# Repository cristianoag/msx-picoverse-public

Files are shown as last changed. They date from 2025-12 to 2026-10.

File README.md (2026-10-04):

# PicoVerse for MSX

**The MSX experience driven by the Raspberry Pi Pico family of microcontrollers.**

PicoVerse is a community-driven effort to build versatile MSX cartridges powered by Raspberry Pi Pico development boards. The project pairs accessible hardware designs with ready-to-flash firmware so MSX users can jump straight into loading games, tools, and Nextor without having to compile sources.

| Cartridge Label - 2040 Variant | Cartridge Label - 2350 Variant |
|---|---|
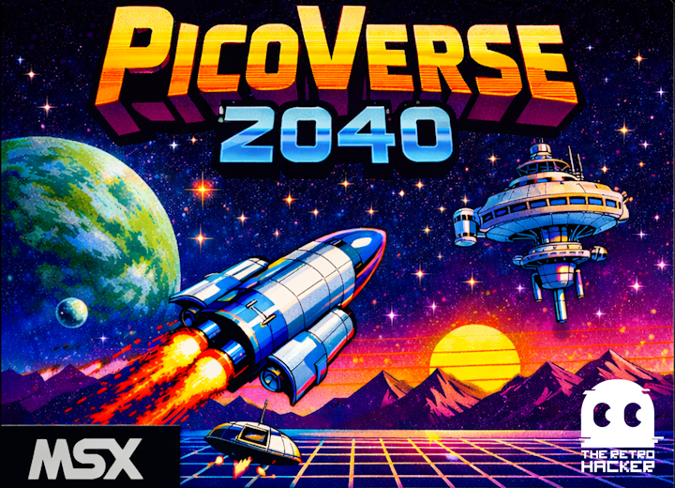
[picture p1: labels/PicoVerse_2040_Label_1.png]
PicoVerse 2040 Label
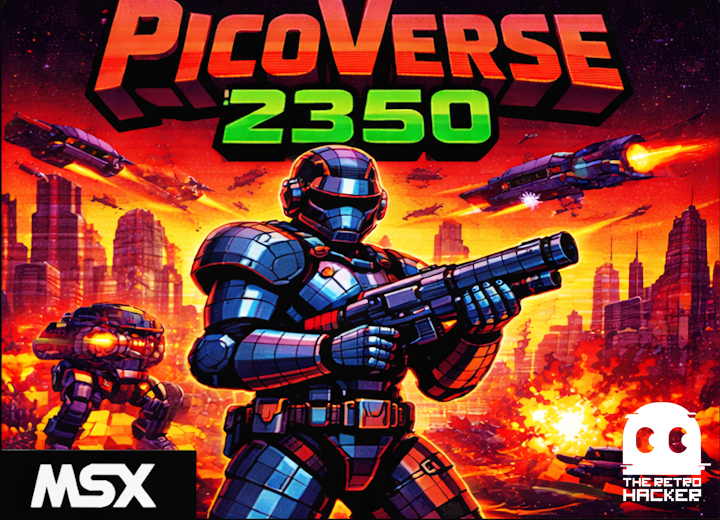
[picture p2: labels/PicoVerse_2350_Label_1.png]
PicoVerse 2350 Label
| |  |

PicoVerse is designed as an open-source, independent, and documented MSX cartridge platform. Compatibility with other projects is neither a goal nor guaranteed (I tested some without much success); running third‑party software on PicoVerse hardware, or PicoVerse firmware on other boards, is at your own risk. The source and manufacturing files are openly available so you can learn, experiment, and build on them for the MSX community, subject to the project license.

If you find any issues, have questions, or want to contribute, please open an issue or reach out via the contact information in the repository.

## Project Highlights

- Single-ROM LoadROM workflow for instant and easy booting of one title.
- Multi-ROM loader with an on-screen menu and mapper auto-detection.
- Explorer firmware (PicoVerse 2350) merges flash ROMs, optional embedded Sunrise Nextor SYSTEM entries, and microSD ROMs, labels the source (FL/SD), adds microSD MP3/WAV playback, supports WAVEGAME microSD ROMs with port `0x92` controlled WAV streaming, supports on-device search, can cycle supported microSD partitions with `P`, can delete selected SD files or flash entries with confirmed `D`, can copy microSD ROMs into the cartridge flash with `F`, can rename ROMs, `.DSK` images and flash entries with `R`, includes ROM detail audio profiles with native and external SCC/SCC+, Dual PSG, MSX-MUSIC, and YM2151/SFG support, adds an independent primary PSG DAC mirror option, and includes an integrated File Hunter browser for downloading ROMs and `.DSK` disk images over ESP-01 WiFi.
- Ready-made Nextor builds with USB pendrive (`-s2`/`-m2`) or FAT16 up-to-4GB microSD partitions (`-s1`/`-m1`) via Sunrise IDE emulation on PicoVerse 2350, and USB (`-s`/`-m`) on PicoVerse 2040.
- Sunrise IDE + 192KB memory mapper on PicoVerse 2040 (`loadrom.exe -m`), or Sunrise IDE standalone (`loadrom.exe -s`).
- Sunrise IDE + 1MB PSRAM memory mapper on PicoVerse 2350 (`loadrom.exe -m1` for microSD, `loadrom.exe -m2` for USB), or Sunrise IDE standalone (`loadrom.exe -s1` / `loadrom.exe -s2`).
- Sunrise IDE + 1MB memory mapper + 1MB MegaRAM on PicoVerse 2350 (`loadrom.exe -r1` / `explorer.exe -r1` for microSD, `loadrom.exe -r2` / `explorer.exe -r2` for USB), exposing 128 × 8KB MegaRAM banks in a dedicated expanded subslot.
- Carnivore2-compatible RAM-mode loader on PicoVerse 2350 (`loadrom.exe -c1` / `loadrom.exe -c2`) for `SROM.COM /D15` uploads into the 1MB PSRAM mapper.
- ESP-01 WiFi support for PicoVerse 2350 Sunrise IDE LoadROM/MultiROM builds (`loadrom.exe -s1 -w`, `-m1 -w`, `-s2 -w`, `-m2 -w`) and for the Explorer File Hunter browser. Compatible with both real MSX hardware and FPGA-based MSX cores.
- SCC/SCC+, Dual PSG, MSX-MUSIC/YM2413, and YM2151/SFG emulation on the PicoVerse 2350, with per-ROM audio profile selection where supported.
- OPL4 / YMF278B / MoonSound emulation on the PicoVerse 2350 (`loadrom.exe -4`) — a standalone sound cartridge with OPL3 FM (18 channels), the 24-voice PCM wavetable, the embedded 2 MB YRW801-M wave ROM, and 2 MB of PCM sample RAM on the standard MoonSound ports.
- MSX-AUDIO / Yamaha Y8950 emulation on the PicoVerse 2350 (`loadrom.exe -a`) — a standalone MSX-AUDIO card with OPL1 FM plus ADPCM, 256 KB of ADPCM sample RAM, and the MSX-Audio BIOS mapped in the cartridge slot.
- Yamanooto flash-cartridge emulation on the PicoVerse 2350 (`yamanooto.exe`) — a Konami-SCC compatible 8 MB flash cartridge with SCC/SCC+, a secondary (dual) PSG, a primary PSG mirror, and MSX-MUSIC/FM-PAC, all always available with the firmware selecting SCC, FM, or pure PSG on the fly so one image can mix SCC, FM, and PSG games.
- PC-side tooling that generates UF2 images locally for quick drag-and-drop flashing.
- openMSX emulated cartridge for PicoVerse 2040 MultiROM — run the same MultiROM `.uf2` in the openMSX emulator before flashing it, with the real PicoVerse menu, the matching ROM mappers, and the embedded Nextor Sunrise IDE entries using a disk image as the USB drive. See [MSX PicoVerse 2040 — MultiROM in openMSX](/docs/msx-picoverse-2040-openmsx.md).
- openMSX emulated cartridge for PicoVerse 2350 Explorer — run an Explorer `.uf2` in openMSX with the real Explorer menu, a PC folder as the microSD card, copy to flash/rename/delete, the Nextor and `.DSK` entries, and the SCC/SCC+, MSX-MUSIC, SFG and Dual PSG audio profiles. See [MSX PicoVerse 2350 — Explorer in openMSX](/docs/msx-picoverse-2350-openmsx.md).
- USB keyboard support on PicoVerse 2040 — use a standard USB keyboard as the MSX keyboard via the cartridge slot.
- MSX-MIDI support on PicoVerse 2040 — use a USB-MIDI cable as a standard MSX-MIDI interface via the cartridge slot. 
- MIDI-PAC support on PicoVerse 2040 — passively convert live MSX PSG music and effects into high-quality MIDI for external synths or sound modules (SC-55 optimized). Features automatic bass detection, tone+noise coexistence, smooth pitch bending on fast passages, and improved percussion mapping. 
- USB joystick support on PicoVerse 2040 — plug a standard USB gamepad (HID, Xbox 360, Xbox One, or Xbox Series X|S) into the USB-C port and it appears as one or two native MSX joysticks with no MSX-side software needed. Uses open-drain bus driving to coexist with the real PSG.
- BOMs, and production-ready Gerbers.
- Active development roadmap covering RP2040 and RP2350-based cartridges.

## Documentation

**LoadROM Guides:** Use the LoadROM tool to create a UF2 image that boots directly into a single ROM, skipping the menu. Mapper type is auto-detected with filename tag overrides, and the tool reports the detected configuration before flashing.
- [MSX PicoVerse 2040 LoadROM Tool Manual (English)](/docs/msx-picoverse-2040-loadrom-tool-manual.en-us.md) 
- [MSX PicoVerse 2350 LoadROM Tool Manual (English)](/docs/msx-picoverse-2350-loadrom-tool-manual.en-us.md) 
  
**MultiROM Guides:** Use the MultiROM tool to create a UF2 image that allows selecting from multiple ROMs at boot. Mapper type is auto-detected with filename tag overrides, and the tool reports the detected configuration before flashing.
- [PicoVerse 2040 MultiROM Guide Manual (English)](/docs/msx-picoverse-2040-multirom-tool-manual.en-us.md)
- [PicoVerse 2350 MultiROM Tool Manual (English)](/docs/msx-picoverse-2350-multirom-tool-manual.en-us.md)

**openMSX Emulated Cartridge:** Try a PicoVerse 2040 MultiROM or PicoVerse 2350 Explorer UF2 in the openMSX emulator before flashing it. A Tcl script and an openMSX extension turn the `.uf2` into an emulated PicoVerse cartridge: the MSX boots the real menu, starts each entry with the matching openMSX hardware, and runs the Nextor Sunrise IDE entries with a hard disk image as the USB drive or microSD card. The Explorer add-on also uses a PC folder as the microSD card.
- [MSX PicoVerse 2040 — MultiROM in openMSX (English)](/docs/msx-picoverse-2040-openmsx.md)
- [MSX PicoVerse 2350 — Explorer in openMSX (English)](/docs/msx-picoverse-2350-openmsx.md)

**Explorer Guides:** Use the Explorer tool to manage flash, embedded Sunrise Nextor, and microSD ROMs, boot 360 KB/720 KB `.DSK` disk images (and multi-disk games joined into one `.DSK`, swapped with the number keys) from the microSD card, cycle supported microSD partitions, delete selected SD files or flash entries, copy microSD ROMs to flash, rename ROMs and disk images, play MP3/WAV files from the microSD card, browse File Hunter over ESP-01 WiFi, select ROM audio/PSG options, and search for titles on the device.
- [MSX PicoVerse 2350 Explorer Tool Manual (English)](/docs/msx-picoverse-2350-explorer-tool-manual.en-us.md)

**Yamanooto Guides:** Use the Yamanooto tool to create a UF2 that emulates a Yamanooto flash cartridge (Konami-SCC compatible, SCC/SCC+, dual PSG, primary PSG mirror, and MSX-MUSIC/FM-PAC) from a single ROM image, with the firmware choosing SCC/FM/PSG automatically at runtime.
- [MSX PicoVerse 2350 Yamanooto Tool Manual (English)](/docs/msx-picoverse-2350-yamanooto-tool-manual.en-us.md)

**Reference Material** 
- [PicoVerse 2040 Features Overview](/docs/msx-picoverse-2040-features.md)
- [PicoVerse 2350 Features Overview](/docs/msx-picoverse-2350-features.md)
- [MSX PicoVerse 2350 Dual PSG Implementation](/docs/msx-picoverse-2350-dualpsg.md)
- [MSX PicoVerse 2350 MSX-MUSIC/FM-PAC Implementation](/docs/msx-picoverse-2350-fmpac.md)
- [MSX PicoVerse 2350 50/60Hz CPU Speed Implementation](/docs/msx-picoverse-2350-50-60hz.md) 
- [MSX PicoVerse 2350 CPU Speed Implementation](/docs/msx-picoverse-2350-cpu-speed.md)
- [MSX PicoVerse 2350 Yamanooto Implementation](/docs/msx-picoverse-2350-yamanooto.md)
- [MSX PicoVerse 2350 MegaRAM Implementation](/docs/msx-picoverse-2350-megaram.md)
- [MSX PicoVerse 2350 WAVEGAME Protocol and Support](/docs/msx-picoverse-2350-wavegame.md)
- [MSX PicoVerse 2350 WiFi Support](/docs/msx-picoverse-2350-wifi.md)
- [MSX PicoVerse 2040 PIO Strategy](/docs/msx-picoverse-2040-pio.md) 
- [MSX PicoVerse 2350 PIO Strategy](/docs/msx-picoverse-2350-pio.md) 
- [MSX PicoVerse 2350 SCC Emulation](/docs/msx-picoverse-2350-scc.md)
- [MSX PicoVerse 2040 Sunrise IDE Emulation for Nextor](/docs/msx-picoverse-2040-sunrise-nextor.md) 
- [MSX PicoVerse 2350 Sunrise IDE Emulation for Nextor](/docs/msx-picoverse-2350-sunrise-nextor.md) 
- [MSX PicoVerse 2350 DSK Disk Image Support](/docs/msx-picoverse-2350-dsk-support.md)
- [MSX PicoVerse 2040 Mapper Implementation (Sunrise + Nextor)](/docs/msx-picoverse-2040-mapper.md) 
- [MSX PicoVerse 2040 USB Keyboard](/docs/msx-picoverse-2040-keyboard.md)
- [MSX PicoVerse 2040 MSX-MIDI](/docs/msx-picoverse-2040-msx-midi.md) 
- [MSX PicoVerse 2040 MIDI-PAC](/docs/msx-picoverse-2040-midipac.md)
- [MSX PicoVerse 2040 MegaROMs](/docs/msx-picoverse-2040-megaroms.md)
- [MSX PicoVerse 2040 USB Joystick](/docs/msx-picoverse-2040-joystick.md)

## Hardware Variants

### PicoVerse 2040 Cartridge

| Prototype PCB (front) | Prototype PCB (back) |
|---|---|
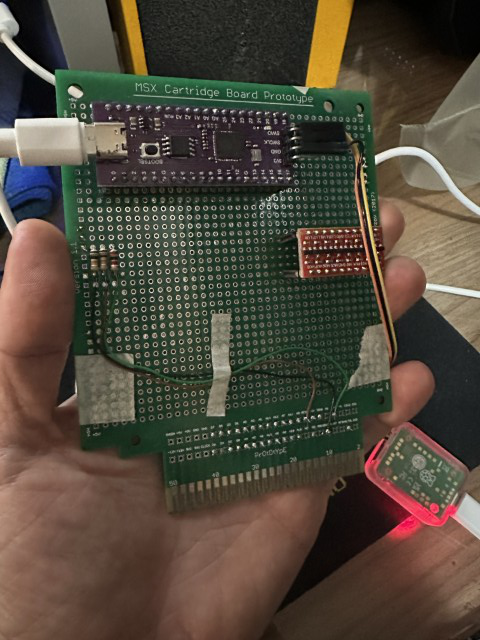
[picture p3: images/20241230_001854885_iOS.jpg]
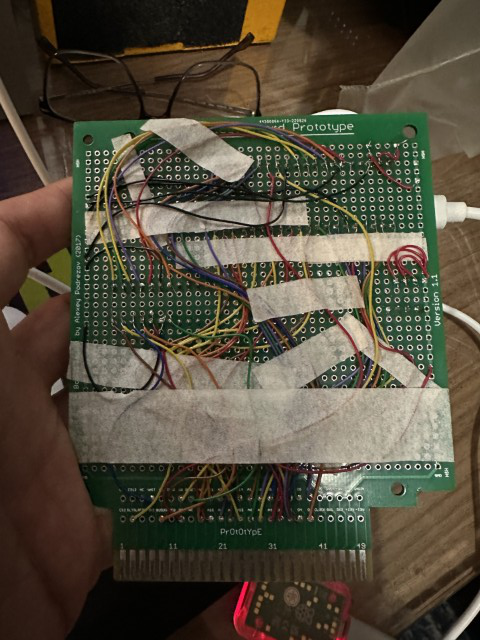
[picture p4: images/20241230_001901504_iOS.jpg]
|  |  | 

- Based on RP2040 boards exposing 30 GPIO pins (not compatible with stock Raspberry Pi Pico pinout).
- Up to 16 MB of flash for MSX ROMs with support for Plain16/32 (`PLA-16`/`PLA-32`), Planar48/64 (`PLN-48`/`PLN-64`), Konami SCC, Konami, ASCII8/16/16X, NEO-8, NEO-16, and Manbow2 (`MANBW2`) mappers.
- USB-C port doubles as a bridge for Nextor mass storage via Sunrise IDE emulation (`loadrom.exe -s`).
- Sunrise IDE + 192KB memory mapper mode provides both Nextor disk access and expanded RAM (`loadrom.exe -m`).
- Standalone USB keyboard firmware — use a standard USB keyboard as the MSX keyboard via the cartridge slot (`loadrom.exe -k`). Not compatible with FPGA-based MSX systems or MSX computers with an integrated PPI (e.g. T9769 MSX-ENGINE).
- Standalone MSX-MIDI firmware — use a USB-MIDI cable as a standard MSX-MIDI interface for MIDI players and sequencers (`loadrom.exe -i`).
- Standalone MIDI-PAC firmware — passively listen to the MSX PSG and convert music and effects to USB MIDI for an external synth or sound module (`loadrom.exe -p`).
- Standalone USB joystick firmware — use a standard USB gamepad as an MSX joystick via the cartridge slot (`loadrom.exe -j`). Supports Xbox 360, Xbox One, Xbox Series X|S, and generic USB HID gamepads, with up to 2 gamepads mapped to MSX joystick ports 1 and 2.  Not compatible with FPGA-based MSX systems or MSX computers with an integrated PSG (e.g. T9769 MSX-ENGINE).

#### Bill of Materials



Interactive BOM available at [PicoVerse 2040 BOM](https://htmlpreview.github.io/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)

| Reference | Description | Quantity | Link |
| --- | --- | --- | --- |
| U1 | RP2040 Dev Board 30 GPIO pins exposed | 1 | [AliExpress](https://s.click.aliexpress.com/e/_c2un4bmn) |
| C1 | 0603 0.1 µF Ceramic Capacitor | 1 | [AliExpress](https://s.click.aliexpress.com/e/_c2w5e36V) |
| C2 | 0603 10 µF Ceramic Capacitor | 1 | [AliExpress](https://s.click.aliexpress.com/e/_c2w5e36V)|
| R2, R3, R4, R5, R6, R7, R8, R9, R10, R11, R12, R13| 0603 10 kΩ Resistor | 12 | [AliExpress](https://s.click.aliexpress.com/e/_c3XBv4od)|
| R1 | 0603 2 KΩ Resistor | 1 | [AliExpress](https://s.click.aliexpress.com/e/_c3XBv4od)|
| D1 | 1N5819 SOD-123 Diode | 1 | [AliExpress](https://s.click.aliexpress.com/e/_c4WEKCuz) |
| Q1, Q2, Q3, Q4, Q5 | BSS138 SOT-23 Transistor | 5 | [AliExpress](https://s.click.aliexpress.com/e/_c3IHdO5t)|

### PicoVerse 2350 Cartridge

| Prototype PCB (front) | Prototype PCB (back) |
|---|---|
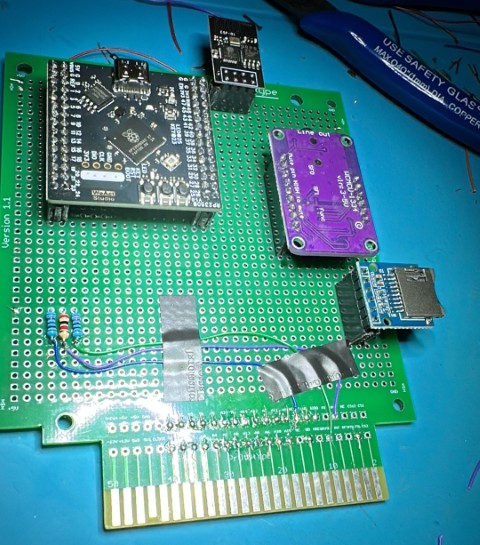
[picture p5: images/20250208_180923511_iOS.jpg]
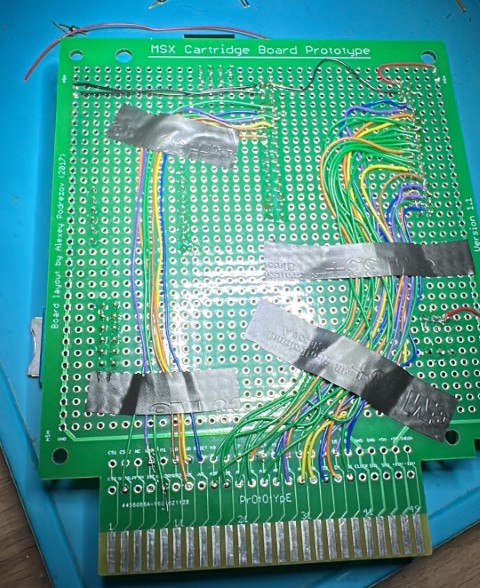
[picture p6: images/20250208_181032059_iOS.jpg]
|  |  |

- Targets RP2350 boards exposing all 48 GPIO pins (not compatible with standard Pico 2 boards).
- Adds microSD storage, ESP8266 WiFi header, and I2S audio expansion alongside 16 MB flash space.
- Extra RAM (PSRAM) now backs the 1MB mapper modes and the Carnivore2-compatible RAM loader, with room for additional advanced firmware features.
- Explorer firmware can load ROMs from flash, optional embedded Sunrise Nextor SYSTEM entries, and microSD, cycle FAT16/FAT32/exFAT microSD browsing partitions with `P`, delete selected SD files or flash entries after confirmation with `D`, copy microSD ROMs into flash with `F`, rename ROMs, `.DSK` images and flash entries with `R`, play MP3/WAV files from microSD, browse File Hunter over ESP-01 WiFi, save downloaded File Hunter ROMs and `.DSK` disk images to the microSD root, search local title lists, select native or external SCC/SCC+, Dual PSG, MSX-MUSIC, or YM2151/SFG audio profiles per ROM where supported, and optionally mirror primary PSG audio through the cartridge DAC.
- USB-C port doubles as a bridge for Nextor mass storage via Sunrise IDE emulation (`-s2`).
- microSD card slot provides Nextor mass storage via Sunrise IDE emulation (`-s1`) when using FAT16 partitions up to 4 GB.
- Sunrise IDE + 1MB PSRAM memory mapper mode provides both Nextor disk access and expanded RAM (`-m1` for microSD, `-m2` for USB).
- Sunrise IDE + 1MB mapper + 1MB MegaRAM mode provides Nextor disk access, standard mapper RAM, and a separate writable MegaRAM cartridge surface (`-r1` for microSD, `-r2` for USB).
- Carnivore2-compatible RAM-mode loading lets `SROM.COM /D15` upload ROMs into the 1MB PSRAM mapper (`-c1` for microSD, `-c2` for USB).
- Yamanooto flash-cartridge emulation (`yamanooto.exe`) reproduces the  Yamanooto: a Konami-SCC compatible 8 MB flash cartridge with SCC/SCC+, a secondary (dual) PSG on ports `0x10`/`0x11`, a primary PSG mirror (`0xA0`/`0xA1`), and MSX-MUSIC/FM-PAC via an expanded subslot. All engines are always available and the firmware selects SCC, FM, or pure PSG on the fly, so a single image can hold a mix of SCC, FM, and PSG games.
- Standalone OPL4 / YMF278B / MoonSound cartridge firmware (`loadrom.exe -4`): full YMF278B emulation (OPL3 FM with 18 channels plus 24 PCM voices), the 2 MB YRW801-M wave ROM embedded in the UF2, 2 MB of PCM sample RAM in PSRAM, MoonSound ports `0xC4`-`0xC7` and `0x7E`/`0x7F`, FM timer interrupts on `/INT`, and 16-bit stereo 44.1 kHz output through the I2S DAC. Optional `--22khz` reduced-rate build for extreme-polyphony songs.
- Standalone MSX-AUDIO / Yamaha Y8950 cartridge firmware (`loadrom.exe -a`): OPL1 FM (9 channels) plus ADPCM-B, 256 KB of ADPCM sample RAM in PSRAM, the 48 KB MSX-Audio BIOS v1.3 mapped in the slot (openMSX `Boosted_audio.xml` layout, with base and expanded work RAM), ports `0xC0`/`0xC1`, FM timer interrupts on `/INT`, and 16-bit 49716 Hz output through the I2S DAC. Optional `--4mhz` Y8950 clock.
- LoadROM Sunrise builds can also expose ESP-01 WiFi support with `-w` on top of the `-s1`/`-m1`/`-s2`/`-m2` modes.
- LoadROM, MultiROM, and Explorer support the Sunrise IDE options. MultiROM and Explorer allow combining them so multiple Nextor modes appear as selectable SYSTEM entries in the menu, and both provide `-a` / `--allnextor` to add all embedded Nextor entries while still appending folder ROMs. All three also offer `-s3` for testing the Nextor 3.0.0 Beta 2 kernel over microSD.
- Shares the same ROM mapper support list as the 2040 build.

#### Bill of Materials



Interactive BOM available at [PicoVerse 2350 BOM](https://htmlpreview.github.io/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) 

| Reference | Description | Quantity | Link |
| --- | --- | --- | --- |
| U1 | WaveShare Core2350B Dev Board 48 GPIO pins exposed (8Mb PSRAM)| 1 | [AliExpress](https://pt.aliexpress.com/item/1005009578742534.html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) |
|U2| UDA1334A I2S Stereo DAC| 1 | [AliExpress](https://s.click.aliexpress.com/e/_c3gam5lH) |
|U3| ESP-01 ESP8266 WiFi Module| 1 | [AliExpress](https://s.click.aliexpress.com/e/_c3cPt2OL) |
|C1| 0603 0.1 µF Ceramic Capacitor | 1 | [AliExpress](https://s.click.aliexpress.com/e/_c3tkUxHz) |
|C2,C3| 0603 10 µF Ceramic Capacitor | 2 | [AliExpress](https://s.click.aliexpress.com/e/_c3tkUxHz)|
|R1| 0603 2 KΩ Resistor | 1 | [AliExpress](https://s.click.aliexpress.com/e/_c43uKcEj)|
|R2, R3, R6, R7, R8| 0603 10 kΩ Resistor | 4 | [AliExpress](https://s.click.aliexpress.com/e/_c43uKcEj)|
|R4, R5| 0603 5.1 kΩ Resistor | 2 | [AliExpress](https://s.click.aliexpress.com/e/_c43uKcEj)|
|R9, R10| 0603 330 Ω Resistor | 2 | [AliExpress](https://s.click.aliexpress.com/e/_c43uKcEj)|
|D1| 1N5819 SOD-123 Diode | 1 | [AliExpress](https://s.click.aliexpress.com/e/_c4WEKCuz) |
|SW1| Tactile Push Button Switch | 1 | [AliExpress](https://s.click.aliexpress.com/e/_c2IPGkzv) |
|J1| USB-C 16 Pin Connector | 1 | [AliExpress](https://s.click.aliexpress.com/e/_c4PtBc51) |
|J2| microSD Card Slot | 1 | [AliExpress](https://s.click.aliexpress.com/e/_c4Pzbd7Z) |

## Repository Contents
- `hardware/` – Production-ready Gerbers, fabrication notes, and BOMs for each supported dev board.
- `software/` – MultiROM PC utilities (`multirom.exe`) and menu ROM assets for both cartridge families.
- `docs/` – Feature lists, usage walkthroughs, and revision history for each cartridge family.
- `images/` – Board renders and build photos for quick identification.
- `labels/` – Printable Patola style cartridge label designs for both hardware variants.

## Quick Start
1. **Pick your target board**: Select the hardware revision that matches the RP2040 or RP2350 carrier you own, then grab the corresponding Gerber/BOM pack.
2. **Manufacture or assemble**: Send the Gerbers to your PCB house or build from an ordered kit. Follow the assembly notes included in each hardware bundle.
3. **Generate the UF2 image**:
   - For multiple titles, place your `.rom` files beside the MultiROM tool for your cartridge family (`2040/software/multirom.pio/tool/multirom.exe` or `2350/software/multirom.pio/tool/multirom.exe`) and run `multirom.exe` to create `multirom.uf2`.
   - For an instant boot into a single game, place the desired `.rom` next to the LoadROM tool for your cartridge family and run `loadrom.exe <file> [-o custom.uf2]` to create a dedicated UF2 that skips the menu.
   - For a combined flash + microSD menu (on PicoVerse 2350 only), use the Explorer tool (`2350/software/explorer.pio/tool/explorer.exe`) to create `explorer.uf2`. Add options such as `-s1`, `-m1`, `-r1`, `-s2`, `-m2`, `-r2`, or `-a` / `--allnextor` when you want embedded Nextor SYSTEM entries in the same Explorer menu, then copy extra `.rom` and `.mp3` files to the microSD card. With an ESP-01 module and configured WiFi, Explorer can also browse File Hunter and save downloaded ROMs directly to the microSD root.
4. **Flash the firmware**:
   - Hold BOOTSEL while connecting the cartridge to your PC via USB-C.
   - Copy the freshly generated UF2 (`multirom.uf2`, `loadrom.uf2`, or `explorer.uf2`) to the RPI-RP2 drive that appears.
   - Eject the drive; the board reboots and stores the image in flash.
5. **Enjoy on MSX**: Insert the cartridge, power on the computer, pick a ROM from the menu, or launch Nextor to access USB or microSD storage.

## MultiROM Menu

| PicoVerse 2040 MultiRom | PicoVerse 2350 MultiRom |
|---|---|
|PicoVerse 2040 MultiROM menu|PicoVerse 2350 MultiROM menu|

To use the MultiROM menu, insert the PicoVerse cartridge into your MSX and power it on. The system will boot directly into the MultiROM menu, which displays a list of all ROMs embedded in the cartridge. Each entry is named after the ROM filename (up to 50 characters), and longer names are shown using a scrolling effect.

Navigate the menu using the keyboard arrow keys. Use the Up and Down keys to move through the list of ROMs, and if more than 19 ROMs are present, use the Left and Right keys to switch between pages. To start a game or application, select it and press Enter or Space; the MSX will boot the ROM using the appropriate mapper configuration automatically.

While in the menu, pressing a letter key jumps to the first ROM whose name starts with that letter, and pressing F1 opens a help screen with basic instructions; press any key to return to the main menu. Once a ROM is launched, control is handed over entirely to the selected software, just as if it were a physical cartridge inserted into the MSX.

Check the detailed MultiROM guide in the documentation folder for advanced features, troubleshooting tips, and mapper support details.

You can also try a PicoVerse 2040 MultiROM UF2 in the openMSX emulator before flashing it: the emulated cartridge boots the same menu from the `.uf2` file. See [MSX PicoVerse 2040 — MultiROM in openMSX](/docs/msx-picoverse-2040-openmsx.md).

## LoadROM Tool

The LoadROM tool targets situations where you want the PicoVerse to behave like a traditional single-game cartridge or as a dedicated standalone firmware image. Instead of showing the MultiROM menu, the Pico boots straight into one ROM embedded in the UF2 image, or into a selected standalone mode such as keyboard, MSX-MIDI, MIDI-PAC, or USB joystick.

- **Input**: exactly one `.ROM` file. Mapper type is auto-detected with the same heuristics as MultiROM, and you can still force a mapper via filename tags such as `.KonSCC.ROM` or `.PLA-32.ROM`.
- **Output**: `loadrom.uf2` by default, or any filename you pass via `-o`. The UF2 contains the firmware, a 59-byte configuration record (title, mapper, size, flash offset), and the ROM payload.
- **Workflow**:
   1. Open a Command Prompt or PowerShell window in your target package folder:
      - `2040/software/loadrom.pio/tool`, or
      - `2350/software/loadrom.pio/tool`.
   2. Run `loadrom.exe -o mygame.uf2 \\path\\to\\Game.ROM` (the tool also accepts drag-and-drop onto the EXE).
      - MSX-MIDI standalone mode: `loadrom.exe -i -o midi.uf2`
      - MIDI-PAC standalone mode: `loadrom.exe -p -o midipac.uf2`
      - USB joystick standalone mode: `loadrom.exe -j -o joystick.uf2`
      - SCC standard emulation (only PicoVerse 2350): `loadrom.exe -scc \\path\\to\\Game.ROM`
      - SCC+ enhanced emulation (only PicoVerse 2350): `loadrom.exe -sccplus \\path\\to\\Game.ROM`
      - MSX-MUSIC/FM-PAC emulation with the bundled English FM-PAC BIOS (only PicoVerse 2350, non-SYSTEM ROMs): `loadrom.exe -f \\path\\to\\Game.ROM`, `loadrom.exe -fmpac \\path\\to\\Game.ROM`, or `loadrom.exe --fmpac -o mygame-fmpac.uf2 \\path\\to\\Game.ROM`
      - Dual PSG emulation on secondary PSG ports `0x10`/`0x11` (only PicoVerse 2350, supported non-SYSTEM ROMs): `loadrom.exe -d \\path\\to\\Game.ROM` or `loadrom.exe --dual-psg -o mygame-dualpsg.uf2 \\path\\to\\Game.ROM`
      - `-scc` and `-sccplus` are mutually exclusive.
      - `-scc`, `-sccplus`, `-f` / `-fmpac`, and `-d` / `--dual-psg` are cartridge audio modes; use only one of them per UF2.
      - `-f` / `-fmpac` is not valid with Sunrise, Carnivore2, or MegaRAM system modes (`-s1`, `-m1`, `-s2`, `-m2`, `-c1`, `-c2`, `-r1`, or `-r2`) or with Konami SCC / Manbow2 mapper ROMs.
      - `-d` / `--dual-psg` is intended for software that writes to a second PSG. It is not available for Konami SCC or Manbow2 mapper ROMs, SCC/SCC+ audio builds, Sunrise/Nextor system modes, Carnivore2 system modes, or MegaRAM system modes.
      - Sunrise IDE standalone (PicoVerse 2040): `loadrom.exe -s`
      - Sunrise IDE + 192KB mapper (PicoVerse 2040): `loadrom.exe -m`
      - Sunrise IDE standalone (PicoVerse 2350): `loadrom.exe -s1` or `loadrom.exe -s2`
      - Nextor 3.0.0 Beta 2 for testing (PicoVerse 2350, microSD): `loadrom.exe -s3`
      - Sunrise IDE + 1MB PSRAM mapper (PicoVerse 2350): `loadrom.exe -m1` or `loadrom.exe -m2`
      - Sunrise IDE + 1MB PSRAM mapper + 1MB MegaRAM (PicoVerse 2350): `loadrom.exe -r1` or `loadrom.exe -r2`
      - Sunrise IDE + WiFi (PicoVerse 2350): `loadrom.exe -s1 -w`, `loadrom.exe -s2 -w`, `loadrom.exe -m1 -w`, or `loadrom.exe -m2 -w`
      - Carnivore2-compatible RAM loader (PicoVerse 2350): `loadrom.exe -c1` or `loadrom.exe -c2`
      - OPL4 / MoonSound standalone cartridge (PicoVerse 2350, no ROM file): `loadrom.exe -4`, optionally with `--22khz`
      - MSX-AUDIO / Y8950 standalone cartridge (PicoVerse 2350, no ROM file): `loadrom.exe -a`, optionally with `--4mhz`
      - `-4` and `-a` are standalone builds: they take no ROM file and cannot be combined with each other or with any other mode or audio flag.
      - `-w` is currently supported only with `-s1`, `-m1`, `-s2`, `-m2`, or `-s3`.
   3. Observe the reported ROM name, size, mapper status (auto vs forced), and Pico offset before the UF2 is written.
   4. Put the Pico into BOOTSEL mode and copy the generated UF2 to the `RPI-RP2` drive.
   5. Insert the cartridge into your MSX—on power-up the embedded game launches immediately.

Consult the LoadROM manuals linked above for screenshots, troubleshooting, and in-depth explanations of mapper forcing, UF2 structure, and limitations.

## Explorer Firmware (RP2350)

|Explorer Flash Menu|Explorer MicroSD Menu|
|---|---|
|Explorer flash menu|Explorer microSD menu|
|<center>**File Hunter Explorer Menu**|<center>**WiFi Configuration Screen**|
|File Hunter Explorer menu|WiFi configuration screen|

Explorer is a PicoVerse 2350-only firmware that merges ROMs stored in flash, optional embedded Sunrise Nextor SYSTEM entries, and additional ROMs and MP3/WAV files on the microSD card. ROMs are labeled with source tags (FL/SD), MP3 and WAV entries open a player screen with Play/Stop and Pause/Resume controls, the list supports paging, and you can search by name directly in the menu. Explorer can add individual Nextor entries with `-s1`, `-m1`, `-c1`, `-r1`, `-s2`, `-m2`, `-c2`, or `-r2`, or add all of them with `-a` / `--allnextor`, while still appending supported folder ROMs to the UF2. For early testing of Nextor 3, `-s3` adds a `Nextor Sunrise 3.0.0 Beta 2 (SD)` microSD entry (also included by `-a`). In the `F2` microSD screen, `P` cycles supported FAT16, FAT32, and exFAT browsing partitions, while `D` deletes the selected file after confirmation (folders are protected) and `F` copies the selected ROM into the cartridge flash, where it then appears in the `F1` list; `D` in the `F1` flash screen removes a flash entry. `R` renames the selected ROM, `.DSK` image or flash entry; on the microSD card the mapper tag and extension of the file name are kept. With an ESP-01 / ESP8266 module installed and WiFi configured, pressing `F3` opens the integrated File Hunter browser. File Hunter results show the name and size, can be searched from the MSX, and `T` switches between the ROM and `.DSK` catalogs. Selected ROMs and disk images are downloaded through the Pico into PSRAM before being saved as `.ROM` or `.DSK` files in the microSD root. microSD ROMs up to 4 MB can be executed directly from there. Use the Explorer tool to build the UF2 and copy extra ROMs and audio files to the microSD card. See the Explorer manual for limits, File Hunter requirements, and supported formats.

For Sunrise Nextor SYSTEM entries in Explorer, SD storage is limited to FAT16 microSD partitions up to 4 GB. If more than one compatible partition exists, choose the desired one from the ROM detail screen's `SD Part` option; Explorer saves that selection in the ROM's `.PVC` options file. FAT32 and exFAT partitions remain supported for normal Explorer file browsing but are not offered to Nextor. Nextor entries always show the Nextor version in the menu, for example `Nextor Sunrise 2.1.4 (SD)` or `Nextor Sunrise 2.1.4 + 1MB Mapper (USB)`.

Starting with Explorer v2.52, the menu also lists `.DSK` floppy disk images found on the microSD card, with the `DSK` type label, and can boot the MSX from them. The image is loaded into the cartridge's PSRAM and served to the MSX as the disk of an emulated Sunrise IDE interface. That interface runs the Nextor Sunrise 2.1.4 kernel, which every Explorer UF2 now embeds as a hidden payload, so no extra build option is needed. Disks with an MSX-DOS 1 boot sector start in MSX-DOS 1 mode automatically. Game saves and other disk writes are written straight through to the `.DSK` file on the card.

Multi-disk games are supported since Explorer v2.53 by joining their disks, in order, into one `.DSK` file (for example `copy /b "GAME (Disk 1).DSK" + "GAME (Disk 2).DSK" GAME.DSK`). Explorer finds the disks inside the file and boots disk 1 in Nextor's disk emulation mode. When the game asks for another disk, press that disk's number key (`1`–`9`, then `A`–`W`), for example `2` + `SPACE` for "insert disk 2 and press space". Current limitations:
- The file size must be a multiple of 360 KB (360 KB and 720 KB disks), up to 11 × 360 KB or 5 × 720 KB + 360 KB.
- Multi-disk files always boot MSX-DOS 1. Press the disk key when the game asks for the disk, not while it is loading.
- No floppy controller is emulated, so copy-protected disks and software that programs the FDC directly will not work.
- Nextor uses more RAM than a plain disk ROM. On machines with little RAM (for example a 64 KB MSX2+ such as the Panasonic FS-A1FX), turn on the DSK entry's `1MB Mapper` option to boot it with Nextor plus the 1 MB PSRAM memory mapper.
- An image boots read-only if the file is marked read-only or is split into more than 16 fragments on the card.
- DSK entries offer PSG Mirror, `1MB Mapper`, and the same cartridge audio profiles as the Nextor Sunrise entries. Since v2.55: **External SCC** / **External SCC+** and **MSX-MUSIC**. Since v2.56: **YM2164 SFG05** / **YM2151 SFG01** (and their 4 MHz variants) and **Dual PSG**. The SCC, FM-PAC and SFG appear as a virtual cartridge in expanded subslot 2; Dual PSG uses I/O ports `10h`/`11h`.

See [MSX PicoVerse 2350 DSK Disk Image Support](/docs/msx-picoverse-2350-dsk-support.md) for the full design, the multi-disk layout, the write-through details, and the test matrix.

You can have up to 1024 entries per folder view (folders + ROMs + DSKs + MP3s; the root view can also include flash entries). The menu auto-detects whether the MSX supports 80-column text mode and boots accordingly; you can also press `C` at any time to toggle between 40- and 80-column layouts.

Explorer ROM entries open a detail screen where you can inspect mapper detection, choose a cartridge audio profile, and toggle **PSG** mirroring. Konami SCC and Manbow2 ROMs can use SCC/SCC+ profiles. For other supported non-SYSTEM ROMs, select **Dual PSG** to enable the second cartridge-side PSG on ports `0x10` and `0x11`, **MSX-MUSIC** to enable YM2413/FM-PAC audio, external **SCC/SCC+** to expose a virtual SCC cartridge in another subslot, or **YM2151 (SFG05/SFG01)** to expose a virtual Yamaha SFG-style YM2151 cartridge in a secondary subslot while the game mapper remains active. Supported Sunrise Nextor SYSTEM entries can also select external **SCC/SCC+** or **YM2151 (SFG05/SFG01)**; Explorer keeps Nextor storage and mapper RAM availability intact and places the added cartridge surface in a free expanded subslot. MegaRAM Nextor entries reserve their expanded layout for Nextor, mapper RAM, and MegaRAM, so WiFi and the external SCC/SCC+, Dual PSG and YM2151 profiles are not offered for those entries; PSG Mirror and MSX-MUSIC remain available. Set **PSG: Yes** to also mirror the normal primary PSG ports `0xA0`/`0xA1` through the cartridge DAC; this primary PSG mirror can be mixed with SCC/SCC+, Dual PSG, MSX-MUSIC, YM2151/SFG, or WAVEGAME WAV playback. When **Dual PSG** and **PSG: Yes** are enabled together, Explorer routes Dual PSG to the left channel and the mirrored primary PSG to the right channel. Explorer hides cartridge audio profiles where the cartridge audio slot is reserved, including folders and File Hunter folder records.

WAVEGAME support is available for microSD-launched game ROMs that keep their audio sidecars in the same folder. The running MSX game writes one-byte commands to I/O port `0x92`; Explorer captures those writes while serving the ROM and streams `NN.wav`, `multi.wav`, or `pause.wav` files from the microSD card through the I2S DAC. The protocol supports stop/fade-out, play once, loop, pause toggle, pause music, previous-song resume with fade-in, deferred next-command playback, optional per-song `.cfg` sample offsets, and `multi.wav` fallback offsets. WAVEGAME titles should use 48 kHz mono 16-bit PCM WAV files. When Explorer detects WAVEGAME sidecars next to a ROM, cartridge audio profiles are forced to `None` because they are incompatible with the WAVEGAME streaming path; the separate **PSG Mirror** option remains available and is mixed into the WAVEGAME WAV output.

A search function is available by pressing `/` in the menu. Type part of a ROM name and press Enter to jump to the first matching entry. Press `H` to view the help screen.

The File Hunter browser was implemented with reference to NataliaPC's public MSX File Hunter Browser project: https://github.com/nataliapc/msx_filehunterbrowser

## Compatibility & Requirements

- Works with MSX, MSX2, MSX2+, and MSX TurboR systems. Mapper support covers the most common game and utility formats.
- Requires Windows OS to run the PC-side UF2 builder utilities.
- Ensure your development board matches the pinout documented for each hardware revision before soldering.

## License, Copyright notes & Usage

Creative Commons Attribution-NonCommercial-ShareAlike 4.0

All hardware and firmware binaries in this repository are released under the Creative Commons Attribution-NonCommercial-ShareAlike 4.0 International license. Personal builds and community tinkering are encouraged, but **commercial use or resale requires explicit authorization from the author**.

**bios.h** is used on all MSX menus and was adapted from http://www.konamiman.com/msx/msx2th/th-ap.txt by Danilo Angelo, 2020. The original file is licensed under CC0 1.0 Universal (public domain). The adapted bios.h file in this repository is also released under CC0 1.0 Universal, allowing for free use and modification without restrictions.

**msxromcrt0.s** is used on Nextor C implementation and was adapted by S0urceror, 2022, from the crt0.s file available in FusionC v2.0. The original crt0.s file is licensed under the MIT License. The adapted msxromcrt0.s file in this repository is also released under the MIT License, permitting free use, modification, and distribution with proper attribution.

**uf2format.h** is used in all UF2 builder tools and was adapted from the UF2 specification and reference implementation available at https://github.com/Microsoft/uf2/blob/master/uf2.h. The original uf2.h is copyright by Microsoft Corp and the file is licensed under the MIT License. The adapted uf2format.h file in this repository is also released under the MIT License, allowing for free use, modification, and distribution with proper attribution.

**sha1.h** provides the minimal SHA-1 implementation used by the PicoVerse PC tools. It is based on Steve Reid's public-domain SHA-1 implementation <sreid@sea-to-sky.net>.

**emu2212.c** and **emu2212.h** used to implement SCC and SCC+ emulation are copyright by Mitsutaka Okazaki 2014 and licensed under the MIT License, allowing for free use, modification, and distribution with proper attribution. [emu2212 @ Digital Sound Antiques](https://github.com/digital-sound-antiques/emu2212)

**emu2149.c** and **emu2149.h** used to implement AY-3-8910 emulation/dual PSG feature are copyright by Mitsutaka Okazaki 2014 and licensed under the MIT License, allowing for free use, modification, and distribution with proper attribution. [emu2149 @ Digital Sound Antiques](https://github.com/digital-sound-antiques/emu2149)

**emu2413.c** and **emu2413.h** used to implement YM2413 / MSX-MUSIC emulation are copyright by Mitsutaka Okazaki 2020 and licensed under the MIT License, allowing for free use, modification, and distribution with proper attribution. [emu2413 @ Digital Sound Antiques](https://github.com/digital-sound-antiques/emu2413)

**The YM2151 / Yamaha SFG audio backend** uses the `ymfm` Yamaha FM sound cores by Aaron Giles, licensed under the BSD 3-Clause License. PicoVerse vendors the OPM/YM2151 subset under `2350/software/explorer.pio/pico/explorer/ymfm/` and wraps it with `emu2151.cpp` / `emu2151.h` so the Explorer SFG register implementation can use the same internal `OPM_*` API. [ymfm](https://github.com/aaronsgiles/ymfm)

**The Yamaha SFG01/SFG05 cartridge** behavior was implemented using public technical references including the RBSC SFG_Cartridge project and openMSX's Yamaha SFG implementation. PicoVerse exposes an SFG-like memory-mapped register window in a secondary expanded subslot, queues complete YM2151 register/value writes for the audio core. `SFG_64K.ROM` is bundled as a hidden Explorer flash payload for the YM2151/SFG profiles; the first 32K image is exposed for SFG05 and the second 32K image is exposed for SFG01. The SFG BIOS ROMs were created by Yamaha Corporation and must be treated as third-party copyrighted BIOS payloads. 

**The openMSX emulated cartridges for PicoVerse 2040 MultiROM and PicoVerse 2350 Explorer** (`2040/software/multirom.pio/openmsx` and `2350/software/explorer.pio/openmsx`) were created based on the public openMSX reference: the [openMSX manuals](https://openmsx.org/manual/) (console commands, Tcl scripting, hardware configuration XML, and `diskmanipulator`) and the [openMSX source code](https://github.com/openMSX/openMSX). They are add-ons written in openMSX's Tcl scripting language plus extension configurations; they do not include, modify, or redistribute openMSX code, and they rely on openMSX's own ROM mapper, Sunrise IDE, IDE hard disk, memory mapper, MegaRAM, SCC/SCC+, FM-PAC, Yamaha SFG and PSG implementations. openMSX is licensed under the GNU GPL v2 or later and is developed by the openMSX team; these add-ons are not affiliated with or endorsed by the openMSX project. Unlike the rest of PicoVerse, the add-on files (the Tcl scripts, the extension configurations, the 2040 placeholder ROM source and the 2350 ROM database generator) are licensed under the GNU GPL v2 or later, so they can be contributed to openMSX.

**WAVEGAME support on PicoVerse 2350 Explorer** implements the WAVEGAME idea and protocol authored by Jeroen Taverne and Mauricio Braga. PicoVerse keeps its own RP2350 Explorer implementation for ROM serving, port `0x92` command capture, WAV streaming, and optional PSG Mirror mixing. Implementation details were informed by the openMSX pull request [Add Wave Game audio cartridge support by MBilderbeek · Pull Request #2126 · openMSX/openMSX](https://github.com/openMSX/openMSX/pull/2126).

**MegaRAM support on PicoVerse 2350 LoadROM and Explorer** is a PicoVerse PSRAM-backed implementation of the MSX MegaRAM concept created by Ademir Carchano in Brazil in 1987. The implemented banking behavior follows the Cartucho II / SDMapper-compatible MegaRAM model: four 8KB windows in `0x4000`-`0xBFFF`, bank latches selected by address bits A14:A13, volatile RAM contents, and loader-controlled write enable through `IN (0x8E/0x8F)` with write disable through `OUT (0x8E/0x8F)`. The PicoVerse implementation is original firmware code and is provided as a tribute to Ademir Carchano's contribution to the MSX community.

**FMPCCMFC.BIN** is the English FM-PAC BIOS used by PicoVerse 2350 LoadROM when `-f` / `-fmpac` is selected. The FM-PAC BIOS ROM is copyrighted by Matsushita Corp.; the English translation is credited to 232, Max Iwamoto, and GDX.

**The Yamanooto flash-cartridge emulation on PicoVerse 2350** reproduces the *Yamanooto* cartridge (a Konami-SCC compatible 8 MB flash-ROM with SCC/SCC+ and a secondary PSG). The register map, mapper/offset behaviour, SCC/SCC+ activation rules, and FPGA ID handshake were implemented with reference to openMSX's Yamanooto device implementation ([Yamanooto.cc](https://github.com/openMSX/openMSX/blob/master/src/memory/Yamanooto.cc)) and public Yamanooto programming notes ([Programming the Yamanooto](https://genami.shop/blogs/news/programming-the-yamanooto)). PicoVerse's SCC/SCC+ uses **emu2212**, the dual/mirror PSG uses **emu2149**, and the added MSX-MUSIC engine uses **emu2413** (all © Mitsutaka Okazaki, MIT License). The embedded FM-PAC BIOS (`FMPCCMFC.BIN`) is credited as above. The RP2350 bus/PIO handling, the runtime SCC/FM/PSG engine selector, and the audio pipeline are original PicoVerse work licensed under CC BY-NC-SA 4.0. The physical Yamanooto cartridge is a product of the SCC Alliance; PicoVerse is an independent emulation and is not affiliated with or endorsed in any way.

**MIDI-PAC PSG-to-MIDI Conversion:**  
The MIDI-PAC firmware and its quality improvements were developed against public technical references and behavior studies. The PSG-to-MIDI mapping combines hardware-correct AY-3-8910 / YM2149 interpretation with pragmatic General MIDI reinterpretation for musical output on modules like the Roland SC-55. Key references used include:  
- The `berarma/aymidi` project by berarma (AY-3-8910 to MIDI conversion reference).  
- The `ayumi` AY/YM2149 emulator by Peter Sovietov (Peter Sovietov, 2022; used for envelope generation verification).  
- The ESEMSX3 FPGA implementation `midi.vhd` (serves as a minimal alternative PSG-to-MIDI transport reference).  
- AY-3-8910 and YM2149 datasheets and hardware behavior documentation (General Instruments and Yamaha specifications).  
- MSX-MIDI specification and USB MIDI 1.0 Event Packet format (USB Implementers Forum).  
- The Sunrise IDE specification and Nextor protocol documentation.  

**The OPL4 / YMF278B / MoonSound implementation on PicoVerse 2350 LoadROM** is an original PicoVerse standalone cartridge firmware written for the RP2350. PicoVerse implements the MSX/MoonSound host side itself: PIO bus capture for ports `0xC4`-`0xC7` and `0x7E`/`0x7F`, `/WAIT`-gated reads, `/BUSDIR` drive, register/status shadows, FM timer `/INT` delivery, YRW801-M wave-ROM exposure, and 2 MB PCM sample RAM.

**YMF278B synthesis** uses Aaron Giles' `ymfm` Yamaha sound cores, licensed under the BSD 3-Clause License, including the OPL/FM and PCM support wrapped by PicoVerse's `emu278b` interface for timer, IRQ, ROM, and sample-RAM behavior. The MoonSound/WozBlaster-compatible port map, `/BUSDIR` behavior, 2 MB YRW801-M ROM plus 2 MB RAM model, and compatibility work were informed by public technical references including the Wozblaster OPL4_Cartridge project and openMSX's OPL4 implementation. The bundled `YRW801-M` instrument ROM is a Yamaha 1993 third-party ROM payload and must be treated as copyrighted material. PicoVerse's bus firmware, cartridge integration, synchronization model, and RP2350 audio pipeline are original PicoVerse work and are licensed under CC BY-NC-SA 4.0, allowing for non-commercial use and modification with proper attribution; commercial use or resale requires explicit authorization from the author.

**The MSX-AUDIO / Yamaha Y8950 implementation on PicoVerse 2350 LoadROM** (`loadrom.exe -a`) is an original PicoVerse standalone cartridge firmware written for the RP2350. Unlike the OPL4 build it answers both memory and I/O cycles: PicoVerse implements the slot memory decode for the MSX-Audio BIOS plus base and expanded work RAM, the `0xC0`/`0xC1` port handling with `/WAIT`-gated reads and `/BUSDIR` drive, Y8950 FM timer `/INT` delivery, and 256 KB of ADPCM sample RAM in PSRAM, all in a single-owner core loop feeding the I2S DAC at the Y8950 native 49716 Hz rate.

**Y8950 synthesis** uses Aaron Giles' `ymfm` Yamaha sound cores (BSD 3-Clause License), specifically the `y8950` OPL1 + ADPCM-B core, timers, IRQ, busy behavior, and I/O pins. The cartridge model \u2014 slot memory map, `Normal0000` BIOS layout, work-RAM mirrors, status-bit behavior, and the 256 KB SampleRAM configuration \u2014 reproduces the openMSX extension `Boosted_audio.xml` ("MSX-Audio" by Philips/MSXPro) and openMSX's `MSXAudio` / `Y8950Periphery` implementations, used as a hardware-behavior reference only (openMSX is GPLv2+). The bundled `MSXAUDIO_NMS1205.ROM` is the MSX-Audio BIOS v1.3 for the Philips NMS-1205 and is a third-party copyrighted BIOS payload. PicoVerse's bus firmware, decode tables, synchronization model, and RP2350 audio pipeline are original PicoVerse work licensed under CC BY-NC-SA 4.0.

**MSX-MIDI Interface:**  
The MSX-MIDI firmware was developed using the MSX-MIDI specification, USB MIDI 1.0 specification, TinyUSB host API, and reference behavior from ESEMSX3 and similar implementations. The 8251 USART emulation and standard MIDI wire protocol handling are original PicoVerse implementations.

**The Sunrise IDE driver for Nextor** used on PicoVerse is copyright by Konamiman, Piter Punk, and FRS, and is licensed under the special terms by MSX Licensing Corporation. The original Sunrise IDE code is available at https://github.com/Konamiman/Nextor/blob/v2.1/source/kernel/drivers/SunriseIDE/sunride.asm

The algorithm to emulate ATA devices is original and based on the implementation for the Carnivore2 cartridge, Copyright (c) 2017-2024 by the RBSC group. Portions (c) Mitsutaka Okazaki and (c) Kazuhiro Tsujikawa. Available at https://github.com/RBSC/Carnivore2/tree/master/Firmware/Sources

**WiFi support on PicoVerse 2350** was implemented with direct reference to the ESP8266 / MSX WiFi work by Oduvaldo Pavan Junior (`ducasp`). The PicoVerse WiFi ROM integration, memio register layout, fixed-`859372` UART behavior, FIFO clear command handling, quick-receive behavior, and ESP-side protocol compatibility were based on public source and documentation from Oduvaldo's projects. Important references used include:
- `MSXPICO/UNAPI_BIOS_CUSTOM_ESP_MSXPICO/ESP8266_memio.asm` from `ducasp/MSX-Development` for the memory-mapped ROM and register model.
- `MSX-SM/WiFi/UNAPI_BIOS_CUSTOM_ESP_FIRMWARE` and related WiFi utilities from `ducasp/MSX-Development` for the ROM/driver lineage and behavior.
- `ducasp/ESP8266-UNAPI-Firmware` and its documentation for the serial protocol, command/response structure, and ESP firmware behavior.

Those projects remain copyright by Oduvaldo Pavan Junior and their respective contributors under their original terms. PicoVerse reuses the public technical design references and keeps its own RP2350 cartridge-side implementation.

**File Hunter browser integration on PicoVerse 2350 Explorer** was implemented with reference to NataliaPC's MSX File Hunter Browser project and the public File Hunter service behavior. PicoVerse keeps its own Explorer MSX menu and RP2350/ESP8266 transport implementation, while acknowledging the original MSX File Hunter Browser code and workflow by NataliaPC. Reference repository: https://github.com/nataliapc/msx_filehunterbrowser

**Mapper detection heuristics and filename tag forcing schemes** in the LoadROM and MultiROM tools are original implementations by the OpenMSX developers for the Romfactory module and licensed under the GNU Public License (GPL). Available at https://github.com/openMSX/openMSX/blob/6f8aa9865eeccdb0b31043d8851b822538440204/src/memory/RomFactory.cc

**The softwaredb database** used for ROM mapper detection is built upon contributions from across the MSX community, including the initial work by Nicolas Beyaert, later expanded by the BlueMSX Team (2004–2013) and continuously maintained by the openMSX Team (2005–present). It also incorporates MSX ID data generated by Generation MSX (www.generation-msx.nl). The latest updates are based on the awesome work by Vampier, with the database available at https://romdb.vampier.net/. Special thanks go to the Generation MSX / Sylvester project for its extensive reference data, as well as to contributors such as p_gimeno and diedel for ROM additions and validation, and GDX for further ROM information, corrections, and verification efforts. Part of openMSX effort. Available at https://github.com/openMSX

**The per-ROM 50/60 Hz (VDP frequency) feature** in PicoVerse 2350 Explorer was implemented with reference to the `50-60hz` project by sdsnatcher73, which demonstrates how to switch the V9938/V9958 VDP line frequency (Register #9, PAL/NTSC bit) reliably on MSX without corrupting the screen. That project is licensed under the Apache License 2.0 and could not have been created without the help of gdx, Grauw, and NYRIKKI, as credited by its author. The application technique was further refined after studying the strategy used by the **Carnivore2** cartridge boot menu (`BOOTCMFC.ASM`, by the RBSC group): using the BIOS `WRTVDP` routine (`0x0047`) so the R9 change also updates the `RG9SAV` shadow at `0xFFE8` for better game compatibility, and restricting the frequency change to MSX2 and later machines. Only the publicly available Carnivore2 technique was used as a reference. PicoVerse keeps its own RP2350 cartridge-side implementation (a per-ROM option persisted in `.PVC` files and applied by injecting a small VDP R9 write into the launched game's cartridge INIT), while gratefully acknowledging sdsnatcher73's and RBSC's reference work. Reference repositories: https://github.com/sdsnatcher73/50-60hz and https://github.com/RBSC/Carnivore2

**The per-ROM CPU speed feature** in PicoVerse 2350 Explorer was implemented with reference to two public MSX projects. `Z80-R800` by GDX (https://github.com/gdx-msx/Z80-R800) provides MSX-DOS/BASIC commands that switch the MSX turbo R CPU mode and demonstrates the `CHGCPU` (`#0180`) call convention along with the MSXVER check used to detect a turbo R. `msx-turbo` by Papipapito (https://github.com/Papipapito/msx-turbo), licensed under the MIT License, is a command-line 3.58/5.37 MHz switch for Panasonic MSX2+ machines and documents the switched-I/O device 8 protocol on ports `#40`/`#41` and its polarity. The port and BIOS definitions were cross-checked against the MSX Assembly Page (https://map.grauw.nl). PicoVerse keeps its own RP2350 cartridge-side implementation (a per-ROM option persisted in `.PVC` files and applied by injecting the switch into the launched game's cartridge INIT), while gratefully acknowledging GDX's and Papipapito's reference work.

**The .DSK disk image support in PicoVerse 2350 Explorer** was designed after studying the MSXUSB **MsxUsbFDD** driver, which is based on Konamiman's Rookie Drive USB FDD BIOS and serves `.DSK` files through a CH376 USB host. PicoVerse keeps its own RP2350 implementation, which serves the image from PSRAM through the existing Sunrise IDE emulation and Konamiman's Nextor 2.1.4 kernel.

## Feedback & Community

Questions, test reports, and build photos are welcome. Open an issue on the public repository or reach out through the MSX retro hardware forums where PicoVerse updates are posted.

Author: Cristiano Goncalves
Last updated: 09/24/2026

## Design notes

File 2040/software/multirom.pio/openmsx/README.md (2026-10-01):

# PicoVerse 2040 MultiROM for openMSX

Run a PicoVerse 2040 MultiROM UF2 in [openMSX](https://openmsx.org/) as if the cartridge were plugged into the emulated MSX. You point openMSX at the same `.uf2` file you would flash to the Pico. The MSX then boots the PicoVerse menu and shows every entry in that UF2: your ROMs, plus the Nextor Sunrise IDE entries if the UF2 was built with `-s` or `-m`.

The Raspberry Pi Pico is not emulated. An openMSX Tcl script does the Pico firmware's job instead, and a normal openMSX extension makes the cartridge appear in the openMSX menus. You don't need to change or rebuild openMSX.

## Contents

| File | Purpose |
| --- | --- |
| [share/scripts/picoverse2040.tcl](share/scripts/picoverse2040.tcl) | The openMSX script. It turns a UF2 into the PicoVerse cartridge and adds the `picoverse2040` console command and three settings. |
| [share/extensions/PicoVerse_2040/](share/extensions/PicoVerse_2040/hardwareconfig.xml) | The **PicoVerse 2040 MultiROM** extension shown in the openMSX Extensions menu. |
| [src/placeholder.asm](src/placeholder.asm) | Source of the extension's placeholder ROM. Build it with `make` (needs SDCC). |
| [install.ps1](install.ps1) / [install.sh](install.sh) | Install the script and the extension for the current user. |

The folder uses the same layout as the openMSX `share` folder. openMSX automatically loads every `*.tcl` file in `share/scripts` and lists every extension in `share/extensions`. An extension XML can only describe hardware; it can't read a UF2 or react to the menu. So the extension holds a small placeholder ROM, and the script replaces it with the menu of your UF2 when you insert it. The Nextor entries use extensions that the script generates when you boot them (see [Nextor entries](#nextor-entries)).

## Requirements

- openMSX 20.0 or newer (tested with 20.0). It needs the `NEO-8`, `NEO-16`, `ASCII16-X` and `Manbow2` ROM types.
- A MultiROM UF2 built with the PicoVerse 2040 MultiROM tool (`multirom.exe`, v2.63 layout).
- Any MSX1, MSX2, MSX2+ or turbo R machine. The bundled C-BIOS machines are enough for plain ROMs. Nextor entries need a machine with a real MSX BIOS (MSX-BASIC).

## Installation

Run the installer for your system. It copies `share/scripts/picoverse2040.tcl` and `share/extensions/PicoVerse_2040` into the `share` folder of your openMSX user directory:

```powershell
# Windows (installs to Documents\openMSX\share, or to $env:OPENMSX_HOME\share)
powershell -ExecutionPolicy Bypass -File install.ps1
```

```sh
# Linux / macOS (installs to ~/.openMSX/share, or to $OPENMSX_HOME/share)
sh install.sh
```

Restart openMSX afterwards. **PicoVerse 2040 MultiROM** then shows up in the Extensions menu, and `help picoverse2040` works in the console (F10).

## Usage

### From the openMSX menus

1. Open **Media > Cartridge Slot A** (or B) and choose **ROM image**.
2. Browse to your `.uf2` file. Switch the file type filter to **All files (\*)**, because openMSX only lists ROM files by default.
3. Insert it. The script sees the UF2 in the slot and replaces it with the PicoVerse cartridge. The MSX resets and shows the PicoVerse MultiROM menu.

Choose an entry with the cursor keys and press Enter, just as on real hardware.

The script remembers that UF2. After that, you can simply insert the **PicoVerse 2040 MultiROM** extension, from the Extensions menu or from the extension option in a Cartridge Slot window, and it loads the same UF2. If you insert the extension before any UF2 has been chosen, the MSX screen explains how to choose one. The UF2 also shows up in openMSX's recent cartridges list.

### From the command line

Start openMSX with the UF2 as a cartridge, or with the extension to load the remembered UF2:

```text
openmsx -machine Philips_NMS_8245 -carta C:/PicoVerse/multirom.uf2
openmsx -machine Philips_NMS_8245 -ext PicoVerse_2040
```

### From the console

Open the console (F10):

```text
picoverse2040 insert C:/PicoVerse/multirom.uf2
```

> **Windows paths:** the console is a Tcl shell, where a backslash is an escape character. `C:\temp\multirom.uf2` reaches the script as `C:<TAB>empmultirom.uf2`. Use forward slashes (`C:/temp/multirom.uf2`) or put the path in braces (`{C:\temp\multirom.uf2}`). Tab completion also inserts forward slashes. File dialogs and the command line are not affected.

| Command | Description |
| --- | --- |
| `picoverse2040 insert <file.uf2> [-slot a\|b] [-hd <image>]` | Insert the cartridge and reset the MSX. `-slot` picks the cartridge slot. `-hd` picks the disk image the Nextor entries use as the USB drive. |
| `picoverse2040 insert` | Insert the last UF2 again (setting `picoverse2040_uf2`). |
| `picoverse2040 menu` | Go back to the menu, like power cycling the MSX with the real cartridge. |
| `picoverse2040 boot <n>` | Skip the menu and boot entry `<n>`. |
| `picoverse2040 list` | List the UF2 entries. `*` marks the running one. |
| `picoverse2040 info` | Show the UF2, slot, state, disk image and cache folder. |
| `picoverse2040 eject` | Remove the cartridge. |

The cartridge behaves like the real one:

- **Reset** keeps the selected ROM running. On real hardware, the Pico keeps serving the ROM it selected.
- **Power off and on** brings the menu back. On real hardware, the Pico restarts with the MSX.

### Settings

These are normal openMSX settings. Change them in the console (for example `set picoverse2040_hd C:/PicoVerse/usb.dsk`). openMSX saves them with the rest of its settings.

| Setting | Default | Description |
| --- | --- | --- |
| `picoverse2040_uf2` | *(empty)* | UF2 loaded by the **PicoVerse 2040 MultiROM** extension. Updated automatically every time you insert a UF2. |
| `picoverse2040_slot` | `a` | Cartridge slot used by `picoverse2040 insert` when `-slot` is not given. |
| `picoverse2040_hd` | *(empty)* | Disk image for the Nextor entries. If empty, `persistent/picoverse2040/hd.dsk` in the openMSX user directory is used. |

## How it works

1. **Detection.** openMSX has no Tcl event for inserting a cartridge, so the script checks the cartridge slots four times a second (`machine_info external_slot`). When a slot holds a `.uf2` file or the `PicoVerse_2040` extension, the script takes over that slot.
2. **UF2 decoding.** The UF2 blocks are put back together into the Pico flash image. Blocks marked as not-for-flash and blocks for other chip families are skipped.
3. **Finding the menu.** The multirom tool lays out flash as `[firmware][menu ROM 16KB][config area 16KB][ROMs...]`. All config offsets are relative to the end of the firmware (`__flash_binary_end`). The firmware size changes from build to build, so the script looks for the menu's `AB` header followed by a valid config area whose first record points to offset `0x8000`.
4. **Menu.** The 32KB menu and config area are inserted as a `Page12` cartridge (`0x4000-0xBFFF`), exactly as `loadrom_msx_menu()` serves them.
5. **Selection.** When you pick an entry, the menu writes its index to the ROM select register at `0x9D81` (`ROM_SELECT_REGISTER` in `msx/src/menu.h`) and then reboots. A write watchpoint on `0x9D81` catches that write. It only fires while page 2 has the PicoVerse slot selected. The script then swaps in the selected ROM and resets the MSX.
6. **ROM files.** The selected ROM is extracted to `persistent/picoverse2040/cache/<uf2 name>_<size>_<mtime>/` in the openMSX user directory. When the UF2 changes, the extracted files are rebuilt automatically.

### Mapper mapping

| PicoVerse code | Menu label | openMSX ROM type | Notes |
| --- | --- | --- | --- |
| 1 | PLA-16 | `Page12` | Padded with `0xFF` to 32KB. The firmware returns `0xFF` above the ROM size. |
| 2 | PLA-32 | `Page12` | |
| 3 | KonSCC | `KonamiSCC` | |
| 4 | PLN-48 | `Page012` | Padded to 48KB. |
| 5 | ASC-08 | `ASCII8` | |
| 6 | ASC-16 | `ASCII16` | |
| 7 | Konami | `Konami` | |
| 8 | NEO-8 | `NEO-8` | |
| 9 | NEO-16 | `NEO-16` | |
| 10 | SYSTEM | generated `PicoVerse2040_Nextor` extension | Nextor Sunrise IDE. |
| 11 | SYSTEM | generated `PicoVerse2040_Nextor_Mapper` extension | Nextor Sunrise IDE plus a 192KB memory mapper. |
| 12 | ASC16X | `ASCII16-X` | |
| 13 | PLN-64 | `Page0123` | Padded to 64KB. |
| 14 | MANBW2 | `Manbow2` | |

### Nextor entries

openMSX only loads extensions from its `extensions` folders. When you boot a Nextor entry, the script therefore writes a standard openMSX extension to `share/extensions/PicoVerse2040_Nextor*/hardwareconfig.xml` in the user directory and inserts it into the PicoVerse slot:

- **Nextor Sunrise IDE** (`-s`): a `SunriseIDE` device that uses the Nextor ROM taken from the UF2.
- **Nextor Sunrise IDE + 192KB Mapper** (`-m`): the slot is expanded, like `loadrom_sunrise_mapper()` does. Sub-slot 0 holds the `SunriseIDE` device and sub-slot 1 a 192KB `MemoryMapper`.

The USB thumb drive becomes the IDE master hard disk image, which is the `-hd` option or the `picoverse2040_hd` setting. If the image doesn't exist, openMSX creates a blank 100MB one. Partition and format it with `CALL FDISK` from Nextor BASIC, then copy the Nextor system files onto it, the same as a thumb drive. See [the MultiROM manual](../../../../docs/msx-picoverse-2040-multirom-tool-manual.en-us.md#using-nextor-with-the-picoverse-2040-cartridge). You can also point `-hd` at an existing disk image.

The generated extensions are rewritten each time a Nextor entry boots, and they also show up in the Extensions menu. Don't edit or insert them yourself; insert **PicoVerse 2040 MultiROM** instead.

## Limitations

- The emulation is functional, not cycle-exact. openMSX uses its own mapper implementations, so Pico-specific timing such as `/WAIT` stretching is not reproduced.
- openMSX's `KonamiSCC` and `Manbow2` ROM types include the SCC sound chip. The PicoVerse 2040 hardware does not output SCC audio.
- Savestates and replays refer to the extracted files in the cache folder. Keep that folder if you want to reload them.
- Machine switches drop the cartridge, the same as openMSX does for normal cartridges. Insert the **PicoVerse 2040 MultiROM** extension again, or run `picoverse2040 insert`.
- When a `.uf2` is inserted as a ROM image, openMSX briefly runs it as a plain ROM (for up to a quarter of a second) before the script takes over the slot and resets the MSX.

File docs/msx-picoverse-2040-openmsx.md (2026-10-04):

# MSX PicoVerse 2040 — MultiROM in openMSX

This document describes how to run a PicoVerse 2040 MultiROM UF2 in the [openMSX](https://openmsx.org/) emulator, as if the cartridge were plugged into the emulated MSX. It covers installation, choosing the UF2, using the menu, attaching the emulated USB drive to the Nextor entries, the console commands and settings, and how the implementation works.

The openMSX support is part of the MultiROM project and lives in [2040/software/multirom.pio/openmsx](../2040/software/multirom.pio/openmsx). It is versioned and built together with the rest of the MultiROM project (v2.64 and later).

## 1. Overview

You point openMSX at the same `.uf2` file you would flash to the Pico. The emulated MSX then boots the PicoVerse MultiROM menu and lists every entry in that UF2:

- the game and application ROMs, with their PicoVerse mappers;
- the embedded **Nextor Sunrise IDE** entry (UF2 built with `-s`) or **Nextor Sunrise IDE + 192KB Mapper** entry (UF2 built with `-m`), with a disk image as the USB drive.

The Raspberry Pi Pico is not emulated. An openMSX Tcl script does the Pico firmware's job instead, and a normal openMSX extension makes the cartridge appear in the openMSX menus. You don't need to change or rebuild openMSX.

Typical uses:

- try a MultiROM UF2 before flashing it;
- check that every ROM in a compilation starts with the mapper the tool detected;
- prepare and test a Nextor USB drive (as a disk image) without the cartridge.

## 2. Requirements

- openMSX 20.0 or newer (tested with 20.0 and 21.0). It needs the `NEO-8`, `NEO-16`, `ASCII16-X` and `Manbow2` ROM types.
- A MultiROM UF2 built with the PicoVerse 2040 MultiROM tool (`multirom.exe`), see the [MultiROM tool manual](./msx-picoverse-2040-multirom-tool-manual.en-us.md).
- Any MSX1, MSX2, MSX2+ or turbo R machine. The bundled C-BIOS machines are enough for plain ROMs. The Nextor entries need a machine with a real MSX BIOS (MSX-BASIC) and its system ROMs installed in openMSX.

## 3. Files

| File | Purpose |
| --- | --- |
| [openmsx/share/scripts/picoverse2040.tcl](../2040/software/multirom.pio/openmsx/share/scripts/picoverse2040.tcl) | The openMSX script. It turns a UF2 into the PicoVerse cartridge and adds the `picoverse2040` console command and three settings. |
| [openmsx/share/extensions/PicoVerse_2040/](../2040/software/multirom.pio/openmsx/share/extensions/PicoVerse_2040/hardwareconfig.xml) | The **PicoVerse 2040 MultiROM** extension shown in the openMSX extension lists. |
| [openmsx/src/placeholder.asm](../2040/software/multirom.pio/openmsx/src/placeholder.asm) | Source of the extension's placeholder ROM (`picoverse2040.rom`). |
| [openmsx/Makefile](../2040/software/multirom.pio/openmsx/Makefile) | Builds the placeholder ROM. Called by the MultiROM aggregate Makefile. |
| [openmsx/install.ps1](../2040/software/multirom.pio/openmsx/install.ps1) / [openmsx/install.sh](../2040/software/multirom.pio/openmsx/install.sh) | Install the script and the extension for the current user. |

The `openmsx/share` folder uses the same layout as the openMSX `share` folder. openMSX loads every `*.tcl` file in `share/scripts` at startup and lists every extension in `share/extensions`. An extension XML can only describe hardware; it can't read a UF2 or react to the menu. So the extension holds a small placeholder ROM, and the script replaces it with the menu of your UF2 when you insert it.

The PicoVerse 2350 Explorer add-on ([MSX PicoVerse 2350 — Explorer in openMSX](./msx-picoverse-2350-openmsx.md)) can be installed next to this one: `picoverse2040.tcl` only takes over RP2040 UF2s, and leaves RP2350 (Explorer) UF2s to `picoverse2350.tcl`.

## 4. Building

The openMSX add-on is built by the MultiROM aggregate Makefile, together with the MSX menu, the Pico firmware and the tool:

```sh
cd 2040/software/multirom.pio
make            # msx -> pico -> tool, and openmsx
make openmsx    # only the openMSX add-on
```

The `openmsx` stage assembles `src/placeholder.asm` with SDCC (`sdasz80`, `sdldz80`, `hex2bin`) into `share/extensions/PicoVerse_2040/picoverse2040.rom`. The aggregate Makefile passes `VERSION`, and the stage fails if the `variable version` line in `picoverse2040.tcl` doesn't match it. Bump both when the MultiROM version changes. Running `make` inside `openmsx/` without `VERSION` skips the check.

The placeholder ROM is committed, so you only need SDCC if you change `placeholder.asm`.

## 5. Installation

Run the installer for your system. It copies `share/scripts/picoverse2040.tcl` and `share/extensions/PicoVerse_2040` into the `share` folder of your openMSX user directory:

```powershell
# Windows (installs to Documents\openMSX\share, or to $env:OPENMSX_HOME\share)
powershell -ExecutionPolicy Bypass -File 2040\software\multirom.pio\openmsx\install.ps1
```

```sh
# Linux / macOS (installs to ~/.openMSX/share, or to $OPENMSX_HOME/share)
sh 2040/software/multirom.pio/openmsx/install.sh
```

Both installers also accept the openMSX user directory as an argument (`install.ps1 -OpenMSXHome <dir>`, `install.sh <dir>`).

Restart openMSX afterwards. **PicoVerse 2040 MultiROM** then shows up in the extension lists, and `help picoverse2040` works in the console (F10). Run the installer again after updating the repository to install the new script.

## 6. Quick start

1. Start openMSX with any MSX machine.
2. Open **Media > Cartridge Slot A** and choose **ROM image**.
3. Browse to your `.uf2` file. Switch the file type filter to **All files (\*)**, because openMSX only lists ROM files by default.
4. Insert it. The MSX resets and shows the PicoVerse MultiROM menu.
5. Choose an entry with the cursor keys and press Enter, as on real hardware.

Reset the MSX to go back to the menu. From now on, inserting the **PicoVerse 2040 MultiROM** extension loads the same UF2.

## 7. Choosing the UF2

The script needs to know which UF2 to use. You can give it in any of these ways; each one also stores the UF2 in the `picoverse2040_uf2` setting, so the extension reloads it later.

### 7.1 As a cartridge ROM image (GUI)

Open **Media > Cartridge Slot A** (or B), choose **ROM image**, switch the filter to **All files (\*)** and select the `.uf2`. openMSX inserts the file as a ROM; the script notices the `.uf2` in the slot within a quarter of a second, ejects it, inserts the PicoVerse cartridge in the same slot and resets the MSX. The UF2 also shows up in openMSX's recent cartridge list.

### 7.2 With the PicoVerse 2040 MultiROM extension

Insert **PicoVerse 2040 MultiROM** from the extensions list of the Media menu, or select it with the **Extension** option of a Cartridge Slot window. The script replaces the extension with the menu of the UF2 stored in `picoverse2040_uf2` (the last UF2 used) in the same slot.

If no UF2 was chosen yet, the placeholder ROM stays and the MSX screen shows how to select one, and openMSX shows a warning message.

### 7.3 From the command line

Start openMSX with the UF2 as a cartridge, or with the extension to load the remembered UF2:

```text
openmsx -machine Philips_NMS_8245 -carta C:/PicoVerse/multirom.uf2
openmsx -machine Philips_NMS_8245 -ext PicoVerse_2040
```

### 7.4 From the console

Open the console (F10) and run:

```text
picoverse2040 insert C:/PicoVerse/multirom.uf2
picoverse2040 insert C:/PicoVerse/multirom.uf2 -slot b
```

`picoverse2040 insert` without a file inserts the last UF2 again. The same works with `carta C:/PicoVerse/multirom.uf2`, which goes through the take-over described in 7.1.

### 7.5 With the setting

```text
set picoverse2040_uf2 C:/PicoVerse/multirom.uf2
```

This only selects the UF2 used by the next insertion of the extension (or by `picoverse2040 insert` without a file). openMSX saves the setting with its other settings.

> **Windows paths in the console:** the console is a Tcl shell, where a backslash is an escape character. `C:\temp\multirom.uf2` reaches the script as `C:<TAB>empmultirom.uf2`. Use forward slashes (`C:/temp/multirom.uf2`) or put the path in braces (`{C:\temp\multirom.uf2}`). Tab completion inserts forward slashes. File dialogs and the command line are not affected. When a path is not found, the script explains this in its error message.

### 7.6 Rebuilt UF2 files

The script extracts the menu and the selected ROMs to a cache folder named after the UF2 file, its size and its modification time. The UF2 is read when it is inserted, so after rebuilding it, insert it again (`picoverse2040 insert`, the extension, or the ROM image) to use the new contents; a reset keeps the UF2 that is already loaded. Caches of older builds of the same UF2 are deleted.

## 8. Using the menu

The menu is the real PicoVerse MultiROM menu ROM from the UF2, so it looks and works as on the cartridge: cursor keys to move, left/right to change page, Enter to start an entry.

When you start an entry, the script inserts it with the matching openMSX mapper and resets the MSX, which then boots the entry. After that:

| Action | Result |
| --- | --- |
| **Reset** (Machine menu, hotkey or `reset` command) | The menu comes back. |
| **Power off and on** | The menu comes back. |
| **Restart openMSX** with the entry still in the slot (for example a setup saved at exit and restored at startup) | The menu of the last UF2 comes back. |
| **Insert the PicoVerse 2040 MultiROM extension again** | The menu comes back. |
| **Load a savestate** | The entry that was running in the savestate keeps running. The next reset brings the menu back. |
| `picoverse2040 menu` | The menu comes back. |
| `picoverse2040 boot <n>` | Entry `<n>` starts without going through the menu. |

Only the reset that the script issues to start the selected entry keeps the entry. Every other reset or power-up returns to the menu.

## 9. Emulated USB storage (Nextor entries)

On the cartridge, the Nextor entries use a USB thumb drive connected to the Pico's USB-C port. In openMSX, a **hard disk image file** takes its place. It is attached as the master disk of an emulated Sunrise IDE interface, and Nextor sees it as the `PicoVerse USB drive`.

The image is only attached while a Nextor entry is running; the menu and the game ROMs don't use it.

### 9.1 Which image is used

The script picks the image when a Nextor entry boots, in this order:

1. the `-hd` option of the last `picoverse2040 insert` command;
2. the `picoverse2040_hd` setting;
3. the default image `persistent/picoverse2040/hd.dsk` in the openMSX user directory (`Documents\openMSX` on Windows, `~/.openMSX` on Linux and macOS).

`picoverse2040 info` shows the image that the next Nextor boot will use. If the image file doesn't exist, openMSX creates a blank (unformatted) 100MB image there.

### 9.2 Attaching an image

To use your own image for every Nextor boot, set the setting (openMSX saves it):

```text
set picoverse2040_hd C:/PicoVerse/usb.dsk
```

The setting is read every time a Nextor entry boots. If a Nextor entry is running, reset the MSX and start the Nextor entry again from the menu.

To use an image only for the current session, give it when inserting the UF2. It stays active until the next insertion:

```text
picoverse2040 insert C:/PicoVerse/multirom.uf2 -hd C:/PicoVerse/test.dsk
```

When the Nextor entry is running, the `hda` console command shows the attached image.

### 9.3 Creating and filling an image

The easiest way is the openMSX `diskmanipulator` command, which creates Nextor-formatted images and copies files between the PC and the image. Run these commands in the console, for example while the PicoVerse menu is on screen (no Nextor entry running):

```text
diskmanipulator create C:/PicoVerse/usb.dsk -nextor 100M
virtual_drive C:/PicoVerse/usb.dsk
diskmanipulator import virtual_drive C:/PicoVerse/files/
diskmanipulator dir virtual_drive
virtual_drive eject
set picoverse2040_hd C:/PicoVerse/usb.dsk
```

- `create ... -nextor 100M` creates a 100MB image with a single Nextor FAT16 volume (FAT16 is used above 32MB; the maximum is 4GB).
- `virtual_drive` attaches the image to openMSX's virtual drive, which `diskmanipulator` can work on without any emulated disk interface.
- `import` copies a file, or every file and subfolder of a PC folder, to the image. Use `mkdir` and `chdir` to create and select MSX folders first, and `export virtual_drive <PC folder>` to copy files back to the PC.
- `virtual_drive eject` releases the image before Nextor uses it.

To create a partitioned image, give several sizes: `diskmanipulator create C:/PicoVerse/usb.dsk -nextor 100M 32M`. The partitions are then addressed as `virtual_drive1`, `virtual_drive2`, and so on (`diskmanipulator import virtual_drive1 C:/PicoVerse/files/`).

> **Long file names:** Nextor uses 8.3 file names, and `diskmanipulator import` shortens longer names by truncating them: `Depeche Mode - Strangelove.mp3` becomes `DEPECHE_.MP3`. When two names in a folder shorten to the same 8.3 name, only the first file is imported and the console shows `Warning: preserving entry <name>`. For folders with long names, copy them first to a staging folder with unique 8.3 names (for example `DEPECH~1.MP3`, `DEPECH~2.MP3`, as Windows does), and import the staging folder.

Change the image only while no Nextor entry is running. Nextor caches disk sectors, so files imported while it runs may not show up, and the MSX could overwrite them.

Alternatively, let openMSX create the blank default image, boot the Nextor entry, and partition it with `CALL FDISK` from Nextor BASIC, as you would with a new thumb drive. You can also use a raw image of a FAT16 thumb drive (4GB or smaller) taken with a disk imaging tool.

### 9.4 Nextor system files

Without system files on the image, Nextor boots into Nextor BASIC (`Nextor BASIC version 2.10`). `CALL DRVINFO` lists the drives; the image is the drive assigned to `Sunrise IDE`, normally `A:`. To boot into the Nextor command prompt, copy `NEXTOR.SYS` and `COMMAND2.COM` to the root of the image, as for a real thumb drive. See [How to prepare a thumb drive for Nextor](./msx-picoverse-2040-multirom-tool-manual.en-us.md#how-to-prepare-a-thumb-drive-for-nextor) for the download links, ROM launchers such as SofaRun, and the RAM requirements.

The **Nextor Sunrise IDE + 192KB Mapper** entry adds a 192KB memory mapper, as on the cartridge, so Nextor also works on machines with less than 128KB of RAM.

## 10. Console command reference

| Command | Description |
| --- | --- |
| `picoverse2040 insert <file.uf2> [-slot a\|b] [-hd <image>]` | Insert the cartridge built into the UF2 and reset the MSX. `-slot` picks the cartridge slot (default: setting `picoverse2040_slot`). `-hd` picks the USB drive image of the Nextor entries until the next insert. |
| `picoverse2040 insert` | Insert the last UF2 again (setting `picoverse2040_uf2`). |
| `picoverse2040 <file.uf2>` | Same as `picoverse2040 insert <file.uf2>`. |
| `picoverse2040 menu` | Go back to the menu (same as resetting the MSX). |
| `picoverse2040 boot <n>` | Skip the menu and start entry `<n>`. |
| `picoverse2040 list` | List the UF2 entries with mapper and size. `*` marks the running one. |
| `picoverse2040 info` | Show the UF2, slot, state, USB drive image and cache folder. Same as `picoverse2040` without arguments. |
| `picoverse2040 eject` | Remove the cartridge. |

`help picoverse2040` shows the same information in the console. Sub-commands, slots, files and entry numbers can be tab completed.

## 11. Settings

These are normal openMSX settings. Change them in the console with `set <name> <value>`; openMSX saves them with its other settings.

| Setting | Default | Description |
| --- | --- | --- |
| `picoverse2040_uf2` | *(empty)* | UF2 loaded by the **PicoVerse 2040 MultiROM** extension. Updated every time you insert a UF2. |
| `picoverse2040_slot` | `a` | Cartridge slot used by `picoverse2040 insert` when `-slot` is not given. |
| `picoverse2040_hd` | *(empty)* | USB drive image of the Nextor entries, read every time a Nextor entry boots. If empty, `persistent/picoverse2040/hd.dsk` in the openMSX user directory is used. |

## 12. How it works

### 12.1 Insertion and slot watching

openMSX has no Tcl event for inserting a cartridge, so the script checks the external cartridge slots four times a second (`machine_info external_slot`). It takes over a slot when it holds:

- a `.uf2` file inserted as a ROM image;
- the `PicoVerse_2040` extension;
- a ROM from the script's cache or a Nextor configuration left over from an earlier session (for example restored from an openMSX setup at startup).

Taking over means ejecting what is in the slot, loading the UF2 and inserting the menu in the same slot, then resetting the MSX.

Extensions restored from a setup or savestate are not always reported in their cartridge slot, so the script also looks for the `PicoVerse_2040` extension and its own Nextor configurations in `list_extensions`. It then uses the slot in the `picoverse2040_slot` setting.

### 12.2 UF2 decoding

The UF2 blocks are put back together into the Pico flash image. Blocks marked as not-for-flash, blocks for other chip families (the RP2040 family ID is `0xE48BFF56`) and blocks below the flash base `0x10000000` are skipped; gaps are filled with `0xFF`.

### 12.3 Finding the menu

The MultiROM tool lays out flash as:

```text
[firmware][menu ROM 16KB][config area 16KB][ROM payloads...]
```

All config offsets are relative to the end of the firmware (`__flash_binary_end`), and the firmware size changes from build to build. The script therefore looks, in the first 4MB, for the menu's `AB` header with an INIT address in `0x4000-0xBFFF`, followed by a config area whose first record has a printable name, a known mapper code and points to offset `0x8000`.

Each config record is 59 bytes: name (50 bytes), mapper code (1 byte), size (4 bytes) and offset (4 bytes), up to 128 records. A record of 59 `0xFF` bytes ends the list.

### 12.4 Menu and selection

The 32KB menu and config area are inserted as a `Page12` cartridge (`0x4000-0xBFFF`), exactly as `loadrom_msx_menu()` serves them on the cartridge.

When you pick an entry, the menu writes its index to the ROM select register at `0x9D81` (`ROM_SELECT_REGISTER` in `msx/src/menu.h`) and reboots. A write watchpoint on `0x9D81` catches that write; it only fires while page 2 has the PicoVerse slot (and sub-slot) selected. Outside the CPU emulation loop, the script extracts the entry, inserts it with the matching openMSX mapper and resets the MSX.

### 12.5 Mapper mapping

| PicoVerse code | Menu label | openMSX ROM type | Notes |
| --- | --- | --- | --- |
| 1 | PLA-16 | `Page12` | Padded with `0xFF` to 32KB. The firmware returns `0xFF` above the ROM size. |
| 2 | PLA-32 | `Page12` | |
| 3 | KonSCC | `KonamiSCC` | |
| 4 | PLN-48 | `Page012` | Padded to 48KB. |
| 5 | ASC-08 | `ASCII8` | |
| 6 | ASC-16 | `ASCII16` | |
| 7 | Konami | `Konami` | |
| 8 | NEO-8 | `NEO-8` | |
| 9 | NEO-16 | `NEO-16` | |
| 10 | SYSTEM | generated `PicoVerse2040_Nextor` configuration | Nextor Sunrise IDE. |
| 11 | SYSTEM | generated `PicoVerse2040_Nextor_Mapper` configuration | Nextor Sunrise IDE plus a 192KB memory mapper. |
| 12 | ASC16X | `ASCII16-X` | |
| 13 | PLN-64 | `Page0123` | Padded to 64KB. |
| 14 | MANBW2 | `Manbow2` | |

Banked ROMs are padded to a whole number of banks.

### 12.6 Nextor entries

The Nextor entries are not separate cartridges: like on the hardware, they are options of the PicoVerse menu. openMSX can only build a Sunrise IDE and a memory mapper from an extension configuration, though, so when a Nextor entry boots, the script writes a standard openMSX extension configuration and inserts it into the PicoVerse slot:

- **Nextor Sunrise IDE** (mapper code 10): a `SunriseIDE` device with the Nextor ROM taken from the UF2 and an `IDEHD` master disk.
- **Nextor Sunrise IDE + 192KB Mapper** (mapper code 11): an expanded slot, like `loadrom_sunrise_mapper()` on the cartridge. Sub-slot 0 holds the `SunriseIDE` device and sub-slot 1 a 192KB `MemoryMapper`.

The `IDEHD` master disk is the USB drive image (section 9), with a default size of 100MB when openMSX has to create it.

openMSX lists every configuration in `share/extensions` in its extension menus, so the script keeps these internal configurations out of that folder. It writes them to `persistent/picoverse2040/extensions/PicoVerse2040_Nextor.xml` (or `PicoVerse2040_Nextor_Mapper.xml`) in the openMSX user directory. openMSX resolves an extension name as `share/extensions/<name>.xml`, so the script inserts them with the relative name `../../persistent/picoverse2040/extensions/<name>`. That is also the name that `list_extensions`, setups and savestates record, so they reload the configuration from there. The configurations are rewritten each time a Nextor entry boots. Only **PicoVerse 2040 MultiROM** appears in the extension lists. Earlier versions of the script wrote these configurations to `share/extensions`; the script deletes those generated copies when openMSX starts.

### 12.7 Returning to the menu

The script listens to the openMSX boot event (`after boot`), which fires on every reset and power-up, and to the `power` setting. The reset it issues to start the selected entry is flagged and ignored. Any other boot while an entry is running puts the menu back in the slot and resets the MSX again. If the entry was restored from an earlier session, the script first loads the UF2 in `picoverse2040_uf2`.

While a reverse/replay history is being replayed, boot events are ignored, so replays run as they were recorded.

### 12.8 Machine switches and savestates

After a machine switch or a savestate load, the script looks at the cartridge slots and extensions of the new machine. If the menu ROM is there, it re-arms the `0x9D81` watchpoint. If an extracted ROM or a Nextor configuration is there, it keeps it running and treats it as the selected entry, so the next reset brings the menu back.

### 12.9 Cache files

The menu and the selected ROMs are extracted to `persistent/picoverse2040/cache/<uf2 name>_<size>_<mtime>/` in the openMSX user directory, for example `007_Circus Charlie - Konami (1984) _RC-712_.rom`. openMSX's Tcl has no `zlib`, so the folder is keyed by the UF2 size and modification time, and existing files are compared before reuse. Files that openMSX still keeps open are written under a new name instead of being replaced.

## 13. Limitations

- The emulation is functional, not cycle-exact. openMSX uses its own mapper implementations, so Pico-specific timing such as `/WAIT` stretching is not reproduced.
- openMSX's `KonamiSCC` and `Manbow2` ROM types include the SCC sound chip. The PicoVerse 2040 hardware does not output SCC audio.
- Savestates and replays refer to the extracted files in the cache folder. Keep that folder if you want to reload them.
- Machine switches drop the cartridge, the same as openMSX does for normal cartridges. Insert the **PicoVerse 2040 MultiROM** extension again, or run `picoverse2040 insert`.
- When a `.uf2` is inserted as a ROM image, openMSX briefly runs it as a plain ROM (for up to a quarter of a second) before the script takes over the slot and resets the MSX.
- The USB drive is emulated as an IDE hard disk image; USB-specific behaviour of real thumb drives is not reproduced.

## 14. Troubleshooting

| Symptom | Cause and fix |
| --- | --- |
| The extension shows "No UF2 image selected yet" | No UF2 was chosen yet. Choose the `.uf2` as a ROM image, or run `picoverse2040 insert <file.uf2>`. |
| The extension keeps showing the placeholder text after a UF2 was chosen | `picoverse2040.tcl` is not in `share/scripts` of the openMSX user directory. Run the installer and restart openMSX. |
| `file not found: C:<TAB>emp...` | Backslashes in the console. Use forward slashes or braces (section 7). |
| `no PicoVerse 2040 MultiROM menu found in the UF2 image` | The UF2 is not a MultiROM image (for example a LoadROM or Explorer UF2). |
| A game shows a black screen or crashes | Check the mapper with `picoverse2040 list`. Force the right mapper with a tag in the ROM file name when building the UF2 (see the [MultiROM tool manual](./msx-picoverse-2040-multirom-tool-manual.en-us.md)). |
| Nextor shows no files | The image is blank or was changed while Nextor was running. Fill it as in section 9.3 and start the Nextor entry again. |
| A Nextor entry doesn't start on a C-BIOS machine | Nextor needs a real MSX BIOS with MSX-BASIC. Use such a machine and install its system ROMs in openMSX. |

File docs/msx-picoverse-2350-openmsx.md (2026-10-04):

# MSX PicoVerse 2350 — Explorer in openMSX

This document describes how to run a PicoVerse 2350 Explorer UF2 in the [openMSX](https://openmsx.org/) emulator, as if the cartridge were plugged into the emulated MSX. It covers installation, choosing the UF2 and the emulated microSD card, the Explorer features that work in the emulator, the Nextor, `.DSK` and audio options, the console commands and settings, and how the implementation works.

The openMSX support is part of the Explorer project and lives in [2350/software/explorer.pio/openmsx](../2350/software/explorer.pio/openmsx). It is versioned and built together with the rest of the Explorer project (v2.57 and later), and it runs the UF2s of Explorer v2.56 and later.

## 1. Overview

You point openMSX at the same `.uf2` file you would flash to the PicoVerse 2350. The emulated MSX then boots the real Explorer menu of that UF2 and behaves like the cartridge:

- **Flash list (F1):** the ROMs and SYSTEM entries in the UF2 (Nextor Sunrise 2.1.4 and 3.0.0 Beta 2, Nextor + 1MB mapper, Nextor + MegaRAM, standalone MegaRAM).
- **microSD list (F2):** a folder on your PC plays the microSD card. Its folders, `.ROM`, `.DSK`, `.MP3` and `.WAV` files are listed like on the cartridge.
- **Search, paging, 40/80 columns, help and the ROM detail screen** with mapper detection and the per-ROM options (mapper, audio profile, PSG mirror, volume, 1MB mapper for `.DSK`), saved to `.PVC` files on the emulated microSD card.
- **Copy to flash (F), rename (R) and delete (D)**, including the `Wait NN%` progress of the copy. Flash changes are kept in an editable copy of the flash image, so they survive openMSX restarts, like the real flash.
- **Last selection:** the menu reopens on the entry you ran last (`PICOVERSE.PVL`).
- **Starting entries** with the matching openMSX hardware: the game mappers, the audio profiles (SCC/SCC+ in the game, external SCC/SCC+, MSX-MUSIC, Yamaha SFG-05/SFG-01, Dual PSG), the Nextor entries with a hard disk image, and `.DSK` images through the hidden Nextor 2.1.4 kernel of the UF2.

The Raspberry Pi Pico 2 is not emulated. An openMSX Tcl script does the Explorer firmware's job instead: it serves the menu ROM and answers the menu's commands in the same memory window the Pico uses. A normal openMSX extension makes the cartridge appear in the openMSX menus. You don't need to change or rebuild openMSX.

Typical uses:

- try an Explorer UF2 before flashing it;
- record videos and screenshots of the Explorer features;
- check the mappers the tool and the microSD detector pick;
- prepare a microSD folder (ROMs, `.DSK` images, `.PVC` options) before copying it to the card.

## 2. Requirements

- openMSX 20.0 or newer (tested with 21.0). It needs the `NEO-8`, `NEO-16`, `ASCII16-X` and `Manbow2` ROM types, the `YamahaSFG` device and the `sha1sum` command.
- An Explorer UF2 built with the PicoVerse 2350 Explorer tool (`explorer.exe`) v2.56 or later, see the [Explorer tool manual](./msx-picoverse-2350-explorer-tool-manual.en-us.md).
- An MSX1, MSX2, MSX2+ or turbo R machine with a real MSX BIOS (MSX-BASIC) and its system ROMs installed in openMSX. The FM-PAC, SFG and Nextor ROMs come from the UF2, so no extra system ROMs are needed for them.
- Python 3, only to regenerate the ROM database after the firmware's `romdb.h` changes (see section 4).

## 3. Files

| File | Purpose |
| --- | --- |
| [openmsx/share/scripts/picoverse2350.tcl](../2350/software/explorer.pio/openmsx/share/scripts/picoverse2350.tcl) | The openMSX script. It plays the Explorer firmware and adds the `picoverse2350` console command and four settings. |
| [openmsx/share/extensions/PicoVerse_2350/hardwareconfig.xml](../2350/software/explorer.pio/openmsx/share/extensions/PicoVerse_2350/hardwareconfig.xml) | The **PicoVerse 2350 Explorer** extension shown in the openMSX extension lists: the 32KB cartridge window the script serves. |
| [openmsx/share/extensions/PicoVerse_2350/romdb.txt](../2350/software/explorer.pio/openmsx/share/extensions/PicoVerse_2350/romdb.txt) | SHA1 → mapper table used to detect microSD ROMs, generated from the firmware's `pico/explorer/romdb.h`. |
| [openmsx/gen_romdb.py](../2350/software/explorer.pio/openmsx/gen_romdb.py) | Generates `romdb.txt`. |
| [openmsx/Makefile](../2350/software/explorer.pio/openmsx/Makefile) | Regenerates `romdb.txt` and checks the script version. Called by the Explorer aggregate Makefile. |
| [openmsx/install.ps1](../2350/software/explorer.pio/openmsx/install.ps1) / [openmsx/install.sh](../2350/software/explorer.pio/openmsx/install.sh) | Install the script and the extension for the current user. |

The `openmsx/share` folder uses the same layout as the openMSX `share` folder. openMSX loads every `*.tcl` file in `share/scripts` at startup and lists every extension in `share/extensions`.

The PicoVerse 2040 MultiROM add-on ([MSX PicoVerse 2040 — MultiROM in openMSX](./msx-picoverse-2040-openmsx.md)) can be installed next to this one. Each script only takes over the UF2s of its own board (RP2040 or RP2350).

## 4. Building

The openMSX add-on is built by the Explorer aggregate Makefile, together with the MSX menu, the Pico firmware and the tool:

```sh
cd 2350/software/explorer.pio
make            # msx -> pico -> tool, and openmsx
make openmsx    # only the openMSX add-on
```

The `openmsx` stage regenerates `share/extensions/PicoVerse_2350/romdb.txt` with `gen_romdb.py` when `pico/explorer/romdb.h` is newer (set `PYTHON` if `python` is not your Python 3). The aggregate Makefile passes `VERSION`, and the stage fails if the `variable version` line in `picoverse2350.tcl` doesn't match it. Bump both when the Explorer version changes. Running `make` inside `openmsx/` without `VERSION` skips the check.

`romdb.txt` is committed, so you only need Python when the ROM database changes.

## 5. Installation

Run the installer for your system. It copies `share/scripts/picoverse2350.tcl` and `share/extensions/PicoVerse_2350` into the `share` folder of your openMSX user directory:

```powershell
# Windows (installs to Documents\openMSX\share, or to $env:OPENMSX_HOME\share)
powershell -ExecutionPolicy Bypass -File 2350\software\explorer.pio\openmsx\install.ps1
```

```sh
# Linux / macOS (installs to ~/.openMSX/share, or to $OPENMSX_HOME/share)
sh 2350/software/explorer.pio/openmsx/install.sh
```

Both installers also accept the openMSX user directory as an argument (`install.ps1 -OpenMSXHome <dir>`, `install.sh <dir>`).

Restart openMSX afterwards. **PicoVerse 2350 Explorer** then shows up in the extension lists, and `help picoverse2350` works in the console (F10). Run the installer again after updating the repository.

## 6. Quick start

1. Start openMSX with any MSX machine.
2. Open the console (F10) and choose the folder that plays the microSD card:
   ```
   set picoverse2350_sd C:/MSX/SD
   ```
   Without it, the script uses an empty `picoverse2350/sd` folder in the openMSX persistent folder.
3. Open **Media > Cartridge Slot A** and choose **ROM image**. Browse to your Explorer `.uf2` file (switch the file type filter to **All files (\*)**, because openMSX only lists ROM files by default) and insert it.
4. The MSX resets and shows the Explorer menu. Use it as on the cartridge: cursor keys, F1 (flash), F2 (microSD), Enter (detail screen), Space (run), `/` (search), `H` (help).

Reset the MSX to go back to the menu. From now on, inserting the **PicoVerse 2350 Explorer** extension loads the same UF2.

## 7. Choosing the UF2

### 7.1 As a cartridge ROM image (GUI)

Select the `.uf2` as the ROM image of a cartridge slot (**Media > Cartridge Slot A/B > ROM image**). The script notices the UF2 within a fraction of a second, replaces it with the PicoVerse 2350 cartridge in the same slot and resets the MSX.

### 7.2 With the PicoVerse 2350 Explorer extension

Insert **PicoVerse 2350 Explorer** from **Media > Extensions > Insert** (or a Cartridge Slot window). It loads the UF2 in setting `picoverse2350_uf2`, which always holds the last UF2 used. Without a UF2, the MSX shows how to select one.

### 7.3 From the command line

```sh
openmsx -machine Philips_NMS_8250 -carta explorer.uf2
openmsx -machine Philips_NMS_8250 -ext PicoVerse_2350
```

### 7.4 From the console

```
picoverse2350 insert C:/MSX/explorer.uf2 -sd C:/MSX/SD -hd C:/MSX/nextor.dsk
```

In the openMSX console, backslashes are escape characters: use forward slashes, or put the path between braces (`{C:\MSX\explorer.uf2}`).

### 7.5 Rebuilt UF2 files and the emulated flash

The first time a UF2 is used, the script decodes it and keeps an editable copy of the flash in `persistent/picoverse2350/flash/<name>_<size>_<date>.img`. Copies, renames and deletes made from the menu change that copy, never the UF2. A rebuilt UF2 (other size or date) starts from a fresh copy, like flashing the cartridge again. `picoverse2350 reflash` discards the changes and starts again from the UF2.

## 8. The emulated microSD card

A folder on your PC plays the microSD card. It is chosen, in this order, by the `-sd` option of the last `picoverse2350 insert`, setting `picoverse2350_sd`, or the default `persistent/picoverse2350/sd` folder of your openMSX user directory.

Like the firmware, the menu lists:

- folders (except `System Volume Information`), sorted by name, with `..` in subfolders;
- `.ROM` files from 8KB to 4MB, with the mapper from a filename tag (`Game.Konami.ROM`) or, when needed, from the detector (SHA1 database, then heuristics, the same as the firmware);
- `.DSK` files whose size is a multiple of 360KB, up to 4MB;
- `.MP3` and `.WAV` files (listed, but not played, see section 13);
- in the root folder, the flash entries too (only shown in the combined list).

The script writes to that folder exactly like the firmware writes to the card, so keep a copy of anything you care about:

| File | Written when |
| --- | --- |
| `<rom>.PVC`, `<image>.DSK.PVC` | The options of a microSD ROM or `.DSK` are saved. |
| `/<flash entry>.flash.PVC` | The options of a flash entry are saved; renamed, copied and deleted together with the entry. |
| `/PICOVERSE.PVL` | An entry is started (last selection). |

Renaming (R) and deleting (D) a microSD entry renames or deletes the file in the folder, with its `.PVC`.

## 9. Copy to flash, rename and delete

These v2.57 features work as on the cartridge:

- **F** in the microSD list copies the selected ROM to flash after `To flash? Y/N`. The menu shows `Wait NN%` while the copy runs (about 200KB/s of emulated time, like the real flash), and the ROM then appears in the F1 list. The script applies the firmware rules: no folders, MP3/WAV, `.DSK`, SYSTEM mappers or duplicate names; at most 128 flash entries; the image goes to the lowest free 4KB-aligned gap after the hidden payloads; the entry is appended to the next free config slot, and the config area is compacted when all 204 slots have been used. The ROM's `.PVC` is copied to `/<name>.flash.PVC`.
- **R** renames a microSD ROM/`.DSK` (the folder, mapper tag and extension are kept) or a flash entry (appended under the new name, then the old slot is tombstoned). The list reopens on the renamed entry.
- **D** deletes a microSD file (with its `.PVC`) or a flash entry (its slot is tombstoned).

## 10. Starting entries

| Entry | openMSX hardware |
| --- | --- |
| Game ROM, no extra audio | The ROM in the cartridge slot with the openMSX mapper of the PicoVerse mapper code (`Page12`, `Page012`, `Page0123`, `KonamiSCC`, `Konami`, `ASCII8`, `ASCII16`, `NEO-8`, `NEO-16`, `ASCII16-X`, `Manbow2`). Planar ROMs are padded with 0xFF to the window the firmware serves. |
| Game ROM + External SCC / SCC+ | Expanded slot: the ROM in subslot 0, an SCC cartridge or an SCC+ (expanded mode) in subslot 2. |
| Game ROM + MSX-MUSIC | Expanded slot: the ROM in subslot 0, an FM-PAC with the FM-PAC BIOS of the UF2 in subslot 3. |
| Game ROM + YM2151 SFG-05 / SFG-01 | Expanded slot: the ROM in subslot 0, a Yamaha SFG (YM2164 or YM2151) with the SFG BIOS of the UF2 in subslot 2. |
| Game ROM + Dual PSG | A second PSG on ports 0x10-0x13, next to the ROM. |
| Nextor Sunrise 2.1.4 / 3.0.0 Beta 2 (SD or USB) | Sunrise IDE with the entry's own Nextor kernel and the hard disk image (section 11). |
| Nextor + 1MB Mapper | Expanded slot: Sunrise IDE in subslot 0, a 1MB memory mapper in subslot 1. |
| Nextor + 1MB Mapper + 1MB MegaRAM | As above, plus a 1MB MegaRAM (port 0x8E) in subslot 3. |
| Nextor + 1MB Mapper + C2 RAM | Started as Nextor + 1MB mapper; the Carnivore2 RAM registers are not emulated. |
| Brazilian MegaRAM (1MB) | A 1MB MegaRAM in the cartridge slot; the MSX boots to BASIC with it. |
| `.DSK` image | Sunrise IDE with the hidden Nextor 2.1.4 kernel of the UF2 and the `.DSK` file itself as the disk, plus the 1MB mapper when **1MB Mapper** is **Yes**. The DSK audio profiles (External SCC/SCC+, MSX-MUSIC, SFG-05/SFG-01, Dual PSG) are added as above. Writes go straight to the `.DSK` file, like the firmware's write-through. |

The audio profile follows the firmware's `resolve_audio_mode()`: the option saved in the `.PVC` or chosen on the detail screen, with the same restrictions per mapper. The SCC/SCC+ profiles of Konami SCC and Manbow 2 games use the SCC built into the openMSX mapper. The 4 MHz SFG variants use the standard SFG clock.

The selected entry is started like the firmware does it: the script swaps the cartridge and resets the MSX. Any later reset, a power cycle, or restarting openMSX with the entry still in the slot brings back the menu, which reopens on the last entry.

## 11. Hard disk image of the Nextor entries

On the cartridge, the Nextor SD entries use a partition of the microSD card and the USB entries use a USB drive. In openMSX, both use a hard disk image, chosen in this order: the `-hd` option of the last `picoverse2350 insert`, setting `picoverse2350_hd` (read every time a Nextor entry boots), or `persistent/picoverse2350/hd.dsk` (created empty, 100MB, the first time).

```
set picoverse2350_hd C:/MSX/nextor.dsk
```

A new empty image needs a partition: in Nextor BASIC, `CALL FDISK`. To create an image and copy a PC folder into it, use the openMSX `diskmanipulator`, as described in [MSX PicoVerse 2040 — MultiROM in openMSX](./msx-picoverse-2040-openmsx.md) (section 9.3); the steps are the same.

The microSD folder (section 8) and the Nextor image are separate: the menu does not see the files inside the image, and Nextor does not see the folder.

## 12. Console command and settings

```
picoverse2350 insert <file.uf2> [-slot <a|b>] [-sd <folder>] [-hd <image>]
picoverse2350 insert            re-insert the last UF2
picoverse2350 menu              back to the menu (same as a reset)
picoverse2350 list              list the flash entries
picoverse2350 info              current UF2, flash copy, slot, microSD folder, HD image, state
picoverse2350 reflash           discard the flash changes, start again from the UF2
picoverse2350 eject             remove the cartridge
```

| Setting | Meaning |
| --- | --- |
| `picoverse2350_uf2` | Last UF2 used, loaded by the extension. |
| `picoverse2350_slot` | Default cartridge slot (`a`). |
| `picoverse2350_sd` | Folder used as the microSD card (empty: `persistent/picoverse2350/sd`). |
| `picoverse2350_hd` | Hard disk image of the Nextor entries (empty: `persistent/picoverse2350/hd.dsk`). |

## 13. Limitations

- **MP3/WAV playback** is not emulated: the files are listed and the player reports an error.
- **File Hunter and WiFi** are not emulated: the menu reports the WiFi module offline, and the WiFi setup option resets to the menu.
- **VDP frequency (50/60 Hz) and CPU mode** options are saved, but not applied to the emulated MSX. Use the openMSX settings instead. The audio volume and PSG mirror options have no effect either.
- **Multi-disk `.DSK` images** (several disks joined into one file) boot the first disk only; the GRAPH + key disk switching is not emulated.
- **ASC16X-FR** ROMs run as ASCII16-X; FlashROM saves (`.FLA`) are not emulated.
- **Carnivore2** entries start as Nextor + 1MB mapper (section 10).
- **WaveGame** assets are not detected.
- The Nextor SD entries use a hard disk image, not the microSD folder (section 11), and only one partition is offered.
- Bus-level behaviour of the RP2350 (PIO timing, `/WAIT`) is not emulated: firmware fixes at that level can only be tested on hardware.

## 14. How it works

### 14.1 The cartridge window

The PicoVerse_2350 extension maps a 32KB RAM device at 0x4000-0xBFFF. The script loads the menu ROM of the UF2 into it and serves the Pico control area of `msx/src/menu.h` there: the page buffer at 0xB900-0xBF7F, the ROM select register at 0xBF7F, the partition info / status text at 0xBF80, `CTRL_VDP_FREQ`..`CTRL_DISK_ACT` at 0xBFA0, the chip ID at 0xBFAF, the query buffer at 0xBFC0, the MP3 registers at 0xBFE0 and the control registers at 0xBFF0.

A write watchpoint on 0x4000-0xBFFF (only while the cartridge is selected in that page) runs `handle_menu_write_explorer()`'s logic for every MSX write: query and rename buffers, commands (`CTRL_CMD`), page requests, option registers and the ROM select register. The script answers synchronously, then puts back the byte the Pico serves at the written address. The MSX therefore never sees RAM in the window, which matters because the BIOS RAM probe at boot writes to the top of page 2. Writes made by BIOS code (PC below 0x4000) are only restored, never executed as commands.

The commands follow the firmware: the paged record list (`PVEX` header, record table, string pool, TLV records), the filter and find-first search, source switching, folders, mapper detection and override, `.PVC` load/save, quick run, last selection, partition cycling, delete, copy to flash and rename. The copy runs in steps of 0.1 s of emulated time and reports its percentage in `CTRL_MAPPER`.

### 14.2 UF2 decoding and the flash copy

The UF2 blocks of the RP2350 families are assembled into a flat flash image. The menu ROM is the first 4KB boundary after the firmware since v2.57 (`FIRMWARE_ALIGN`), and right after it before, so the script checks the aligned positions first and then searches for the `AB` header followed by a valid config area. The image from the menu ROM on is saved as the editable flash copy. Record offsets are relative to the menu ROM, as in the firmware (`flash_rom`).

### 14.3 Starting an entry

When the menu writes the ROM select register, the script takes the record (using the 16-bit index the menu just stored as last selection, so lists longer than 255 entries work), resolves the audio profile, writes an openMSX extension for it to `persistent/picoverse2350/extensions/PicoVerse2350_Boot.xml` (outside `share/extensions`, so openMSX does not list it), inserts it, or the plain ROM, in the cartridge slot and resets the MSX. ROM files and the FM-PAC, SFG and Nextor ROMs extracted from the UF2 are cached in `persistent/picoverse2350/cache`.

### 14.4 Returning to the menu, machine switches and savestates

Any reset, except the one issued to start an entry, a power cycle, or restarting openMSX with an entry in the slot (restored setup) brings back the menu. After a machine switch or a savestate load, the script re-attaches to the menu if it is in a slot, or lets the running entry continue until the next reset.

## 15. Troubleshooting

| Problem | Solution |
| --- | --- |
| The extension is not in the list | Run the installer and restart openMSX. |
| The MSX shows "no UF2 selected" | Insert the `.uf2` as ROM image, or `picoverse2350 insert <file.uf2>`. |
| `File not found` with a Windows path in the console | Use forward slashes or braces around the path. |
| The microSD list says "No microSD card" | The microSD folder does not exist: check `picoverse2350 info` and setting `picoverse2350_sd`. |
| Copies/renames/deletes are gone | The UF2 was rebuilt (a new flash copy is used), or `picoverse2350 reflash` was run. |
| Nextor says it has no drive | The hard disk image has no partition: use `CALL FDISK`, or point `picoverse2350_hd` to a prepared image. |
| A 2040 UF2 is selected | Use the PicoVerse 2040 add-on (`picoverse2040 insert`). |

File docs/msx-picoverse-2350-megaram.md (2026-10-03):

# MSX PicoVerse 2350 MegaRAM Implementation

This document describes the MegaRAM support added to PicoVerse 2350 LoadROM and Explorer for the new Nextor system modes:

| Option | Storage backend | System image |
| --- | --- | --- |
| `-r1`, `--megaram-sd` | microSD Sunrise IDE | Nextor + 1MB MSX memory mapper + 1MB MegaRAM |
| `-r2`, `--megaram-usb` | USB Sunrise IDE | Nextor + 1MB MSX memory mapper + 1MB MegaRAM |

These modes are intended for MSX software and loaders that know how to use a MegaRAM cartridge: RAM that behaves like a writable MegaROM cartridge, with four 8KB banked cartridge windows. The PicoVerse implementation keeps Nextor storage and the normal MSX memory mapper available while adding a separate MegaRAM surface in the same expanded-slot cartridge. The control behavior follows the Cartucho II / SDMapper MegaRAM convention, extended from 512KB to 1MB by using seven bank bits.

## Historical Background

MegaRAM is a Brazilian MSX cartridge concept created by Ademir Carchano in 1987. The goal was practical and very MSX: let users load MegaROM cartridge games from disk into RAM, then run them through a cartridge-like banked memory interface instead of requiring the original ROM cartridge to be present.

MSX.org describes MegaRAM generically as a cartridge containing RAM mapped like a MegaROM, normally write-protected by default, and volatile when the MSX is powered off. Contemporary community discussions and preservation pages refer to Brazilian 512KB MegaRAM cartridges made by Ademir Carchano, later 2048KB boards, and the broader family of MegaRAM devices that followed. Brazilian articles about the history of MSX hardware describe the first MegaRAM work as coming after analysis of Konami MegaROM cartridges such as Nemesis, with `MEGARAM.BIN` becoming a common loader for disk-distributed MegaROM games.

Useful public references:

- [MSX.org Wiki: MegaRAM](https://www.msx.org/wiki/MegaRAM)
- [MSX.org forum: Brazilian MEGARAM - 512k made by Ademir Carchano](https://www.msx.org/forum/msx-talk/trading-and-collecting/brazilian-megaram-512k-made-ademir-carchano?page=1)
- [MSX.org forum: New MEGARAM 2048Kb from Ademir Carchano](https://www.msx.org/forum/msx-talk/trading-and-collecting/new-megaram-2048kb-ademir-carchano)
- [MegaRam MSX - Registros e Patentes](https://inventores.com.br/megaram-msx/)

## Tribute to Ademir Carchano

The PicoVerse 2350 MegaRAM mode is a tribute to Ademir Carchano's original MegaRAM idea and to the Brazilian MSX hardware culture around it. MegaRAM was not just another memory expansion; it was a clever answer to the scarcity and cost of imported cartridge software in Brazil, using banked RAM and loaders to make MegaROM-style software practical from local storage.

PicoVerse does not copy original MegaRAM hardware circuitry. It implements a compatible cartridge behavior in RP2350 firmware, backed by PSRAM, so modern PicoVerse users can experiment with the same class of software workflow while keeping the original inventor's contribution visible in the documentation and credits.

## User-Facing Behavior

The new LoadROM modes build dedicated Nextor system UF2 images. They do not take an external ROM file:

```text
loadrom.exe -r1
loadrom.exe -r1 -o nextor_megaram_sd.uf2

loadrom.exe -r2
loadrom.exe -r2 -o nextor_megaram_usb.uf2
```

At boot, the MSX sees an expanded cartridge in the physical PicoVerse slot. The cartridge contains:

- The embedded Nextor 2.1.4 Sunrise IDE ROM and Sunrise IDE register surface.
- A 1MB MSX memory mapper using standard mapper ports `0xFC`-`0xFF`.
- A separate 1MB MegaRAM, exposed as four switchable 8KB cartridge pages.

The SD mode (`-r1`) uses the on-board microSD card through the same Sunrise IDE backend as `-s1` and `-m1`. The USB mode (`-r2`) uses the USB mass-storage backend used by `-s2` and `-m2`.

## Expanded Slot Layout

The `-r1` and `-r2` modes use the same two-phase expanded-slot bootstrap used by the existing Sunrise + mapper modes. The first phase serves a tiny restart ROM so the MSX BIOS probes the cartridge again after the firmware has configured the full expanded-slot layout.

After that restart, the runtime layout is:

| Subslot | Content | Purpose |
| --- | --- | --- |
| `P-0` | Nextor ROM + Sunrise IDE | Boots Nextor and exposes the disk interface. |
| `P-1` | 1MB MSX memory mapper | Standard mapper RAM for MSX-DOS/Nextor, controlled by ports `0xFC`-`0xFF`. |
| `P-2` | Unused | Open bus. |
| `P-3` | 1MB MegaRAM | Writable Cartucho II-compatible 8KB banked cartridge RAM. |

`P` is the physical primary slot where the PicoVerse cartridge is inserted. The expanded slot register at `0xFFFF` is handled normally: writes select the active subslot per 16KB CPU page, and reads return the bitwise complement of the stored register.

The default expanded-slot register is `0x10`, matching the existing Sunrise + mapper boot arrangement: page 1 selects Nextor in subslot 0 for BIOS scanning, and page 2 selects mapper RAM in subslot 1 so the mapper can be discovered by the MSX.

## MegaRAM Capacity and Banks

The MegaRAM region uses 1MB of external PSRAM:

| Property | Value |
| --- | --- |
| Total size | 1MB (`1048576` bytes) |
| Bank size | 8KB (`8192` bytes) |
| Bank count | 128 |
| Bank numbers | `0`-`127` |
| Significant bank bits | bits `0`-`6`; bit `7` is ignored |

On reset, the four visible page registers are initialized to sequential banks:

```text
bank_reg[0] = 0
bank_reg[1] = 1
bank_reg[2] = 2
bank_reg[3] = 3
```

The PSRAM region is filled with `0xFF` at startup so an empty MegaRAM behaves like erased/open cartridge memory until software explicitly enables writes and loads data.

## MSX Visible Memory Map

The MegaRAM responds only when its subslot is selected and the CPU accesses the cartridge memory window `0x4000`-`0xBFFF`.

| Address range | MegaRAM page | Bank register | Physical offset |
| --- | --- | --- | --- |
| `0x4000`-`0x5FFF` | page 2 | `bank_reg[2]` | `(bank_reg[2] << 13) | (addr & 0x1FFF)` |
| `0x6000`-`0x7FFF` | page 3 | `bank_reg[3]` | `(bank_reg[3] << 13) | (addr & 0x1FFF)` |
| `0x8000`-`0x9FFF` | page 0 | `bank_reg[0]` | `(bank_reg[0] << 13) | (addr & 0x1FFF)` |
| `0xA000`-`0xBFFF` | page 1 | `bank_reg[1]` | `(bank_reg[1] << 13) | (addr & 0x1FFF)` |

Reads outside `0x4000`-`0xBFFF` are not claimed by the MegaRAM subslot.

## Bank Switching

When MegaRAM writes are disabled, memory writes in the visible `0x4000`-`0xBFFF` window update one of the four bank latches. The latch is selected by address bits A14:A13, matching the Cartucho II / SDMapper CPLD behavior:

| Write address range | Address bits A14:A13 | Effect |
| --- | --- | --- |
| `0x4000`-`0x5FFF` | `10` | `bank_reg[2] = data & 0x7F` |
| `0x6000`-`0x7FFF` | `11` | `bank_reg[3] = data & 0x7F` |
| `0x8000`-`0x9FFF` | `00` | `bank_reg[0] = data & 0x7F` |
| `0xA000`-`0xBFFF` | `01` | `bank_reg[1] = data & 0x7F` |

Only bits `0`-`6` of the written byte are used, giving 128 possible 8KB banks. Bit `7` is ignored. Original 512KB SDMapper/CPLD hardware used six bank bits; PicoVerse keeps the same latch behavior and expands the bank mask to seven bits for 1MB.

When MegaRAM writes are enabled, memory writes in `0x4000`-`0xBFFF` store bytes into the selected bank/page instead of changing the bank latches.

## Write Enable Control

MegaRAM RAM writes are disabled after reset:

```text
write_enabled = false
```

The PicoVerse implementation follows the Cartucho II / SDMapper write-enable convention on I/O ports `0x8E` and `0x8F`:

| I/O access | Effect |
| --- | --- |
| `IN 0x8E` or `IN 0x8F` | Enable MegaRAM RAM writes |
| `OUT 0x8E, data` or `OUT 0x8F, data` | Disable MegaRAM RAM writes and return memory writes to bank-latch mode |

The data byte written by `OUT` is ignored. The I/O read is used as a control strobe; the firmware does not return a meaningful MegaRAM data value on these ports.

When writes are enabled, memory writes to `0x4000`-`0xBFFF` store the byte into the currently selected bank/page.

When writes are disabled, memory writes in `0x4000`-`0xBFFF` update the bank latch selected by A14:A13.

## Read and Write Algorithms

### Memory read

```c
if (selected && RD && address >= 0x4000 && address <= 0xBFFF) {
    page = (address >> 13) & 0x03;
    offset = address & 0x1FFF;
    bank = bank_reg[page] & 0x7F;
    data = megaram[(bank << 13) | offset];
}
```

### Memory write

```c
if (selected && WR && address >= 0x4000 && address <= 0xBFFF) {
    page = (address >> 13) & 0x03;
    if (write_enabled) {
        offset = address & 0x1FFF;
        bank = bank_reg[page] & 0x7F;
        megaram[(bank << 13) | offset] = data;
    } else {
        bank_reg[page] = data & 0x7F;
    }
}
```

### I/O control

```c
if (IORQ && RD && (port == 0x8E || port == 0x8F))
    write_enabled = true;

if (IORQ && WR && (port == 0x8E || port == 0x8F))
    write_enabled = false;
```

## Bus Behavior

The MegaRAM follows the normal PicoVerse PIO bus rules:

- It responds only when the PicoVerse physical slot is selected through `/SLTSL`.
- It drives the data bus only during valid selected cartridge reads.
- It never drives the data bus during writes.
- It leaves reads outside `0x4000`-`0xBFFF` unclaimed for the MegaRAM subslot.
- I/O reads from `0x8E`/`0x8F` are treated as write-enable strobes and do not return a meaningful MegaRAM data byte.
- I/O writes to `0x8E`/`0x8F` disable MegaRAM RAM writes and return the cartridge to bank-latch mode.

The standard MSX memory mapper I/O ports `0xFC`-`0xFF` remain reserved for the 1MB MSX memory mapper in subslot 1. MegaRAM bank switching uses memory writes, not mapper I/O ports.

## PSRAM Allocation

The `-r1`/`-r2` firmware allocates two 1MB PSRAM regions at startup:

| Region | Size | Use |
| --- | --- | --- |
| `mapper_region` | 1MB | MSX memory mapper, 64 x 16KB pages |
| `megaram_region` | 1MB | MegaRAM, 128 x 8KB banks |

Both are allocated from the existing RP2350 PSRAM bump allocator. This is well within the 8MB PSRAM available on supported PicoVerse 2350 hardware.

## Source Files

LoadROM paths below are relative to `2350/software/loadrom.pio/`.

| File | Role |
| --- | --- |
| `tool/src/loadrom.c` | Adds `-r1`/`--megaram-sd`, `-r2`/`--megaram-usb`, mapper types 19/20, help text, and embedded Nextor UF2 generation. |
| `pico/loadrom/loadrom.h` | Defines `MEGARAM_SIZE`, `MEGARAM_BANKS`, and `MEGARAM_BANK_SIZE`. |
| `pico/loadrom/loadrom.c` | Allocates MegaRAM PSRAM, handles bank registers, ports `0x8E`/`0x8F`, expanded-slot dispatch, memory reads, and memory writes. |
| `pico/loadrom/sunrise_ide.c` | Existing Sunrise IDE front-end used by the same Nextor storage path. |
| `pico/loadrom/sunrise_sd.c` | microSD backend used by `-r1`. |
| `tool/Makefile` | Embeds the firmware and Nextor ROM into `loadrom.exe`. |
| `resources/Nextor-2.1.4.SunriseIDE.MasterOnly.ROM` | Embedded Nextor Sunrise IDE ROM used by both MegaRAM modes. |

Explorer uses the same mapper IDs and MegaRAM bus behavior under `2350/software/explorer.pio/`:

| File | Role |
| --- | --- |
| `tool/src/explorer.c` | Adds `-r1`/`--megaram-sd`, `-r2`/`--megaram-usb`, `-a`/`--allnextor`, mapper types 19/20, help text, and embedded Nextor entries while still appending scanned folder ROMs. |
| `pico/explorer/explorer.h` | Defines `MEGARAM_SIZE`, `MEGARAM_BANKS`, and `MEGARAM_BANK_SIZE` for Explorer. |
| `pico/explorer/explorer.c` | Allocates MegaRAM PSRAM, handles bank registers, ports `0x8E`/`0x8F`, expanded-slot dispatch, memory reads, memory writes, and Explorer launch dispatch for mapper IDs 19/20. |
| `msx/src/screen_rom.c` | Offers PSG Mirror, MSX-MUSIC and the MegaRAM SCC/SCC+ profiles for the Nextor MegaRAM entries; WiFi and the other external-audio launch selections are not offered. |
| `msx/src/menu.c` | Displays MegaRAM mapper IDs 19/20 as `SYSTEM`. |

## Current Limitations

- MegaRAM support is currently exposed by LoadROM and Explorer. MultiROM does not expose `-r1`/`-r2` MegaRAM entries yet.
- The MegaRAM contents are volatile. They are cleared to `0xFF` on cartridge startup and lost when the MSX is powered off.
- The implementation provides the MegaRAM hardware surface; software still needs a MegaRAM-aware loader or patched game workflow to load and run data from it.
- The implementation follows the Cartucho II / SDMapper write-enable convention, where I/O reads from `0x8E`/`0x8F` enable RAM writes and I/O writes to those ports disable RAM writes.

Author: Cristiano Almeida Goncalves
Last updated: 06/27/2026

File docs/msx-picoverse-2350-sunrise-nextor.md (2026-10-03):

# MSX PicoVerse 2350 — Sunrise IDE Emulation for Nextor

This document describes the implementation of the Sunrise IDE interface emulation modes in the MSX PicoVerse 2350 firmware. The 2350 variant supports two distinct storage backends — microSD card and USB mass storage — each available standalone, combined with a 1MB PSRAM-backed memory mapper, combined with that mapper plus Carnivore2-compatible RAM-mode loading for `SROM.COM /D15`, or combined with the mapper plus a separate 1MB MegaRAM subslot. The four non-Carnivore2/non-MegaRAM Sunrise modes can also optionally expose ESP-01 WiFi support when built with `-w` in either `loadrom.exe` or `multirom.exe`, or when enabled from the Explorer ROM details screen. Explorer uses the same `-s1`/`-m1`/`-c1`/`-r1` and `-s2`/`-m2`/`-c2`/`-r2` option names to add embedded Nextor SYSTEM entries alongside the ROMs scanned from the source folder, and `-a` / `--allnextor` adds all eight entries at once, plus the `-s3` Nextor 3 beta microSD entry.

## 1. Overview

The MSX PicoVerse 2350 provides a complete Sunrise IDE emulation that allows the MSX to boot Nextor DOS and access mass storage through either the on-board microSD card slot or the USB-C port. Eight firmware modes are available:

| Option | Mapper Type | Storage Backend | Description |
|---|---|---|---|
| `-s1` / `--sunrise-sd` | 15 | microSD (SPI) | Sunrise IDE with microSD card |
| `-m1` / `--mapper-sd` | 16 | microSD (SPI) | Sunrise IDE + 1MB PSRAM mapper with microSD card |
| `-c1` / `--carnivore2-sd` | 17 | microSD (SPI) | Sunrise IDE + 1MB PSRAM mapper + Carnivore2 RAM-mode target for `SROM.COM /D15` |
| `-r1` / `--megaram-sd` | 19 | microSD (SPI) | Sunrise IDE + 1MB PSRAM mapper + 1MB MegaRAM |
| `-s2` / `--sunrise-usb` | 10 | USB-C (MSC) | Sunrise IDE with USB pendrive |
| `-m2` / `--mapper-usb` | 11 | USB-C (MSC) | Sunrise IDE + 1MB PSRAM mapper with USB pendrive |
| `-c2` / `--carnivore2-usb` | 18 | USB-C (MSC) | Sunrise IDE + 1MB PSRAM mapper + Carnivore2 RAM-mode target for `SROM.COM /D15` |
| `-r2` / `--megaram-usb` | 20 | USB-C (MSC) | Sunrise IDE + 1MB PSRAM mapper + 1MB MegaRAM |

All eight modes:

- Emulate the Sunrise IDE FlashROM banking for the 128KB Nextor ROM image (8 × 16KB pages)
- Emulate the full ATA task-file register set at `0x7C00`–`0x7EFF`
- Translate ATA sector read/write commands into block I/O operations on the chosen storage device
- Run the Nextor 2.1.4 Sunrise IDE driver (Master Only edition)
- Use the RP2350's dual-core architecture: Core 0 for PIO bus and IDE register handling, Core 1 for storage backend

The mapper variants (`-m1`, `-m2`) additionally provide 1MB of mapper RAM (64 × 16KB pages) in an expanded sub-slot architecture, with mapper page registers intercepted via PIO1.

The Carnivore2 RAM-mode variants (`-c1`, `-c2`) build on that same mapper architecture and add a Carnivore2-compatible control/register surface plus banked RAM windows so `SROM.COM /D15` can upload ROM images into PSRAM and launch them directly from RAM.

The MegaRAM variants (`-r1`, `-r2`) also build on the mapper architecture. They add a separate 1MB MegaRAM in subslot 3, implemented as 128 x 8KB writable banks with four visible windows in `0x4000`-`0xBFFF`, Cartucho II-compatible `IN (0x8E/0x8F)` write enable, `OUT (0x8E/0x8F)` write disable, and bank-latch writes selected by address bits A14:A13. See the dedicated [MegaRAM implementation guide](./msx-picoverse-2350-megaram.md) for register-level details and historical notes.

The `-w` WiFi flag is available for `-s1`, `-m1`, `-s2`, and `-m2`. It does not create new mapper IDs; instead, it sets an additional configuration flag that makes the firmware expose a WiFi subslot containing the ESP8266P system ROM and memio UART surface. See the dedicated WiFi guide for the full register-level details.

### Nextor partition requirements and Explorer selection

Nextor storage uses the Sunrise IDE block device and should be prepared with FAT16 partitions up to 4 GB for reliable MSX-DOS/Nextor access. FAT32 and exFAT partitions can be useful on the same microSD card for Explorer browsing, ROM loading, MP3/WAV playback, or File Hunter downloads, but they are not valid boot/storage partitions for Sunrise Nextor SYSTEM entries.

In Explorer, Sunrise Nextor SD SYSTEM entries scan the microSD partition table and offer only compatible FAT16 partitions up to 4 GB in the ROM detail screen. The `SD Part` option shows the filesystem volume label when available; use Left/Right to choose between compatible partitions. The selected partition is stored in that ROM's `.PVC` options file, so each Sunrise Nextor SYSTEM entry can remember its own FAT16 partition.

The normal Explorer `F2` microSD browser has different rules: it can cycle through supported FAT16, FAT32, and exFAT primary/logical partitions with `P`, saves the current browsing partition in `/PICOVERSE.PVC`, and displays the selected partition label plus free-space status. This partition selection is for Explorer file browsing and does not make FAT32/exFAT partitions valid for Nextor.

## 2. Architecture

All eight modes share an identical ATA front-end on Core 0. Core 1 runs the appropriate storage backend depending on the mapper type.

### Shared ATA Front-End

The Sunrise IDE ATA emulation is implemented in `sunrise_ide.c` and provides:

- **Segment/IDE control register** at `0x4104` (write-only) — FlashROM page select with bit-reversed bank number + IDE enable bit
- **16-bit data register** at `0x7C00`–`0x7DFF` — with low/high byte latch for MSX 8-bit bus
- **ATA task-file registers** at `0x7E00`–`0x7EFF` — mirrored every 16 bytes
- **ATA commands**: IDENTIFY DEVICE (`0xEC`), READ SECTORS (`0x20`), WRITE SECTORS (`0x30`), EXECUTE DEVICE DIAGNOSTIC (`0x90`), DEVICE RESET (`0x08`), SET FEATURES (`0xEF`), INIT PARAMS (`0x91`), RECALIBRATE (`0x10`)

The front-end sets volatile request flags (`usb_read_requested`, `usb_write_requested`) that are serviced by whichever backend runs on Core 1.

### USB Backend (Types 10, 11)

`sunrise_ide.c` — `sunrise_usb_task()`:

```
┌─────────────────────────────────────────────────────┐
│  Core 1 — USB Backend                               │
│  ┌───────────────────────────────────────────────┐  │
│  │  TinyUSB host stack (Full Speed)              │  │
│  │  tuh_task() polling loop                      │  │
│  │  tuh_msc_read10() / tuh_msc_write10()         │  │
│  │  SCSI INQUIRY → vendor/product/revision       │  │
│  │  Async callbacks with timeout watchdog        │  │
│  └───────────────────────────────────────────────┘  │
└────────────────────────┬────────────────────────────┘
                         │ USB Host (Full Speed)
                  ┌──────▼──────┐
                  │   USB-C     │
                  │ Mass Storage│
                  │   Device    │
                  └─────────────┘
```

- Transfers are asynchronous via TinyUSB callbacks
- A 3-second timeout watchdog prevents stalled transfers from keeping the IDE in BSY
- Supports devices with non-512-byte native sectors by reading the native block and extracting the correct 512-byte slice
- Device info for IDENTIFY comes from the USB SCSI INQUIRY response

### microSD Backend (Types 15, 16)

`sunrise_sd.c` — `sunrise_sd_task()`:

```
┌─────────────────────────────────────────────────────┐
│  Core 1 — SD Backend                                │
│  ┌───────────────────────────────────────────────┐  │
│  │  disk_initialize() → SPI init + card detect   │  │
│  │  disk_ioctl(GET_SECTOR_COUNT)                 │  │
│  │  CID register → vendor/product/revision       │  │
│  │  disk_read() / disk_write() polling loop      │  │
│  └───────────────────────────────────────────────┘  │
└────────────────────────┬────────────────────────────┘
                         │ SPI0 @ 31.25 MHz
                  ┌──────▼──────┐
                  │   microSD   │
                  │   Card      │
                  └─────────────┘
```

- Transfers are synchronous — `disk_read()` and `disk_write()` block until complete, which simplifies the code vs. the async USB path
- All SD cards use 512-byte sectors natively; no sector-size conversion is needed
- Device info for IDENTIFY is extracted from the SD card's CID register (OEM ID, Product Name, Product Revision)
- Card initialization happens once at startup; no hot-plug support

### Combined Diagram

```
┌──────────────────────────────────────────────────────────┐
│  MSX Bus                                                 │
│  /SLTSL, /RD, /WR, A0-A15, D0-D7, /WAIT                │
└──────────────┬───────────────────────┬───────────────────┘
               │                       │
        ┌──────▼───────┐        ┌──────▼────────┐
        │  SM0 (PIO0)  │        │  SM1 (PIO0)   │
        │  Read Resp.  │        │  Write Capt.  │
        └──────┬───────┘        └──────┬────────┘
               │                       │
        ┌──────▼───────────────────────▼────────┐
        │            Core 0 (CPU)               │
        │  sunrise_ide_handle_read/write()      │
        │  Sunrise mapper page lookup           │ 
        │  PIO bus + FIFO management            │
        └──────────────────┬────────────────────┘
                           │  Shared volatile flags
                           │  (sunrise_ide_t)
             ┌─────────────┴─────────────┐
             │                           │
     ┌───────▼───────┐          ┌────────▼────────┐
     │   Core 1      │          │    Core 1       │
     │ sunrise_usb_  │    OR    │ sunrise_sd_     │
     │ task()        │          │ task()          │
     │ (Types 10,11) │          │ (Types 15,16)   │
     └───────┬───────┘          └────────┬────────┘
             │                           │
      ┌──────▼──────┐           ┌────────▼────────┐
      │   USB-C     │           │    microSD      │
      │ Pendrive    │           │    Card (SPI)   │
      └─────────────┘           └─────────────────┘
```

## 3. microSD Card Hardware

The microSD card connects to the RP2350 via SPI0:

| GPIO | Signal | SPI Function |
|---|---|---|
| 33 | CS | Chip Select (manual) |
| 34 | SCK | SPI Clock |
| 35 | MOSI | SPI Data Out |
| 36 | MISO | SPI Data In |

- **SPI peripheral**: `spi0`
- **Baud rate**: 31.25 MHz (`125 MHz / 4`)
- **Library**: Carl Kugler's `no-OS-FatFS-SD-SDIO-SPI-RPi-Pico` — provides the FatFS `diskio.h` low-level API (`disk_initialize`, `disk_read`, `disk_write`, `disk_ioctl`)

The hardware configuration is defined in `hw_config.c`, which registers a single `sd_card_t` with the SPI interface parameters. This is the same configuration used by the Explorer firmware.

## 4. SD Card Device Identification

When the SD card is initialized, the firmware reads the card's CID (Card IDentification) register to populate the ATA IDENTIFY DEVICE response with real device information. The CID is a 16-byte register embedded in every SD card containing manufacturer-programmed identification data.

### CID Fields Used

| Field | CID Bits | Size | Purpose |
|---|---|---|---|
| OEM/Application ID | [119:104] | 2 chars | ATA model prefix (vendor) |
| Product Name | [103:64] | 5 chars | ATA model name |
| Product Revision | [63:56] | 4+4 bits | ATA firmware revision ("major.minor") |

### Extraction Code

```c
sd_card_t *sd = sd_get_by_num(0);
char vendor[3] = {0};
char product[6] = {0};
char revision[5] = {0};

ext_str(16, sd->state.CID, 119, 104, sizeof(vendor), vendor);
ext_str(16, sd->state.CID, 103, 64, sizeof(product), product);
uint8_t prv_major = (uint8_t)ext_bits16(sd->state.CID, 63, 60);
uint8_t prv_minor = (uint8_t)ext_bits16(sd->state.CID, 59, 56);
snprintf(revision, sizeof(revision), "%u.%u", prv_major, prv_minor);
```

This data is passed to `sunrise_ide_set_device_info()`, which populates the shared ATA state used by `build_identify_data()`. During Nextor boot, the driver prints the model name from IDENTIFY words 27–46 and the firmware revision from words 23–26, showing the actual microSD card identity.

For USB devices, the equivalent information comes from the SCSI INQUIRY response (vendor ID, product ID, and product revision).

## 5. Inter-Core Communication

Both backends reuse the same set of volatile flags originally defined for the USB path. The flag names retain their `usb_` prefix but serve as generic IDE↔backend signals:

| Flag | Direction | Purpose |
|---|---|---|
| `usb_device_mounted` | Backend → Front-end | Storage device is ready for I/O |
| `usb_read_requested` | Front-end → Backend | ATA READ SECTORS pending |
| `usb_read_lba` | Front-end → Backend | LBA for the pending read |
| `usb_write_requested` | Front-end → Backend | ATA WRITE SECTORS pending (buffer full) |
| `usb_write_lba` | Front-end → Backend | LBA for the pending write |
| `usb_write_buffer[512]` | Front-end → Backend | Sector data to write |
| `usb_read_ready` | Backend → Front-end | Read completed successfully |
| `usb_read_failed` | Backend → Front-end | Read failed |
| `usb_write_ready` | Backend → Front-end | Write completed successfully |
| `usb_write_failed` | Backend → Front-end | Write failed |
| `usb_identify_pending` | Front-end → Backend | IDENTIFY waiting for device mount |

These flags are declared non-static in `sunrise_ide.c` and accessed via `extern` in `sunrise_sd.c`. Flag ownership is strictly unidirectional — one core sets, the other clears.

## 6. Mapper Mode (Types 11, 16)

The mapper variants (`-m1`, `-m2`) add a two-phase bootstrap and an expanded sub-slot architecture:

### Phase 1 — Bootstrap ROM

A minimal 18-byte ROM is served that:
1. Presents itself with the `AB` header so the BIOS executes the INIT routine
2. Reads `I/O port 0xF4`, ORs bit 7 (boot slot), and writes it back
3. Executes `RST 0x00` to restart the MSX

This forces the MSX to reboot with the cartridge slot marked as the boot slot, required for the expanded sub-slot mapper to be recognized by the BIOS.

### Phase 2 — Expanded Sub-Slot Architecture

After restart detection, the firmware reinitializes PIO and sets up:

| Sub-slot | Content | Address Range |
|---|---|---|
| 0 | Nextor ROM (128KB, 8 pages) + IDE registers | `0x4000`–`0x7FFF` |
| 1 | Mapper RAM (1MB, 64 pages) | All four 16KB pages |

- **Sub-slot register** (`0xFFFF`): Read returns bitwise complement; write sets sub-slot configuration
- **Mapper page registers** (I/O ports `0xFC`–`0xFF`): Intercepted by PIO1 state machines, controlling which 16KB page of mapper RAM is visible in each CPU page
- **1MB mapper RAM**: Backed by external PSRAM mapped at the uncached QMI CS1 window (`0x15000000`)
- The ROM cache is disabled (`rom_cache_capacity = 0`) because mapper RAM now lives in external PSRAM instead of the internal SRAM cache pool

### PIO1 Usage in Mapper Mode

| SM | Program | Function |
|----|---|---|
| SM0 | `msx_io_read_responder` | Returns mapper page register values for reads on ports FC–FF |
| SM1 | `msx_io_write_captor` | Captures mapper page register writes on ports FC–FF |

## 7. Optional WiFi Overlay (`-w`)

The `-w` flag augments the four standard Sunrise modes:

| Base Mode | With `-w` |
|---|---|
| `-s1` | microSD Nextor + WiFi |
| `-m1` | microSD Nextor + 1MB mapper + WiFi |
| `-s2` | USB Nextor + WiFi |
| `-m2` | USB Nextor + 1MB mapper + WiFi |

Implementation summary:

- The host tool sets bit `0x20` in the configuration record.
- The firmware keeps the original base mapper type and switches to WiFi-aware Sunrise handlers.
- A dedicated 16KB ESP8266P system ROM is exposed in its own expanded subslot.
- The memio UART interface is mapped at `0x7F05`-`0x7F07` inside that same subslot.

Subslot layout with WiFi enabled:

| Mode Family | Sub-slot 0 | Sub-slot 1 | Sub-slot 2 |
|---|---|---|---|
| `-s1 -w`, `-s2 -w` | ESP8266P ROM + memio UART | Nextor + IDE | unused |
| `-m1 -w`, `-m2 -w` | ESP8266P ROM + memio UART | Nextor + IDE | 1MB PSRAM mapper |

The ESP8266P BIOS is placed in sub-slot 0 so its `INIT` runs before Nextor's during the MSX BIOS expanded-slot scan. This ordering is required for FPGA-based MSX cores and is functionally equivalent on real MSX hardware.

The WiFi implementation is intentionally not enabled for `-c1` and `-c2` in the current firmware.

In Explorer builds the ESP8266P BIOS is stored once as a hidden fixed payload. Sunrise Nextor entries show **Wifi: No** by default on the ROM details screen; changing it to **Yes** makes the firmware expose the same WiFi subslot layout used by `-w`, then run the selected Sunrise Nextor ROM. Mapper variants keep their 1MB PSRAM mapper in subslot 2.

## 8. ATA IDENTIFY DEVICE Response

Both backends produce a 512-byte IDENTIFY DEVICE response. The key fields:

| Word(s) | Field | USB Value | SD Value |
|---|---|---|---|
| 0 | Configuration | `0x0040` (fixed) | `0x0040` (fixed) |
| 1, 3, 6 | CHS geometry | From USB block count | From SD sector count |
| 10–19 | Serial number | `"PICOVERSE00000001"` | `"PICOVERSE00000001"` |
| 23–26 | Firmware revision | USB SCSI product rev | CID Product Revision |
| 27–46 | Model number | USB SCSI vendor + product | CID OEM ID + Product Name |
| 49 | Capabilities | `0x0200` (LBA) | `0x0200` (LBA) |
| 60–61 | Total LBA sectors | USB block count | SD sector count |

The USB backend reads SCSI INQUIRY fields directly from the USB device. The SD backend reads the CID register via `ext_str()` and `ext_bits16()`. Both populate the shared ATA state via `sunrise_ide_set_device_info()`, which writes to the `usb_block_count`, `usb_block_size`, and `inquiry_resp` variables used by `build_identify_data()`.

## 9. Key Differences: USB vs. SD Backend

| Aspect | USB Backend | SD Backend |
|---|---|---|
| **Transfer model** | Asynchronous (TinyUSB callbacks) | Synchronous (blocking `disk_read`/`disk_write`) |
| **Timeout handling** | 3-second watchdog in Core 1 loop | Not needed (SPI is deterministic) |
| **Native sector size** | Variable (512, 4096, etc.) | Always 512 bytes |
| **4K sector support** | Yes — reads native block, extracts 512-byte slice | N/A |
| **Hot-plug** | Yes — `tuh_msc_mount_cb`/`umount_cb` | No — initialized once at startup |
| **Device info source** | SCSI INQUIRY response | CID register |
| **Write with non-512 sectors** | Returns error (would need read-modify-write) | Always 512-byte aligned |
| **Core 1 dependencies** | TinyUSB, `tinyusb_board`, `tinyusb_host` | `no-OS-FatFS-SD-SDIO-SPI-RPi-Pico`, `hw_config.c` |
| **Initialization time** | Variable (USB enumeration + INQUIRY) | Fast (~100ms SPI init) |
| **IDENTIFY before ready** | Defers to BSY + `usb_identify_pending` | Usually ready before first IDENTIFY |

## 10. Firmware Dispatch

The `main()` function in `loadrom.c` reads the mapper type from the configuration record and dispatches accordingly:

```c
switch (base_rom_type) {
    // ... cases 1-9 (standard mappers) ...
    case 10: wifi_enabled ? loadrom_sunrise_wifi(ROM_RECORD_SIZE, true)
                          : loadrom_sunrise(ROM_RECORD_SIZE, true);          break;
    case 11: wifi_enabled ? loadrom_sunrise_mapper_wifi(ROM_RECORD_SIZE, true)
                          : loadrom_sunrise_mapper(ROM_RECORD_SIZE, true);   break;
    // ... cases 12-14 ...
    case 15: wifi_enabled ? loadrom_sunrise_wifi_sd(ROM_RECORD_SIZE, true)
                          : loadrom_sunrise_sd(ROM_RECORD_SIZE, true);       break;
    case 16: wifi_enabled ? loadrom_sunrise_mapper_wifi_sd(ROM_RECORD_SIZE, true)
                          : loadrom_sunrise_mapper_sd(ROM_RECORD_SIZE, true); break;
       case 19: loadrom_sunrise_megaram_sd(ROM_RECORD_SIZE, true);              break;
       case 20: loadrom_sunrise_megaram_usb(ROM_RECORD_SIZE, true);             break;
}
```

The SD functions (`loadrom_sunrise_sd`, `loadrom_sunrise_mapper_sd`) are structurally identical to their USB counterparts but launch `sunrise_sd_task` on Core 1 instead of `sunrise_usb_task`, and call `sunrise_sd_set_ide_ctx()` instead of `sunrise_usb_set_ide_ctx()`.

When WiFi is enabled, the dispatch keeps the same base mapper type and swaps in the WiFi-aware Sunrise handlers instead.

MegaRAM modes do not currently have WiFi variants; their mapper types dispatch directly to the SD or USB MegaRAM handler.

## 11. LoadROM and MultiROM Tool Usage

### LoadROM command-line options

```
loadrom.exe [-h] [-s1] [-m1] [-s2] [-m2] [-c1] [-c2] [-r1] [-r2] [-s3] [-w] [-scc] [-sccplus] [-o <filename>] [romfile]
```

| Option | Long Form | Description |
|---|---|---|
| `-s1` | `--sunrise-sd` | Sunrise IDE with microSD card |
| `-m1` | `--mapper-sd` | Sunrise IDE + 1MB PSRAM mapper with microSD card |
| `-s2` | `--sunrise-usb` | Sunrise IDE with USB pendrive |
| `-m2` | `--mapper-usb` | Sunrise IDE + 1MB PSRAM mapper with USB pendrive |
| `-c1` | `--carnivore2-sd` | Sunrise IDE + 1MB PSRAM mapper + Carnivore2 RAM-mode emulation with microSD card |
| `-c2` | `--carnivore2-usb` | Sunrise IDE + 1MB PSRAM mapper + Carnivore2 RAM-mode emulation with USB pendrive |
| `-r1` | `--megaram-sd` | Sunrise IDE + 1MB PSRAM mapper + 1MB MegaRAM with microSD card |
| `-r2` | `--megaram-usb` | Sunrise IDE + 1MB PSRAM mapper + 1MB MegaRAM with USB pendrive |
| `-s3` | `--sunrise3-sd` | Same as `-s1`, with the Nextor 3.0.0 Beta 2 kernel instead of 2.1.4 (for testing) |
| `-w` | `--wifi` | Add the ESP8266P system ROM + memio UART WiFi surface to `-s1`/`-m1`/`-s2`/`-m2`/`-s3` |

In LoadROM the Sunrise, Carnivore2, and MegaRAM base options are mutually exclusive. The `-w` flag is valid only with `-s1`, `-m1`, `-s2`, `-m2`, or `-s3`.

### MultiROM command-line options

The same `-s1` / `-m1` / `-s2` / `-m2` / `-c1` / `-c2` / `-s3` flags are accepted by `multirom.exe`, and `-a` / `--allnextor` enables all of them at once. In MultiROM they are **not** mutually exclusive — each enabled flag adds an independent SYSTEM entry to the on-cart menu, so a single UF2 can offer several Sunrise / Carnivore2 modes side-by-side. The `-w` WiFi flag is also accepted by `multirom.exe`; it requires at least one of `-s1`/`-m1`/`-s2`/`-m2`/`-s3` and is applied to every selected Sunrise IDE entry. WiFi is intentionally not added to `-c1`/`-c2` Carnivore2 entries. The `-scc` / `-sccplus` flags are accepted by both tools and apply to Konami SCC / Manbow2 ROMs as well as to ROMs uploaded via SROM in the Carnivore2 modes. MegaRAM `-r1`/`-r2` are LoadROM system-image options in the current implementation.

### Examples

```bash
# microSD standalone
loadrom.exe -s1
loadrom.exe -s1 -o nextor_sd.uf2
loadrom.exe -s1 -w -o nextor_sd_wifi.uf2

# microSD + 1MB PSRAM mapper
loadrom.exe -m1
loadrom.exe -m1 -w -o nextor_mapper_sd_wifi.uf2

# USB standalone
loadrom.exe -s2
loadrom.exe -s2 -o nextor_usb.uf2
loadrom.exe -s2 -w -o nextor_usb_wifi.uf2

# USB + 1MB PSRAM mapper
loadrom.exe -m2
loadrom.exe -m2 -w -o nextor_mapper_usb_wifi.uf2

# microSD + 1MB PSRAM mapper + 1MB MegaRAM
loadrom.exe -r1
loadrom.exe -r1 -o nextor_megaram_sd.uf2

# USB + 1MB PSRAM mapper + 1MB MegaRAM
loadrom.exe -r2
loadrom.exe -r2 -o nextor_megaram_usb.uf2
```

### Typical Workflow

1. Run `loadrom.exe` with the desired Nextor option.
2. Review the console output (ROM type, name, size).
3. Hold BOOTSEL on the PicoVerse 2350 and connect USB.
4. Copy the generated UF2 to the `RPI-RP2` drive.
5. For `-s1`/`-m1`/`-r1`: Insert a microSD card with a FAT16 partition up to 4 GB into the PicoVerse 2350 card slot.
6. For `-s2`/`-m2`/`-r2`: Connect a USB flash drive to the USB-C port (via OTG adapter if needed).
7. Insert the cartridge into the MSX and power on.

## 12. Build Configuration

### CMakeLists.txt

The build includes both USB and SD dependencies:

```cmake
add_subdirectory(lib/no-OS-FatFS-SD-SDIO-SPI-RPi-Pico/src build_sd_lib)

add_executable(loadrom
    ${PICO_SDK_PATH}/lib/tinyusb/src/tusb.c
    loadrom.c
    emu2212.c
    sunrise_ide.c
    sunrise_sd.c
    hw_config.c)

target_link_libraries(loadrom
    pico_stdlib
    pico_multicore
    pico_audio_i2s
    hardware_dma
    hardware_pio
    tinyusb_board
    tinyusb_host
    no-OS-FatFS-SD-SDIO-SPI-RPi-Pico)
```

Both backends are compiled into every firmware binary. The runtime dispatch in `main()` selects which backend runs based on the mapper type stored in the configuration record.

The WiFi-enabled Sunrise variants additionally use the host tool to append the ESP8266P ROM after the Sunrise ROM payload in the UF2 image, while the firmware keeps only the UART/memio backend and serves the WiFi ROM from the appended flash payload.

### Tool Makefile

The PC tool Makefile generates `nextor_sunrise.h` and `nextor3.h` (the embedded ROMs as C byte arrays) from:

```
resources/Nextor-2.1.4.SunriseIDE.MasterOnly.ROM       → src/nextor_sunrise.h
resources/Nextor-3.0.0-beta2.SunriseIDE.MasterOnly.ROM → src/nextor3.h
```

`nextor_sunrise.h` is shared by all the Nextor 2.1.4 modes; `nextor3.h` is used only by `-s3`.

## 13. Source File Reference

| File | Purpose |
|---|---|
| `pico/loadrom/sunrise_ide.h` | Sunrise IDE address map, ATA constants, IDE state machine, `sunrise_ide_t` context, public API |
| `pico/loadrom/sunrise_ide.c` | ATA command handling, data register latch, mapper bit reversal, USB host backend (`sunrise_usb_task`), IDENTIFY builder, `sunrise_ide_set_device_info()` |
| `pico/loadrom/sunrise_sd.h` | SD backend API: `sunrise_sd_set_ide_ctx()`, `sunrise_sd_task()` |
| `pico/loadrom/sunrise_sd.c` | SD card initialization, CID extraction, synchronous block I/O backend (`sunrise_sd_task`) |
| `pico/loadrom/hw_config.c` | SPI pin configuration for SD card (CS=33, SCK=34, MOSI=35, MISO=36) |
| `pico/loadrom/tusb_config.h` | TinyUSB host mode configuration for USB MSC |
| `pico/loadrom/loadrom.c` | Firmware main: Sunrise, mapper, MegaRAM, Carnivore2, and WiFi-aware Sunrise handlers |
| `wifi/ESP8266P.rom` | ESP8266P system ROM asset used by the WiFi-enabled Sunrise builds |
| `tool/src/esp8266p_rom.h` | Generated host-tool header created from `wifi/ESP8266P.rom` and appended to the UF2 image |

For the full WiFi-specific register map and usage notes, see `docs/msx-picoverse-2350-wifi.md`.
| `pico/loadrom/loadrom.h` | Pin definitions, SRAM pool, mapper and MegaRAM constants |
| `pico/loadrom/CMakeLists.txt` | Build configuration with both USB and SD dependencies |
| `tool/src/loadrom.c` | PC tool: `-s1`/`-m1`/`-s2`/`-m2`/`-c1`/`-c2`/`-r1`/`-r2`/`-s3` options, UF2 generation |
| `tool/Makefile` | Build scripts, embedded ROM header generation |
| `resources/Nextor-2.1.4.SunriseIDE.MasterOnly.ROM` | 128KB Nextor Sunrise IDE kernel |
| `resources/Nextor-3.0.0-beta2.SunriseIDE.MasterOnly.ROM` | 128KB Nextor 3.0.0 Beta 2 Sunrise IDE kernel (`-s3`) |
| `lib/no-OS-FatFS-SD-SDIO-SPI-RPi-Pico/` | Carl Kugler's FatFS + SPI SD driver library |

All paths are relative to `2350/software/loadrom.pio/`.

## 13. Comparison with PicoVerse 2040

| Feature | PicoVerse 2040 | PicoVerse 2350 |
|---|---|---|
| USB Sunrise IDE | Yes (`-s`) | Yes (`-s2`) |
| USB Sunrise + Mapper | Yes (`-m`, 192KB) | Yes (`-m2`, 1MB) |
| USB Sunrise + Mapper + MegaRAM | No | Yes (`-r2`, 1MB mapper + 1MB MegaRAM) |
| microSD Sunrise IDE | No | Yes (`-s1`) |
| microSD Sunrise + Mapper | No | Yes (`-m1`, 1MB) |
| microSD Sunrise + Mapper + MegaRAM | No | Yes (`-r1`, 1MB mapper + 1MB MegaRAM) |
| Mapper RAM | 192KB (12 pages) | 1MB (64 pages) |
| MegaRAM | No | 1MB (128 x 8KB banks) |
| SD card slot | No | Yes (SPI0, GPIO 33–36) |
| Nextor ROM | Nextor 2.1.4 Sunrise IDE | Nextor 2.1.4 Sunrise IDE |
| ATA front-end | Identical | Identical |
| Device info | USB SCSI INQUIRY | USB SCSI INQUIRY or SD CID |

The ATA front-end code (`sunrise_ide.c`) is shared between both platforms. The 2350 simply adds the SD backend as an alternative to USB.

Author: Cristiano Goncalves  
Last updated: 06/13/2026

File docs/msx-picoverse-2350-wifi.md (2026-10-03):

# MSX PicoVerse 2350 WiFi Support

This document describes the ESP-01 WiFi support currently implemented for the PicoVerse 2350 firmware family.

The PicoVerse 2350 WiFi implementation has two user-facing surfaces: an ESP8266P-compatible system ROM and memio UART bridge on top of the Sunrise IDE Nextor modes, and the integrated Explorer File Hunter browser that uses the ESP-01 module directly from the Pico firmware.

## 1. Overview

WiFi support is enabled from the RP2350 LoadROM tool with the `-w` or `--wifi` flag.

The flag is currently valid only with these four firmware modes:

| LoadROM Option | Storage Backend | Mapper | WiFi Support |
|---|---|---|---|
| `-s1 -w` | microSD | none | yes |
| `-m1 -w` | microSD | 1MB PSRAM mapper | yes |
| `-s2 -w` | USB mass storage | none | yes |
| `-m2 -w` | USB mass storage | 1MB PSRAM mapper | yes |

WiFi support is available in both LoadROM (`loadrom.exe -w`) and MultiROM (`multirom.exe -w`) for Sunrise IDE modes. Explorer also uses the ESP-01 module for File Hunter browsing and exposes WiFi setup through `F4`; this Explorer path is built into the Explorer firmware and does not use a `-w` tool option.

The Sunrise IDE `-w` option is not currently exposed in:

- `-c1` / `-c2` Carnivore2-compatible RAM loader modes

In practical terms, `-w` keeps the normal Nextor boot/storage behavior and adds a second ROM/interface surface for WiFi-aware MSX software.

## 2. What The Feature Adds

When `-w` is enabled, the generated UF2 contains:

- The existing PicoVerse 2350 Sunrise IDE firmware
- The embedded Nextor 2.1.4 Sunrise IDE ROM
- A WiFi flag in the configuration record (`0x20`)
- An embedded 16KB ESP8266P system ROM
- A memory-mapped UART backend that services the ESP ROM protocol through the installed ESP-01 module

The host tool prints this explicitly when building the image:

```text
WiFi Support: Enabled (ESP8266P system ROM + UART support)
```

## 3. User-Facing Build Commands

Typical commands are:

```bash
# Nextor via microSD + WiFi
loadrom.exe -s1 -w -o nextor_sd_wifi.uf2

# Nextor via microSD + 1MB mapper + WiFi
loadrom.exe -m1 -w -o nextor_mapper_sd_wifi.uf2

# Nextor via USB + WiFi
loadrom.exe -s2 -w -o nextor_usb_wifi.uf2

# Nextor via USB + 1MB mapper + WiFi
loadrom.exe -m2 -w -o nextor_mapper_usb_wifi.uf2
```

The `-w` flag is rejected for any other mode:

```text
Error: -w/--wifi is supported only with -s1, -m1, -s2 or -m2.
```

## 4. Hardware Context

The PicoVerse 2350 hardware includes an ESP-01 header. The WiFi implementation assumes:

- A PicoVerse 2350 board revision that routes the ESP-01 UART signals to the RP2350 firmware backend
- An ESP-01 / ESP8266 module installed on the board
- A storage device appropriate for the selected Nextor mode
  - microSD card for `-s1 -w` / `-m1 -w` / `-s3 -w`
  - USB mass storage device for `-s2 -w` / `-m2 -w`

The firmware exposes the ESP link through the MSX-visible memio interface. It does not replace the ESP firmware running on the ESP-01 itself.

## 5. Boot Model

WiFi support is implemented as an overlay on the Sunrise IDE modes.

### Plain Sunrise WiFi Modes

For `-s1 -w` and `-s2 -w`, the firmware uses a two-subslot expanded layout after the bootstrap restart:

| Sub-slot | Function |
|---|---|
| 0 | ESP8266P system ROM and memio UART registers |
| 1 | Nextor Sunrise IDE ROM and IDE register surface |

### Mapper WiFi Modes

For `-m1 -w` and `-m2 -w`, the firmware uses a three-subslot layout:

| Sub-slot | Function |
|---|---|
| 0 | ESP8266P system ROM and memio UART registers |
| 1 | Nextor Sunrise IDE ROM and IDE register surface |
| 2 | 1MB PSRAM-backed MSX memory mapper |

This matters because WiFi support is not just a serial sidecar. It is mapped into the MSX-visible cartridge space in the same expanded-slot model used by the Sunrise mapper implementation.

The ESP8266P BIOS is placed in sub-slot 0 so its `INIT` routine runs before Nextor's during the MSX BIOS expanded-slot scan. This ordering is required for compatibility with FPGA-based MSX cores (e.g. ESEMSX3-derived cores), which are sensitive to the bus / sub-slot state immediately after a sub-slot transition. On real MSX hardware the ordering is functionally equivalent to the previous layout.
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

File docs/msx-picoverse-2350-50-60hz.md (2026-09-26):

# PicoVerse 2350 Explorer — Per-ROM 50/60 Hz (VDP Frequency)

This document describes the per-ROM VDP video frequency (50 Hz / 60 Hz) feature added to
the PicoVerse 2350 **Explorer** firmware in **v2.40**, including the user interface, the
on‑disk persistence format, the MSX ⇄ Pico communication, and — most importantly — how the
selected frequency is actually applied to the launched ROM.

- Sub-project: `2350/software/explorer.pio`
- Introduced in: PicoVerse 2350 Explorer **v2.40**

---
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

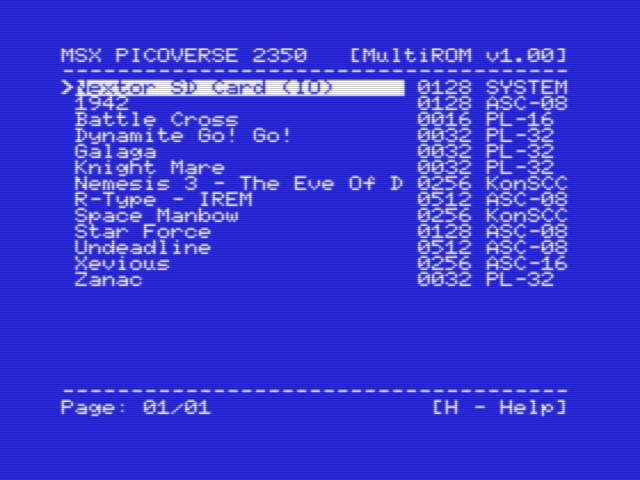
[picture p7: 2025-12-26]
images/multirom_2350_menu.png

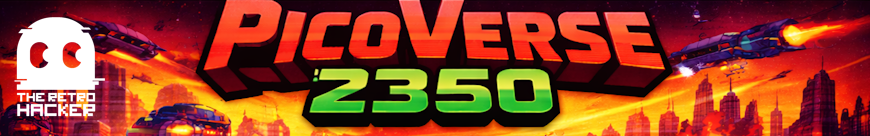
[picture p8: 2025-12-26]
labels/PicoVerse_2350_Label_2.png

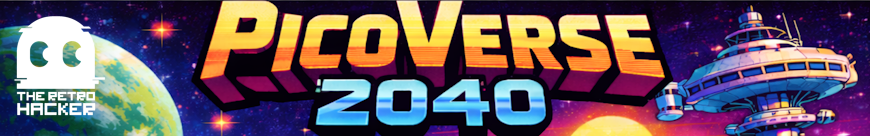
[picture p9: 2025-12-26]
labels/PicoVerse_2040_Label_2.png

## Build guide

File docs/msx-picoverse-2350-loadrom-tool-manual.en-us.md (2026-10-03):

# MSX PicoVerse 2350 LoadROM Tool Manual (EN-US)

The PicoVerse 2350 LoadROM tool creates a UF2 image that flashes the PicoVerse 2350 with a single ROM payload and the LoadROM firmware or with dedicated standalone sound-cartridge firmware variations.

`loadrom.exe` bundles the Pico firmware blob, a configuration record (game name, mapper code, ROM size, and flash offset), and one MSX ROM file into an RP2350-compatible UF2 image. Copy the generated UF2 to the board in BOOTSEL mode and the MSX will boot straight into the embedded ROM.

For RP2350, the current LoadROM package is:

- `2350/software/loadrom.pio`.

> **Important:** SCC/SCC+ emulation options (`-scc`, `-sccplus`), the secondary AY-3-8910 dual PSG option (`-d`), and the MSX-MUSIC/YM2413 option (`-f` or `-fmpac`) are supported by the current RP2350 LoadROM package (`2350/software/loadrom.pio`). Exactly one on-cartridge audio mode can be active per UF2 image.

> **OPL4 / MoonSound:** The `-4` / `--opl4` option builds a dedicated, standalone OPL4 / YMF278B / MoonSound cartridge instead of a ROM loader. It is mutually exclusive with every other mode and does not take a ROM file. See [Standalone OPL4 / MoonSound cartridge](#standalone-opl4--moonsound-cartridge).

> **MSX-AUDIO / Y8950:** The `-a` / `--msx-audio` option builds a dedicated, standalone MSX-AUDIO (Yamaha Y8950) cartridge instead of a ROM loader. It is mutually exclusive with every other mode and does not take a ROM file. See [Standalone MSX-AUDIO / Y8950 cartridge](#standalone-msx-audio--y8950-cartridge).

---

## Overview

1. **Input**: one `.ROM` file (case-insensitive extension).
2. **Processing**: the tool normalizes the ROM name, detects or forces the mapper, and streams firmware + config + ROM into UF2 blocks.
3. **Output**: a UF2 file (default `loadrom.uf2`) ready for the RP2350 bootloader.

Key characteristics:

- Windows console application.
- Supports ROM sizes from 8 KB up to 16 MB (subject to flash capacity).
- Mapper auto-detection plus optional filename tags to force the mapper.
- Embedded SHA-1 database derived from openMSX `softwaredb.xml` for improved mapper identification.
- Built-in Sunrise IDE Nextor ROM for standalone Nextor boot or Nextor + 1MB PSRAM mapper, using either the on-board microSD card (`-s1`/`-m1`) or a USB flash drive (`-s2`/`-m2`).
- Built-in Nextor + 1MB mapper + 1MB MegaRAM system images, using either microSD (`-r1`) or USB mass storage (`-r2`).
- Optional ESP-01 WiFi support for those Sunrise IDE modes via `-w`, adding an embedded ESP8266P system ROM and memio UART backend.
- ROM loading into the 1MB PSRAM mapper through Carnivore2-compatible RAM emulation for `SROM.COM /D15`, using either microSD (`-c1`) or USB mass storage (`-c2`) as the Nextor backend.
- Standalone sound-cartridge firmware builds that embed no game ROM: OPL4 / YMF278B / MoonSound (`-4`) with the 2 MB YRW801-M wave ROM, and MSX-AUDIO / Y8950 (`-a`) with the 48 KB MSX-Audio BIOS.
- UF2 uses RP2350 family ID (`0xE48BFF59`).

---

## Command-line usage

```
loadrom.exe [options] [romfile]
```

### Options

- `-h`, `--help` : Print usage information and exit.
- `-s1`, `--sunrise-sd` : Build a UF2 with the embedded Sunrise IDE Nextor ROM using the on-board microSD card slot for storage. No external ROM file is needed.
- `-m1`, `--mapper-sd` : Same as `-s1` plus a 1MB memory mapper (64 × 16KB pages) backed by external PSRAM on GPIO47 / QMI CS1 in an expanded sub-slot architecture. No external ROM file is needed.
- `-s2`, `--sunrise-usb` : Build a UF2 with the embedded Sunrise IDE Nextor ROM using the cartridge's USB-C port for storage (USB mass storage). No external ROM file is needed.
- `-m2`, `--mapper-usb` : Same as `-s2` plus a 1MB memory mapper (64 × 16KB pages) backed by external PSRAM on GPIO47 / QMI CS1 in an expanded sub-slot architecture. No external ROM file is needed.
- `-c1`, `--carnivore2-sd` : Build a UF2 with Sunrise IDE Nextor on microSD plus the 1MB PSRAM mapper and Carnivore2 RAM-mode emulation for `SROM.COM /D15`. In this mode, `SROM.COM` can upload a ROM image into the PSRAM-backed mapper and launch it from RAM without reflashing the cartridge.
- `-c2`, `--carnivore2-usb` : Same as `-c1`, but uses USB mass storage on the cartridge's USB-C port as the Nextor backend.
- `-r1`, `--megaram-sd` : Build a UF2 with Sunrise IDE Nextor on microSD, a 1MB MSX memory mapper, and a separate 1MB PSRAM-backed MegaRAM subslot using 128 × 8KB banks. No external ROM file is needed.
- `-r2`, `--megaram-usb` : Same as `-r1`, but uses USB mass storage on the cartridge's USB-C port as the Nextor backend.
- `-s3`, `--sunrise3-sd` : Same as `-s1`, but embeds Konamiman's Nextor 3.0.0 Beta 2 Sunrise IDE MasterOnly kernel (from the [SunriseIDE Nextor driver](https://github.com/Konamiman/SunriseIDE-Nextor-driver/releases/tag/v0.1.8-blueMSX-v0.1.5-Nextor-3.0-beta.2) release) instead of Nextor 2.1.4, for testing the upcoming Nextor 3. microSD only for now. It is a beta kernel, so keep backups of the microSD card.
- `-w`, `--wifi` : Enable ESP-01 WiFi support for `-s1`, `-m1`, `-s2`, `-m2`, or `-s3`. This adds the ESP8266P system ROM plus a memory-mapped UART backend expected by the WiFi ROM/software stack.
- `-scc`, `--scc` : Enable SCC (standard) sound emulation. For embedded ROM builds, this applies to Konami SCC or Manbow2 mapper ROMs. With `-c1` or `-c2`, it enables SCC playback for Konami SCC ROMs uploaded later through `SROM.COM /D15`.
- `-sccplus`, `--sccplus` : Enable SCC+ (enhanced) sound emulation. For embedded ROM builds, this applies to Konami SCC or Manbow2 mapper ROMs. With `-c1` or `-c2`, it enables SCC+ playback for compatible ROMs uploaded later through `SROM.COM /D15`.
- `-d`, `--dual-psg` : Enable secondary AY-3-8910 (PSG) emulation on I/O ports `0x10` (register select) and `0x11` (data). The Pico captures `OUT (0x10/0x11),A` writes via PIO1 and streams a mixed signal to the I2S DAC alongside the host MSX's PSG. Only valid with external ROM files whose mapper is not Konami SCC or Manbow2 (those mappers carry an on-cartridge SCC chip and reserve the second audio slot for SCC emulation).
- `-f`, `-fmpac` : Enable MSX-MUSIC / YM2413 emulation on I/O ports `0x7C` (register select) and `0x7D` (data). The Pico captures OPLL writes via PIO1 and streams the generated FM audio to the I2S DAC. The UF2 also embeds the FM-PAC BIOS and exposes it in an expanded FM-PAC subslot so ROMs that use MSX-MUSIC BIOS calls can find it. Only valid with non-SYSTEM external ROM files.
- `-4`, `--opl4` : Build a dedicated, standalone OPL4 / YMF278B / MoonSound cartridge. This is **not** a ROM loader: the UF2 contains only the OPL4 firmware and the 2 MB YRW801-M wave ROM, turning the cartridge into a MoonSound-compatible sound device (2 MB wave ROM + 2 MB PCM sample RAM) on the standard MoonSound I/O ports. It does not take a ROM file and is mutually exclusive with every other option.
- `--22khz` : With `-4` / `--opl4`, build an OPL4 image that renders at 22050 Hz instead of 44100 Hz. This roughly halves the synthesis cost so very dense songs play without dropouts, at the cost of a duller high end.
- `-a`, `--msx-audio` : Build a dedicated, standalone MSX-AUDIO / Yamaha Y8950 cartridge. This is **not** a ROM loader: the UF2 contains only the MSX-AUDIO firmware and the 48 KB MSX-Audio BIOS, turning the cartridge into an MSX-AUDIO card (OPL1 FM + ADPCM, 256 KB ADPCM sample RAM) on ports `0xC0`/`0xC1`. It does not take a ROM file and is mutually exclusive with every other option.
- `--4mhz` : With `-a` / `--msx-audio`, clock the emulated Y8950 at 4 MHz instead of the standard 3.579545 MHz, raising the output rate from 49716 Hz to 55555 Hz.
- `-o <filename>`, `--output <filename>` : Override the UF2 output name (default `loadrom.uf2`).
- Positional argument: the ROM file to embed. Required for normal ROM loading; not accepted with `-s1`/`-m1`/`-s2`/`-m2`/`-c1`/`-c2`/`-r1`/`-r2`/`-s3`.

`-s1`, `-m1`, `-s2`, `-m2`, `-c1`, `-c2`, `-r1`, `-r2`, and `-s3` are mutually exclusive. `-w` is valid only with `-s1`, `-m1`, `-s2`, `-m2`, or `-s3`. The audio options `-scc`, `-sccplus`, `-d`, and `-f`/`-fmpac` are mutually exclusive — only one on-cartridge audio engine can be active per UF2 image. `-d` is additionally rejected for Konami SCC and Manbow2 ROMs, while `-d` and `-f`/`-fmpac` are rejected for the embedded Sunrise/Carnivore2/MegaRAM system modes. `-f`/`-fmpac` is also rejected for Konami SCC and Manbow2 mapper ROMs. If conflicting options are provided, the tool exits with an error.

`-4`/`--opl4` is fully standalone: it cannot be combined with any other option (no Sunrise/Carnivore2 mode, no audio flag, no `-w`, and no ROM file). If `-4` is mixed with any of those, the tool exits with an error. `--22khz` is only accepted together with `-4`.

`-a`/`--msx-audio` is fully standalone in the same way, and is also mutually exclusive with `-4`/`--opl4`. `--4mhz` is only accepted together with `-a`.

For the firmware architecture behind `-d`, see the [PicoVerse 2350 Dual PSG implementation guide](./msx-picoverse-2350-dualpsg.md).

For the firmware architecture behind `-r1` / `-r2`, see the [PicoVerse 2350 MegaRAM implementation guide](./msx-picoverse-2350-megaram.md).

When `-f` or `-fmpac` is selected, LoadROM keeps the selected game mapper active and adds the FM-PAC BIOS/register area in the cartridge's expanded slot layout. The Pico responds to both direct YM2413 I/O writes and FM-PAC memory-mapped register writes at `0x7FF4`/`0x7FF5`.

For the firmware architecture behind `-f` / `-fmpac`, see the [PicoVerse 2350 MSX-MUSIC / FM-PAC implementation guide](./msx-picoverse-2350-fmpac.md).

### Standalone OPL4 / MoonSound cartridge

The `-4` / `--opl4` option produces a firmware-only UF2 that turns the PicoVerse 2350 into a dedicated **OPL4 (Yamaha YMF278B) / MoonSound** sound cartridge. Unlike every other LoadROM mode, it does not embed an MSX ROM and does not load any game — the cartridge is purely a MoonSound-compatible sound device.

What the cartridge provides:

- Full **YMF278B**: OPL3 FM (18 channels) plus the 24-voice PCM wavetable engine.
- The **2 MB YRW801-M** wave ROM (embedded in the UF2) and **2 MB of PCM sample RAM** in external PSRAM, presented as the standard 4 MB OPL4 PCM address space (`0x000000`-`0x1FFFFF` wave ROM, `0x200000`-`0x3FFFFF` sample RAM).
- The standard MoonSound host I/O ports: `0x7E`/`0x7F` (wavetable) and `0xC4`–`0xC7` (FM).
- 16-bit stereo audio at 44.1 kHz through the on-cartridge I2S DAC.
- FM timer interrupts delivered on the MSX `/INT` line (GPIO40, open-drain) so MoonBlaster / MBWAVE style replayers keep the correct song tempo.

Implementation notes:

- Synthesis uses the BSD-3 licensed [`ymfm`](https://github.com/aaronsgiles/ymfm) YMF278B core. Core 1 runs the synthesis loop into the I2S producer pool while Core 0 owns the MSX bus (PIO port decode, `/WAIT`-gated reads, `/BUSDIR` drive, and register write capture).
- The firmware is linked `copy_to_ram` and the RP2350 is overclocked to **300 MHz**, with the QMI flash/PSRAM dividers raised in step so the memory devices keep their tuned timing.
- Sample RAM is written through the wavetable memory-access registers (`0x02`-`0x06`), so sample uploaders such as SETOPL4 work unchanged.
- `--22khz` selects a second build of the same firmware that renders at 22050 Hz for extreme-polyphony songs; every FM channel and wave voice is still emulated at full polyphony, with pitch, tempo and envelope timing unchanged.

Because `-4` is standalone, it cannot be combined with any Sunrise/Carnivore2 mode, any other audio flag (`-scc`, `-sccplus`, `-d`, `-f`/`-fmpac`), `-a`/`--msx-audio`, `-w`, or a ROM file. The only other accepted options are `-o` to rename the output and `--22khz`.

Usage:

```
loadrom.exe -4                          # writes loadrom.uf2
loadrom.exe -4 -o moonsound.uf2         # custom output name
loadrom.exe -4 --22khz -o moonsound-22k.uf2
```

Flash the resulting UF2 in BOOTSEL mode, then use any MoonSound software on the MSX — for example MoonTest (detection and RAM test), SETOPL4 (sample upload/playback), and MoonBlaster / MBWAVE (music playback). No microSD, USB drive, or ESP-01 is required for this mode.

For the full firmware architecture, see the [PicoVerse 2350 OPL4 / MoonSound implementation guide](./msx-picoverse-2350-opl4.md).

### Standalone MSX-AUDIO / Y8950 cartridge

The `-a` / `--msx-audio` option produces a firmware-only UF2 that turns the PicoVerse 2350 into a dedicated **MSX-AUDIO** cartridge built around an emulated **Yamaha Y8950**. Like `-4`, it does not embed an MSX ROM and does not load any game. Unlike `-4`, it is **not** a pure I/O device: a real MSX-AUDIO card also exposes a memory-mapped BIOS plus work RAM, so the cartridge answers both memory and I/O cycles.

What the cartridge provides:

- An emulated **Yamaha Y8950**: OPL1 FM (9 channels) plus the ADPCM-B / delta-T sample engine.
- **256 KB of ADPCM sample RAM** in external PSRAM.
- The **MSX-Audio BIOS v1.3** (NMS-1205, 48 KB) embedded in the UF2 and exposed in the cartridge slot.
- Host ports `0xC0` (register select on write, status on read) and `0xC1` (data).
- 16-bit audio at **49716 Hz**, the Y8950 native rate (no resampling), at unity gain through the I2S DAC.
- Y8950 FM timer interrupts on the MSX `/INT` line (GPIO40, open-drain) and `/BUSDIR` driven during port reads.

The slot memory map is shown below. The MSX-Audio BIOS is mirrored three times in the 64 KB slot, and the base work RAM is mirrored once. The expanded work RAM is mirrored once, and the unmapped range reads as `0xFF`:

| Z80 range | Contents |
| --- | --- |
| `0x0000`-`0x2FFF` | MSX-Audio BIOS |
| `0x3000`-`0x3FFF` | Base work RAM (4 KB) |
| `0x4000`-`0x6FFF` | MSX-Audio BIOS (`AB` header at `0x4000`) |
| `0x7000`-`0x7FFF` | Base work RAM mirror |
| `0x8000`-`0xAFFF` | MSX-Audio BIOS |
| `0xB000`-`0xBFFF` | Expanded work RAM (4 KB) |
| `0xC000`-`0xEFFF` | Unmapped — reads `0xFF` |
| `0xF000`-`0xFFFF` | Expanded work RAM mirror |

Implementation notes:

- Synthesis uses the BSD-3 licensed [`ymfm`](https://github.com/aaronsgiles/ymfm) `y8950` core, separate from the OPL4 firmware's copy.
- The design is **single-owner on Core 0**: one loop drains memory writes, drains I/O writes, services one read, generates one audio sample into a lock-free ring, and migrates one ROM chunk to SRAM. Core 1 only feeds the I2S DAC from the ring, so status and ADPCM sample-RAM reads are always exact.
- The UF2 layout is `[msxaudio firmware][16-byte "PVAU" config header][48 KB MSX-Audio BIOS]`. Byte 4 of the header carries the flags, with bit 0 = 4 MHz Y8950 clock.
- `--4mhz` raises the emulated Y8950 clock to 4 MHz; because every Y8950 rate derives from the sample clock, this is implemented by raising the output rate to 55555 Hz.
- The cartridge is not an expanded slot, so `0xFFFF` behaves as ordinary work RAM, which is how the MSX BIOS concludes the slot is not expanded.

Because `-a` is standalone, it cannot be combined with `-4`/`--opl4`, any Sunrise/Carnivore2/MegaRAM mode, any other audio flag (`-scc`, `-sccplus`, `-d`, `-f`/`-fmpac`), `-w`, or a ROM file. The only other accepted options are `-o` to rename the output and `--4mhz`.

Usage:

```
loadrom.exe -a                          # writes loadrom.uf2
loadrom.exe -a -o msxaudio.uf2          # custom output name
loadrom.exe -a --4mhz -o msxaudio4.uf2  # 4 MHz Y8950 clock
```

Flash the resulting UF2 in BOOTSEL mode, then use any MSX-AUDIO software — the BIOS itself, MSX-AUDIO games, ADPCM sample players, and FM/ADPCM replayers. No microSD, USB drive, or ESP-01 is required for this mode.

### Mapper forcing via filename tags

Append a dot-separated mapper tag before the `.ROM` extension to override detection. Tags are case-insensitive.

Supported tags:
`PLA-16`, `PLA-32`, `KonSCC`, `PLN-48`, `PLN-64`, `ASC-08`, `ASC-16`, `ASC-16X`, `ASC16X-FR`, `Konami`, `NEO-8`, `NEO-16`, `MANBW2`.

Additional aliases are accepted for backward compatibility: `PL-16`, `PL-32`, `PL-48`, `PL-64`, `PLN-32`, `PLANAR`, `LINEAR`, `LINEAR0`, `PLANAR48`, `PLANAR64`, `ASC16X`, `ASC-16X-FR`, `MANBOW2`, `MBW-2`.

Example:

```
Penguin Adventure.PL-32.ROM
Space Manbow.KonSCC.rom
Go Figure.ASC16X-FR.rom
```

Tags are case-insensitive. If no valid tag is present, the tool first computes the ROM's SHA-1 hash and looks it up in an embedded database derived from the openMSX `softwaredb.xml`. When a match is found the database mapper type is used directly. Otherwise the tool falls back to heuristic detection.

`SYSTEM` is ignored and cannot be forced.

### ASCII16-X with FlashROM (`ASC16X-FR`)

ASCII16-X cartridges carry a real FlashROM chip, and the mapper specification lets software erase sectors and program bytes so a game can store save games, high scores or user created levels inside the cartridge itself.

Auto-detection is deliberately unchanged: a ROM recognised as ASCII16-X is always built as the read-only variant, where flash command sequences are ignored. FlashROM emulation is opt-in through the `ASC16X-FR` filename tag:

```
loadrom.exe "Go Figure.ASC16X-FR.rom" -o gofigure.uf2
```

This is the same tag the Explorer tool uses, so a ROM tagged for one tool behaves the same way in the other.

With the tag, the cartridge implements the command set the specification names as the guaranteed minimum — autoselect, CFI query, chip erase, sector erase and byte program — plus the software reset. Sector geometry follows the documented bottom-boot layout: eight 8 KB sectors followed by 64 KB sectors.

The flash contents are mirrored to a file named after the ROM in the root of the microSD card:

```
/<ROM name>.FLA
```

The file has no header: it is a byte exact image of the cartridge flash, so it can be copied off the card and inspected, or used as a ROM image. It is matched to the running cartridge by name and size.

Notes:
- The image is created in full the first time the cartridge runs with a card that has no matching `.FLA`, and restored at start-up on later runs. Both happen before the MSX is released, so expect a short pause on a large cartridge.
- Without a usable microSD card the flash is still emulated, but its contents are lost at power off.
- The emulated device is sized to the next power of two at or above the ROM size, up to 8 MB.
- Combining the tag with `-d` (second PSG) keeps the flash emulation working but makes it volatile, because the PSG engine owns the core that writes the card. The tool warns when this happens.

---

## Typical workflow

1. Place `loadrom.exe` and your ROM file in a working folder.
2. Open a Command Prompt or PowerShell window in that folder.
3. Run the tool:
   ```
   loadrom.exe "Space Manbow.rom" -o space_manbow.uf2
   ```
   Sunrise IDE standalone (Nextor from microSD card):
   ```
   loadrom.exe -s1
   loadrom.exe -s1 -o nextor_sd.uf2
   ```
   Sunrise IDE standalone with WiFi (microSD):
   ```
   loadrom.exe -s1 -w
   loadrom.exe -s1 -w -o nextor_sd_wifi.uf2
   ```
   Nextor 3.0.0 Beta 2 for testing (microSD):
   ```
   loadrom.exe -s3
   loadrom.exe -s3 -o nextor3_sd.uf2
   ```
   Sunrise IDE + 1MB PSRAM mapper (microSD):
   ```
   loadrom.exe -m1
   loadrom.exe -m1 -o nextor_mapper_sd.uf2
   ```
   Sunrise IDE + 1MB PSRAM mapper with WiFi (microSD):
   ```
   loadrom.exe -m1 -w
   loadrom.exe -m1 -w -o nextor_mapper_sd_wifi.uf2
   ```
   Sunrise IDE standalone (Nextor from USB flash drive):
   ```
   loadrom.exe -s2
   loadrom.exe -s2 -o nextor_usb.uf2
   ```
   Sunrise IDE standalone with WiFi (USB):
   ```
   loadrom.exe -s2 -w
   loadrom.exe -s2 -w -o nextor_usb_wifi.uf2
   ```
   Sunrise IDE + 1MB PSRAM mapper (USB):
   ```
   loadrom.exe -m2
   loadrom.exe -m2 -o nextor_mapper_usb.uf2
   ```
   Sunrise IDE + 1MB PSRAM mapper with WiFi (USB):
   ```
   loadrom.exe -m2 -w
   loadrom.exe -m2 -w -o nextor_mapper_usb_wifi.uf2
   ```
   Carnivore2 RAM-mode loader for `SROM.COM /D15` (microSD):
   ```
   loadrom.exe -c1
   loadrom.exe -c1 -o srom_c2_sd.uf2
   ```
   Carnivore2 RAM-mode loader for `SROM.COM /D15` (USB):
   ```
   loadrom.exe -c2
   loadrom.exe -c2 -o srom_c2_usb.uf2
   ```
  Sunrise IDE + 1MB PSRAM mapper + 1MB MegaRAM (microSD):
  ```
  loadrom.exe -r1
  loadrom.exe -r1 -o nextor_megaram_sd.uf2
  ```
  Sunrise IDE + 1MB PSRAM mapper + 1MB MegaRAM (USB):
  ```
  loadrom.exe -r2
  loadrom.exe -r2 -o nextor_megaram_usb.uf2
  ```
   Carnivore2 RAM-mode loader with SCC audio for SROM-loaded Konami SCC ROMs:
   ```
   loadrom.exe -c1 -scc -o srom_c2_sd_scc.uf2
   loadrom.exe -c2 -scc -o srom_c2_usb_scc.uf2
   ```
   SCC/SCC+ examples:
   ```
   loadrom.exe -scc "Space Manbow.rom"
   loadrom.exe -sccplus "Snatcher.KonSCC.rom"
   ```
   Dual PSG example (secondary AY-3-8910 on ports `0x10`/`0x11`):
   ```
   loadrom.exe -d "Penguin Adventure - 2 x PSG - Darky.rom"
   ```
   MSX-MUSIC example (YM2413 on ports `0x7C`/`0x7D`):
   ```
   loadrom.exe -f "Game with MSX-MUSIC.rom"
   loadrom.exe -fmpac "Game with FM music.rom"
   ```
   OPL4 / MoonSound standalone cartridge (no ROM file):
   ```
   loadrom.exe -4
   loadrom.exe -4 -o moonsound.uf2
   loadrom.exe -4 --22khz -o moonsound-22k.uf2
   ```
   MSX-AUDIO / Y8950 standalone cartridge (no ROM file):
   ```
   loadrom.exe -a
   loadrom.exe -a --4mhz -o msxaudio4.uf2
   ```
4. Review the console output (name, size, mapper, and flash offset).
5. Hold BOOTSEL while connecting the PicoVerse 2350 to USB.
6. Copy the generated UF2 to the `RPI-RP2` drive.
7. Insert the cartridge into the MSX and power on.
8. For `-s1`/`-m1`/`-r1` modes, insert a FAT-formatted microSD card into the cartridge's microSD slot before powering the MSX.
9. For `-s2`/`-m2`/`-r2` modes, connect a USB flash drive (via OTG adapter if needed) to the cartridge's USB-C port before powering the MSX.
10. For `-w` builds, install the ESP-01 module on the PicoVerse 2350 before power-up. The WiFi system ROM and memio UART interface are then available to compatible MSX software.
11. For `-c1`/`-c2` modes, boot Nextor first and then use `SROM.COM /D15` to upload the ROM into the PicoVerse PSRAM mapper. The cartridge is presented as a Carnivore2-compatible RAM target so the uploaded ROM can be launched directly from RAM.
12. For `-r1`/`-r2` modes, boot Nextor first and use a MegaRAM-aware loader or workflow that enables writes with `IN (0x8E)` or `IN (0x8F)`, loads data into the MegaRAM banks, disables writes with `OUT (0x8E)` or `OUT (0x8F)`, and launches software from the MegaRAM subslot.

---

## Output layout details

The UF2 image contains:

1. **Firmware blob** – embedded `loadrom` firmware.
2. **Configuration record** (59 bytes):
   - 50 bytes: ROM name (ASCII, padded/truncated).
   - 1 byte : mapper ID plus optional audio/WiFi flags. Normal ROM mapper IDs use the low nibble; embedded system modes use base IDs 10, 11, and 15-20 after the firmware masks off option flags:
     - Bit 7 (`0x80`) = SCC emulation enabled.
     - Bit 6 (`0x40`) = SCC+ emulation enabled.
     - Bit 5 (`0x20`) = WiFi support enabled for Sunrise IDE modes, or MSX-MUSIC/YM2413 enabled for non-SYSTEM ROMs.
     - Bit 4 (`0x10`) = Dual PSG emulation enabled (secondary AY-3-8910 on ports `0x10`/`0x11`).
   - 4 bytes: ROM size (little-endian).
   - 4 bytes: ROM flash offset (little-endian).
3. **ROM payload** – raw ROM data appended after the config record.

The UF2 writer sets `UF2_FLAG_FAMILYID_PRESENT` and uses the RP2350 family ID (`0xE48BFF59`) so the bootloader accepts the image.

---

## Troubleshooting

| Symptom | Possible cause | Resolution |
| --- | --- | --- |
| "Invalid ROM size" | ROM < 8 KB or > 16 MB | Use a valid ROM size. |
| "Failed to detect the ROM type" | Mapper heuristics failed | Add a mapper tag (e.g., `.Konami.ROM`). |
| "Sunrise options are mutually exclusive" | More than one of `-s1`/`-m1`/`-s2`/`-m2`/`-c1`/`-c2`/`-r1`/`-r2`/`-s3` passed | Use only one firmware mode at a time. The `-m` variants add mapper RAM; the `-c` variants add Carnivore2 RAM-mode loading; the `-r` variants add a separate MegaRAM subslot; `-s3` swaps in the Nextor 3 beta kernel. |
| "Sunrise options do not accept an external ROM file" | ROM file passed with a Sunrise/Carnivore2/MegaRAM option | Remove the ROM file argument when using `-s1`/`-m1`/`-s2`/`-m2`/`-c1`/`-c2`/`-r1`/`-r2`/`-s3`. |
| "Error: -w/--wifi is supported only with -s1, -m1, -s2 or -m2" | `-w` was used without a supported Sunrise mode | Pair `-w` only with `-s1`, `-m1`, `-s2`, or `-m2`. |
| USB pendrive not detected with `-s2`/`-m2`/`-r2` | VBUS not connected or no OTG adapter | Ensure the USB-C port has VBUS power (use an OTG adapter that supplies VBUS). |
| microSD card not detected with `-s1`/`-m1`/`-r1` | Card not inserted or not FAT-formatted | Insert a FAT16/FAT32-formatted microSD card before powering on. |
| WiFi software does not detect the adapter with `-w` | Missing ESP-01 module, incompatible ESP firmware, or wrong WiFi-capable UF2 | Reflash a `-w` build, verify the ESP-01 is installed, and use software targeting the ESP8266P memio interface. |
| `SROM.COM /D15` does not list the cartridge with `-c1`/`-c2` | Wrong firmware mode or outdated build | Reflash with the correct `-c1` or `-c2` UF2 and use a build that includes Carnivore2 RAM-mode emulation. |
| `SROM.COM /D15` upload succeeds but the launched ROM fails | ROM/runtime compatibility issue in the emulation path | Try the latest firmware build and retest; this mode depends on Carnivore2-compatible bank/window presentation from PSRAM. |
| "Disk driver not found. System halted." with `-m1`/`-m2` | Firmware issue | Rebuild with latest firmware; check that the PIO bus init guard is present. |
| "Warning: -scc flag ignored" | ROM is not Konami SCC or Manbow2 mapper, or the selected Nextor mode is not `-c1`/`-c2` | Use a Konami SCC or Manbow2 ROM, or pair `-scc` with `-c1`/`-c2` for SROM-loaded Konami SCC titles. |
| "Warning: -sccplus flag ignored" | ROM is not Konami SCC or Manbow2 mapper, or the selected Nextor mode is not `-c1`/`-c2` | Use a compatible ROM, or pair `-sccplus` with `-c1`/`-c2` for SROM-loaded SCC+ titles. |
| "Error: -scc and -sccplus are mutually exclusive" | Both options were passed together | Use only one of the two options. |
| `-4`/`--opl4` rejected or errors out | `-4` was combined with another mode, an audio flag, `-a`, `-w`, or a ROM file | Use `-4` (optionally with `-o` or `--22khz`) on its own; it is a standalone MoonSound build and accepts no other options or ROM file. |
| MoonSound software does not detect the cartridge with `-4` | Wrong UF2 or board without the OPL4 audio/`/INT` wiring | Reflash a `-4` build and use a PicoVerse 2350 with the I2S DAC and `/INT` (GPIO40) connected. |
| Broken/harsh audio on extreme-polyphony MoonSound songs with `-4` | Synthesis throughput shortfall (most FM channels plus most PCM voices at once) | Rebuild with `loadrom.exe -4 --22khz` to render at 22050 Hz, which roughly halves the synthesis cost. |
| `-a`/`--msx-audio` rejected or errors out | `-a` was combined with another mode, an audio flag, `-4`, `-w`, or a ROM file | Use `-a` (optionally with `-o` or `--4mhz`) on its own; it is a standalone MSX-AUDIO build and accepts no other options or ROM file. |
| "Option --4mhz requires -a/--msx-audio" | `--4mhz` used without `-a` | Add `-a` / `--msx-audio`, or drop `--4mhz`. |
| MSX-AUDIO software does not detect the cartridge with `-a` | Wrong UF2 or board without the audio/`/INT` wiring | Reflash an `-a` build and use a PicoVerse 2350 with the I2S DAC and `/INT` (GPIO40) connected. |
| MSX-AUDIO music plays at the wrong tempo or hangs with `-a` | Replayer paced by the Y8950 FM timer interrupt | Ensure the `/INT` line (GPIO40) is connected on the board; the timer IRQ is what paces those replayers. |
| UF2 not recognized | Not in BOOTSEL, or wrong file | Enter BOOTSEL and copy the UF2 again. |
| Name truncated in menu | Filename too long | Shorten the filename. |

---

## Known limitations

- Only one ROM per UF2 (use the MultiROM or Explorer tools for multiple titles).
- The `-s1`, `-m1`, and `-r1` options require a FAT-formatted microSD card in the cartridge's microSD slot.
- The `-s2`, `-m2`, and `-r2` options require a USB flash drive connected to the cartridge's USB-C port (via OTG adapter) for disk access.
- The `-w` option is available only with `-s1`, `-m1`, `-s2`, or `-m2`.
- `-w` requires an ESP-01 module and compatible ESP-side firmware; the PicoVerse firmware provides the ROM mapping and serial transport, not the ESP application layer itself.
- The `-m1` and `-m2` options provide 1MB mapper RAM (64 × 16KB pages) backed by external PSRAM on GPIO47 / QMI CS1.
- The `-r1` and `-r2` options provide that same 1MB mapper RAM plus a separate 1MB MegaRAM surface with 128 x 8KB banks, four visible windows in `0x4000`-`0xBFFF`, Cartucho II-compatible bank latches selected by address bits A14:A13, `IN (0x8E/0x8F)` write enable, and `OUT (0x8E/0x8F)` write disable.
- The `-c1` and `-c2` options reuse that same 1MB PSRAM-backed mapper RAM and expose it through Carnivore2-compatible RAM-mode behavior intended for `SROM.COM /D15`.
- The `-w` Sunrise IDE WiFi system-ROM option is not currently exposed in Explorer or the `-c1`/`-c2` Carnivore2 loader modes. MultiROM supports `-w` for `-s1`, `-m1`, `-s2`, and `-m2` Nextor entries. Explorer has its own built-in ESP-01 path for File Hunter browsing and WiFi setup.
- The `-c1` and `-c2` modes are loader modes, not direct ROM-embedding modes. They boot Nextor first; the ROM is uploaded later from DOS into PSRAM.
- SCC/SCC+ audio for `SROM.COM /D15` uploads is enabled by building the loader UF2 with `-c1/-c2` plus `-scc` or `-sccplus` before flashing the cartridge.
- Linux/macOS binaries are not provided (use Windows or build from source).
- The tool does not verify ROM integrity beyond size and mapper heuristics.
- SCC/SCC+ flags are applied for Konami SCC mapper (type 3) and Manbow2 mapper (type 14) ROMs; otherwise they are ignored with a warning.
- SCC/SCC+ emulation is available in the current RP2350 LoadROM package.
- The `-4` / `--opl4` OPL4 / MoonSound build is a standalone sound cartridge: it embeds no game ROM, ignores all other options, and overclocks the RP2350 to 300 MHz. It requires the I2S DAC and the `/INT` line (GPIO40) on the PicoVerse 2350 board.
- A few extreme-polyphony MoonSound songs exceed the real-time synthesis budget of the `ymfm` core at 44.1 kHz and can underrun; `--22khz` trades some high-frequency detail for continuous playback on that material.
- The `-a` / `--msx-audio` MSX-AUDIO build is likewise a standalone sound cartridge: it embeds no game ROM, cannot be combined with `-4` or any other option except `-o` and `--4mhz`, occupies a whole slot, and requires the I2S DAC and the `/INT` line (GPIO40).
- In MSX-AUDIO mode the Philips NMS-1205 MIDI interface and the Music Module 8-bit DAC on port `0x0A` are not emulated, the Y8950 sound-enable pin is always on, the MSX-AUDIO keyboard reads back as "no keys pressed", and a second card on ports `0xC2`/`0xC3` is not decoded.
- Excessive flashing can wear out flash memory.

---

## Future improvements

- Cross-platform builds (Linux/macOS).
- Optional ROM integrity checks.
- GUI wrapper for mapper forcing.
- Additional mapper heuristics.

Author: Cristiano Almeida Goncalves  
Last updated: 07/26/2026

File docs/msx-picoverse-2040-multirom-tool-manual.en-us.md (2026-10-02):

# MSX PicoVerse 2040 Project

The PicoVerse 2040 is a Raspberry Pi Pico based cartridge for MSX that uses replaceable firmware to extend the computer’s capabilities. By loading different firmware images, the cartridge can run MSX games and applications and emulate additional hardware devices (such as ROM mappers, extra RAM, or storage interfaces), effectively adding virtual peripherals to the MSX. One such firmware is the MultiROM system, which provides an on‑screen menu for browsing and launching multiple ROM titles stored in the cartridge.

The cartridge can also expose the Pico’s USB‑C port as a mass‑storage device, allowing you to copy ROMs, DSKs, and other files directly from a PC with Windows or Linux to the cartridge.

Those are the features available in the current version of the PicoVerse 2040 cartridge:

* MultiROM menu system for selecting and launching MSX ROMs.
* Inline Menu option with Nextor OS support.
* USB mass-storage device support for loading ROMs and DSKs.
* Support for various MSX ROM mappers (PLA-16, PLA-32, KonSCC, PLN-48, PLN-64, ASC-08, ASC-16, ASC-16X, Konami, NEO-8, NEO-16, MANBW2).
* Compatibility with MSX, MSX2, and MSX2+ systems.

## MultiROM UF2 Creator Manual

This section documents the `multirom` console tool used to generate UF2 images (`multirom.uf2`) that program the PicoVerse 2040 cartridge.

In its default behavior, the `multirom` tool scans MSX ROM files in a directory and packages them into a single UF2 image that can be flashed to the Raspberry Pi Pico. The resulting image typically contains the Pico firmware, the MultiROM MSX menu ROM, a configuration area describing each ROM entry, and the ROM payloads themselves.

> **Note:** A maximum of 128 ROMs can be included in a single image, with a total size limit of aproximately 16 MB.

Depending on the options provided, `multirom` can also produce UF2 images that boot directly into a custom firmware instead of the MultiROM menu. For example, options can be used to produce UF2 files with a firmware that implements the Nextor OS. In this mode, the Pico’s USB‑C port can be used as a mass‑storage device for loading ROMs, DSKs, and other files from Nextor (for example, via SofaRun).

## Overview

If executed without any options, the `multirom.exe` tool scans the current working directory for MSX ROM files (`.ROM` or `.rom`), analyses each ROM to guess the mapper type, builds a configuration table describing each ROM (name, mapper byte, size, offset) and embeds this table into an MSX menu ROM slice. The tool then concatenates the Pico firmware blob, the menu slice, the configuration area and the ROM payloads and serializes the whole image into a UF2 file named `multirom.uf2`.



The UF2 file (usually multirom.uf2) can then be copied to a Pico's USB mass storage device to flash the combined image. You need to connect the Pico while pushing the BOOTSEL button to enter UF2 flashing mode. Then a new USB drive named `RPI-RP2` appears, and you can copy `multirom.uf2` to it. After the copy completes, you can disconnect the Pico and insert the cartridge into your MSX to boot the MultiROM menu.

ROM file names are used to name the entries in the MSX menu. There is a limit of 50 characters per name. A rolling effect is used to show longer names on the MSX menu, but if the name exceeds 50 characters it will be truncated.

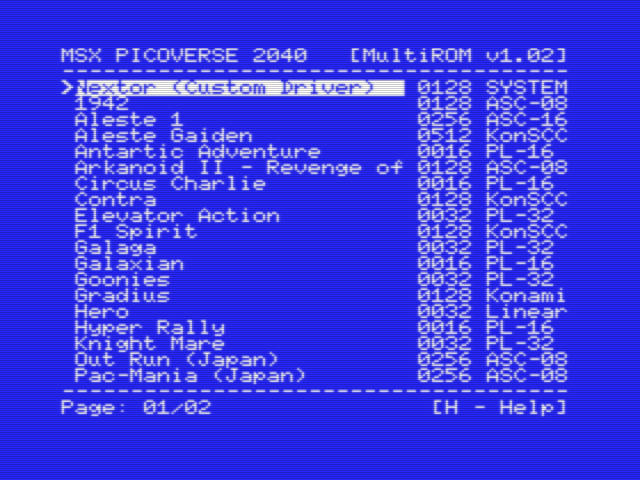
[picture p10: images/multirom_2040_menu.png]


> **Note:** To use a USB thumdrive you may need a OTG adapter or cable. That can be used to convert the USB-C port to a standard USB-A female port.

> **Note:** The `-s` option includes Sunrise IDE Nextor, and the `-m` option includes Sunrise IDE Nextor plus an additional 192KB mapper implementation. Both provide USB mass-storage support via the cartridge's USB-C port and work on MSX1, MSX2, and MSX2+ systems.

## Command-line usage

Only Microsoft Windows executables are provided for now (`multirom.exe`).

### Basic usage:

```
multirom.exe [options]
```

### Options:
- `-s`, `--sunrise` : Includes the embedded Sunrise IDE Nextor ROM for USB mass-storage support. The cartridge's USB-C port can be used as a block device with Nextor-compatible loaders like SofaRun.
- `-m`, `--mapper` : Includes the embedded Sunrise IDE Nextor ROM with 192KB mapper support (12 x 16KB pages). In the MSX menu this entry is still shown with mapper text `SYSTEM`.
- `-h`, `--help`   : Show usage help and exit.
- `-o <filename>`, `--output <filename>` : Set UF2 output filename (default is `multirom.uf2`).
- If you need to force a specific mapper type for a ROM file, you can append a mapper tag before the `.ROM` extension in the filename. The tag is case-insensitive. For example, naming a file `Knight Mare.PLA-32.ROM` forces the use of the PLA-32 mapper for that ROM. `SYSTEM` tags are ignored. The list of current tags is: `PLA-16, PLA-32, KonSCC, PLN-48, ASC-08, ASC-16, ASC-16X, Konami, NEO-8, NEO-16, PLN-64, MANBW2`.

### Examples
- Produces the multirom.uf2 file with the MultiROM menu and all `.ROM` files in the current directory. You can run the tool using the command prompt or just by double-clicking the executable:
  ```
  multirom.exe
  ```
- Produces a multirom UF2 that also includes a menu entry for Sunrise IDE Nextor + 192KB Mapper:
  ```
  multirom.exe -m -o multirom_mapper.uf2
  ```
  
## How it works (high level)

1. The tool scans the current working directory for files ending with `.ROM` or `.rom`. For each file:
   - It extracts a display-name (filename without extension, truncated to 50 chars).
   - It obtains the file size and validates it is between `MIN_ROM_SIZE` and `MAX_ROM_SIZE`.
   - It calls `detect_rom_type()` to heuristically determine the mapper byte to use in the configuration entry. If a mapper tag is present in the filename, it overrides the detection.
   - If mapper detection fails, the file is skipped.
   - It serializes the per-ROM configuration record (50-byte name, 1-byte mapper, 4-byte size LE, 4-byte flash-offset LE) into the configuration area.
2. After scanning, the tool concatenates (in order): embedded Pico firmware binary, a leading slice of the MSX menu ROM (`MENU_COPY_SIZE` bytes), the full configuration area (`CONFIG_AREA_SIZE` bytes), optional NEXTOR ROM, and then the discovered ROM payloads in discovery order.
3. The combined payload is written as a UF2 file named `multirom.uf2` using `create_uf2_file()` which produces 256-byte payload UF2 blocks targeted to the Pico flash address `0x10000000`.

## Mapper detection heuristics
- `detect_rom_type()` implements a combination of signature checks ("AB" header, `ROM_NEO8` / `ROM_NE16` / `ASCII16X` tags) and heuristic scanning of opcodes and addresses to pick common MSX mappers, including (but not limited to):
  - Plain 16KB (mapper byte 1) — 16KB AB header check
  - Plain 32KB (mapper byte 2) — 32KB AB header check
  - Planar48 mapper (mapper byte 4, tag `PLN-48`) — special AB layout check
  - Planar64 mapper (mapper byte 13, tag `PLN-64`) — 64KB planar layout
  - NEO8 (mapper byte 8) and NEO16 (mapper byte 9) — signature-based detection
  - ASCII16-X (mapper byte 12, tag `ASC-16X`) — `ASCII16X` signature at ROM offset 16
  - Manbow2 (mapper byte 14, tag `MANBW2`) — 512 KB Manbow 2 signature check
  - Konami, Konami SCC, ASCII8, ASCII16 and others via unit-weight scoring aligned with openMSX's `guessRomType()` algorithm
- Before applying heuristics, the tool computes the SHA-1 hash of the ROM and looks it up in an embedded database derived from the openMSX `softwaredb.xml`. When a match is found the database mapper type is used directly, bypassing the heuristic scanner. This improves accuracy for titles whose mapper cannot be reliably distinguished by opcode analysis alone.
- If no mapper can be reliably detected, the tool skips the ROM and reports "unsupported mapper". Remember you can force a mapper via filename tag. The tags are case-insensitive and are listed below. 
- Only the following mapper tags are supported in the configuration area and menu: `PLA-16, PLA-32, KonSCC, PLN-48, ASC-08, ASC-16, ASC-16X, Konami, NEO-8, NEO-16, PLN-64, MANBW2`.

## Using the MSX ROM Selector menu

When you power on the MSX with the PicoVerse 2040 cartridge inserted, the MultiROM menu appears, showing the list of available ROMs. You can navigate the menu using the keyboard arrow keys.



Use the Up and Down arrow keys to move the selection cursor through the list of ROMs. If you have more than 19 ROMs, use the lateral arrow keys (Left and Right) to scroll through pages of entries.

Press the Enter or Space key to launch the selected ROM. The MSX will attempt to boot the ROM using the appropriate mapper settings.

Press a letter key (A to Z) to jump straight to the first ROM whose name starts with that letter; the menu switches to the page that contains it.

At any time while in the menu, you can press the F1 key to read the help screen with basic instructions. Press any key to return to the main menu.

## Using Nextor with the PicoVerse 2040 cartridge

The `-s` option of the multirom tool includes Sunrise IDE Nextor ROM, and the `-m` option includes Sunrise IDE Nextor ROM plus an additional 192KB mapper implementation. When the multirom UF2 is flashed with either option, the Pico's USB-C port exposes a block device that Nextor-compatible loaders (such as SofaRun) can use to load ROMs, DSK files, and other media from a connected USB thumb drive.

The Sunrise IDE implementation uses ATA register emulation, making it compatible with a wide range of MSX systems including MSX1, MSX2, and MSX2+ models. 

### How to prepare a thumb drive for Nextor

To prepare a USB thumb drive for use with Nextor on the PicoVerse 2040 cartridge, follow these steps:

1. Connect the USB thumb drive to your PC.
2. Create a 4GB maximum FAT16 partition on the thumb drive. You can use built-in Nextor OS tool (CALL FDISK while in MSX Basic) or third-party partitioning software to do this.
3. Copy the Nextor system files to the root directory of the FAT16 partition. You can obtain the Nextor system files from the official Nextor distribution or repository. You also need the COMMAND2 file for the command shell:
   1.  [Nextor Download Page](https://github.com/Konamiman/Nextor/releases) 
   2.  [Command2 Download Page](http://www.tni.nl/products/command2.html)
4. Copy any MSX ROMs (`.ROM` files) or disk images (`.DSK` files) you want to use with Nextor to the root directory of the thumb drive.
5. Install SofaRun or any other Nextor-compatible launcher on the thumb drive if you plan to use it for launching ROMs and DSKs. You can download SofaRun from its official source here: [SofaRun](https://www.louthrax.net/mgr/sofarun.html)
6. Safely eject the thumb drive from your PC.
7. Connect the thumb drive to the PicoVerse 2040 cartridge using a USB OTG adapter or cable if necessary.

> **Note:** Not all USB thumb drives are compatible with the PicoVerse 2040 cartridge. If you encounter issues, try using a different brand or model of thumb drive.
>
> **Note:** Nextor needs a minimum of 128 KB of RAM to operate; PicoVerse 2040 mapper mode provides 192KB mapper RAM (12 x 16KB pages).

## Testing a MultiROM UF2 in openMSX

You can try a MultiROM UF2 in the openMSX emulator before flashing it. Install the openMSX add-on from [2040/software/multirom.pio/openmsx](../2040/software/multirom.pio/openmsx) as described in [MSX PicoVerse 2040 — MultiROM in openMSX](./msx-picoverse-2040-openmsx.md). Then, in openMSX, choose your `.uf2` file as the ROM image of a cartridge slot (Media > Cartridge Slot, with the **All files** filter). The emulated MSX boots the same PicoVerse menu with every entry in the UF2, including the Nextor Sunrise IDE entries. A disk image takes the place of the USB drive. After that, the **PicoVerse 2040 MultiROM** extension reloads the same UF2.

## Known issues

- Some ROMs with uncommon mappers may not be detected correctly and will be skipped unless a valid mapper tag is used to force detection.
- The MultiROM tool currently only supports Windows. 
- The tool does not currently validate the integrity of ROM files beyond size and basic header checks. Corrupted ROMs may lead to unexpected behavior.
- Due to the nature of MultiROM tool (embedding multiple files into a single UF2), some antivirus software may flag the executable as suspicious. This is a false positive; ensure you download the tool from a trusted source.
- The MultiROM menu does not support DSK files; only ROM files are listed and launched.
- The tool does not currently support subdirectories; only ROM files in the current working directory are processed.
- The pico flash memory can wear out after many write cycles. Avoid excessive re-flashing of the cartridge.

## Tested MSX models

The PicoVerse 2040 cartridge with MultiROM firmware has been tested on the following MSX models:

| Model | Type | Status | Comments |
| --- | --- | --- | --- |
| Adermir Carchano Expert 4 | MSX2+ | OK | Verified operation |
| Gradiente Expert | MSX1 | OK | Verified operation |
| JFF MSX | MSX1 | OK | Verified operation |
| MSX Book | MSX2+ (FPGA clone) | OK | Verified operation |
| MSX One | MSX1 | Not OK | Cartridge not recognized |
| National FS-4500 | MSX1 | OK | Verified operation |
| Omega MSX | MSX2+ | OK | Verified operation |
| Panasonic FS-A1GT | TurboR | OK | Verified operation |
| Panasonic FS-A1ST | TurboR | OK | Verified operation |
| Panasonic FS-A1WX | MSX2+ | OK | Verified operation |
| Panasonic FS-A1WSX | MSX2+ | OK | Verified operation |
| Sanyo Wavy 70FD | MSX2+ | OK | Verified operation |
| Sharp HotBit HB8000 | MSX1 | OK | Verified operation |
| SMX-HB | MSX2+ (FPGA clone) | OK | Verified operation |
| Sony HB-F1XD | MSX2 | OK | Verified operation |
| Sony HB-F1XDJ | MSX2 | OK | Verified operation |
| Sony HB-F1XV | MSX2+ | OK | Verified operation |
| Sony Hit-Bit 20HB | MSX1 | OK | Verified operation |
| TRHMSX | MSX2+ (FPGA clone) | OK | Verified operation |
| uMSX | MSX2+ (FPGA clone) | OK | Verified operation |
| Yamaha YIS604 | MSX1 | OK | Verified operation |

Sunrise IDE Nextor ROM (options `-s` and `-m`) has been tested on the following MSX models:

| Model | Type | Status | Comments |
| --- | --- | --- | --- |
| Adermir Carchano Expert 4 | MSX2+ | OK | Verified operation |
| Gradiente Expert | MSX1 | OK | Verified operation |
| JFF MSX | MSX1 | OK | Verified operation |
| MSX Book | MSX2+ (FPGA clone) | OK | Verified operation |
| National FS-4500 | MSX1 | OK | Verified operation |
| Omega MSX | MSX2+ | OK | Verified operation |
| Panasonic FS-A1GT | TurboR | OK | Verified operation |
| Panasonic FS-A1ST | TurboR | OK | Verified operation |
| Panasonic FS-A1WX | MSX2+ | OK | Verified operation |
| Panasonic FS-A1WSX | MSX2+ | OK | Verified operation |
| Sanyo Wavy 70FD | MSX2+ | OK | Verified operation |
| Sharp HotBit HB8000 | MSX1 | OK | Verified operation |
| SMX-HB | MSX2+ (FPGA clone) | OK | Verified operation |
| Sony HB-F1XD | MSX2 | OK | Verified operation |
| Sony HB-F1XDJ | MSX2 | OK | Verified operation |
| Sony HB-F1XV | MSX2+ | OK | Verified operation |
| Sony Hit-Bit 20HB | MSX1 | OK | Verified operation |
| TRHMSX | MSX2+ (FPGA clone) | OK | Verified operation |
| uMSX | MSX2+ (FPGA clone) | OK | Verified operation |
| Yamaha YIS604 | MSX1 | OK | Verified operation |

Author: Cristiano  Goncalves
Last updated: 03/29/2026

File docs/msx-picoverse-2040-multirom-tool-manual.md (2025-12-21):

# MSX PicoVerse 2040 Project

|PicoVerse Front|PicoVerse Back|
|---|---|
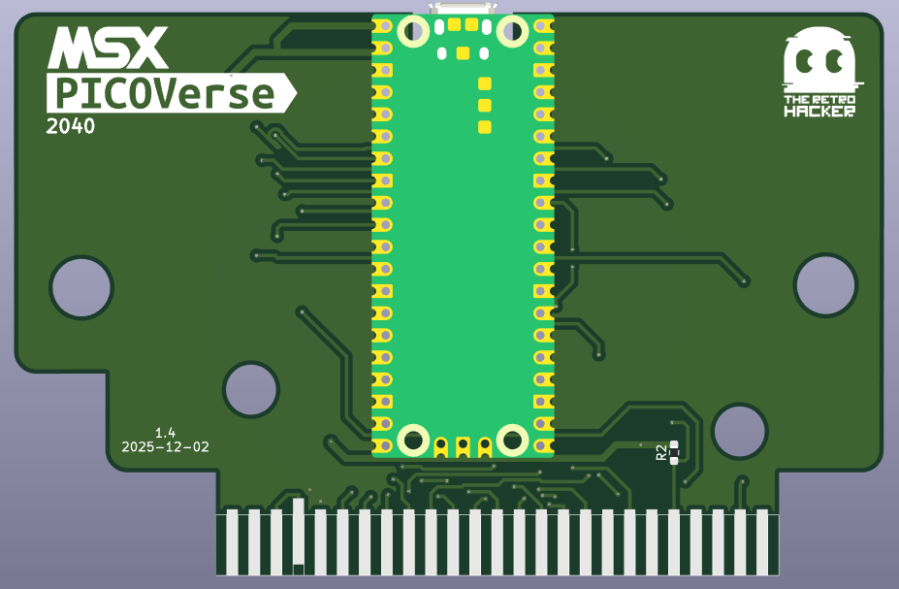
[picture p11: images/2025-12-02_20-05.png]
PicoVerse Front
||PicoVerse Back|

The PicoVerse 2040 is a Raspberry Pi Pico–based cartridge for MSX that uses replaceable firmware to extend the computer’s capabilities. By loading different firmware images, the cartridge can run MSX games and applications and emulate additional hardware devices (such as ROM mappers, extra RAM, or storage interfaces), effectively adding virtual peripherals to the MSX. One such firmware is the MultiROM system, which provides an on‑screen menu for browsing and launching multiple ROM titles stored in the cartridge.

The cartridge can also expose the Pico’s USB‑C port as a mass‑storage device, allowing you to copy ROMs, DSKs, and other files directly from a computer to the cartridge.

Additionally, you can use a Nextor firmware variant with +240 KB memory mapper support to take full advantage of the PicoVerse 2040 hardware on MSX systems with limited memory.

Those are the features available in the current version of the PicoVerse 2040 cartridge:

* MultiROM menu system for selecting and launching MSX ROMs.
* Nextor OS support with optional +240 KB memory mapper.
* USB mass-storage device support for loading ROMs and DSKs.
* Support for various MSX ROM mappers (PL-16, PL-32, KonSCC, Linear, ASC-08, ASC-16, Konami, NEO-8, NEO-16).
* Compatibility with MSX, MSX2, and MSX2+ systems.

## MultiROM UF2 Creator Manual

This section documents the `multirom` console tool used to generate UF2 images (`multirom.uf2`) that program the PicoVerse 2040 cartridge.

In it default behavior, the `multirom` tool scans MSX ROM files in a directory and packages them into a single UF2 image that can be flashed to the Raspberry Pi Pico. The resulting image typically contains the Pico firmware, the MultiROM MSX menu ROM, a configuration area describing each ROM entry, and the ROM payloads themselves.

Depending on the options provided, `multirom` can also produce UF2 images that boot directly into a custom firmware instead of the MultiROM menu. For example, options can be used to produce UF2 files with a firmware that implements the Nextor OS. In this mode, the Pico’s USB‑C port can be used as a mass‑storage device for loading ROMs, DSKs, and other files from Nextor (for example, via SofaRun).

## Overview

If executed without any options, the `multirom.exe` tool scans the current working directory for MSX ROM files (`.ROM` or `.rom`), analyses each ROM to guess the mapper type, builds a configuration table describing each ROM (name, mapper byte, size, offset) and embeds this table into an MSX menu ROM slice. The tool then concatenates the Pico firmware blob, the menu slice, the configuration area and the ROM payloads and serializes the whole image into a UF2 file named `multirom.uf2`.



The UF2 file (usually multirom.uf2) can then be copied to a Pico's USB mass storage device to flash the combined image. You need to connect the Pico while pushing the BOOTSEL button to enter UF2 flashing mode. Then a new USB drive named `RPI-RP2` appears, and you can copy `multirom.uf2` to it. After the copy completes, you can disconnect the Pico and insert the cartridge into your MSX to boot the MultiROM menu.

ROM file names are used to name the entries in the MSX menu. There is a limit of 50 characters per name. A rolling effect is used to show longer names on the MSX menu, but if the name exceeds 50 characters it will be truncated.



If you want to use Nextor with your PicoVerse 2040 cartridge you need to run the tool with the `-s1` or `-s2` option to include the embedded Nextor ROM in the image. The `-s1` option includes the standard Nextor ROM without memory mapper support, while `-s2` includes a Nextor ROM with +240 KB memory mapper support. The embedded Nextor ROM will be the single firmwware loaded at boot, and the MultiROM menu will not be available. You can then use SofaRun to load ROMs and DSKs from the Pico's USB mass storage.

**Important Note:** To use a USB thumdrive you may need a OTG adapter or cable. That can be used to convert the USB-C port to a standard USB-A female port.

## Constants and limits
- Maximum number of ROM files processed: `MAX_ROM_FILES = 128`.
- ROM filename length used in config: `MAX_FILE_NAME_LENGTH = 50`.
- Number of ROMS displayed in menu: `MAX_MENU_ENTRIES = 19`.
- Minimum ROM size accepted: `MIN_ROM_SIZE = 8192` bytes (8 KB).
- Maximum ROM size accepted: `MAX_ROM_SIZE = 10*1024*1024` bytes.
- The tool uses a fixed `TARGET_FILE_SIZE = 32768` bytes for the combined MSX menu ROM + configuration area and reserves `MENU_COPY_SIZE = 16 * 1024` (16KB) of the menu ROM to copy unchanged before the configuration payload.

## Command-line usage

Only Microsoft Windows executables are provided for now (`multirom.exe`).

### Basic usage:

```
multirom.exe [options]
```

### Options:
- `-n`, `--nextor` : Includes the beta embedded NEXTOR ROM from the configuration and outputs. This option is still experimental and at this moment only works on specific MSX2 models.
- `-h`, `--help`   : Show usage help and exit.
- `-o <filename>`, `--output <filename>` : Set UF2 output filename (default is `multirom.uf2`).
- `-s1`            : Cartridge boots with Sunrise IDE Nextor (no memory mapper).
- `-s2`            : Cartridge boots with Sunrise IDE Nextor (+240 KB memory mapper).
- If neither `-s1` nor `-s2` is specified, the tool produces a MultiROM image with the menu.
- If you need to force a specific mapper type for a ROM file, you can append a mapper tag before the `.ROM` extension in the filename. The tag is case-insensitive. For example, naming a file `Knight Mare.PL-32.ROM` forces the use of the PL-32 mapper for that ROM. Tags like `SYSTEM` are ignored.

### Examples
- Produces the multirom.uf2 file with the MultiROM menu and all `.ROM` files in the current directory. You can run the tool using the command prompt or just by double-clicking the executable:
  ```
  multirom.exe
  ```

- Produces the multirom.uf2 file with the Sunrise IDE Nextor ROM (no memory mapper):
  ```
  multirom.exe -s1
  ```
- Produces the multirom.uf2 file with the Sunrise IDE Nextor ROM (+240 KB memory mapper):
  ```
  multirom.exe -s2
  ```

## How it works (high level)

1. The tool scans the current working directory for files ending with `.ROM` or `.rom`. For each file:
   - It extracts a display-name (filename without extension, truncated to 50 chars).
   - It obtains the file size and validates it is between `MIN_ROM_SIZE` and `MAX_ROM_SIZE`.
   - It calls `detect_rom_type()` to heuristically determine the mapper byte to use in the configuration entry. If a mapper tag is present in the filename, it overrides the detection.
   - If mapper detection fails, the file is skipped.
   - It serializes the per-ROM configuration record (50-byte name, 1-byte mapper, 4-byte size LE, 4-byte flash-offset LE) into the configuration area.
2. After scanning, the tool concatenates (in order): embedded Pico firmware binary, a leading slice of the MSX menu ROM (`MENU_COPY_SIZE` bytes), the full configuration area (`CONFIG_AREA_SIZE` bytes), optional NEXTOR ROM, and then the discovered ROM payloads in discovery order.
3. The combined payload is written as a UF2 file named `multirom.uf2` using `create_uf2_file()` which produces 256-byte payload UF2 blocks targeted to the Pico flash address `0x10000000`.

## Mapper detection heuristics
- `detect_rom_type()` implements a combination of signature checks ("AB" header, `ROM_NEO8` / `ROM_NE16` tags) and heuristic scanning of opcodes and addresses to pick common MSX mappers, including (but not limited to):
  - Plain 16KB (mapper byte 1) — 16KB AB header check
  - Plain 32KB (mapper byte 2) — 32KB AB header check
  - Linear0 mapper (mapper byte 4) — special AB layout check
  - NEO8 (mapper byte 8) and NEO16 (mapper byte 9)
  - Konami, Konami SCC, ASCII8, ASCII16 and others via weighted scoring
- If no mapper can be reliably detected, the tool skips the ROM and reports "unsupported mapper". Remember you can force a mapper via filename tag. The tags are case-insensitive and are listed below. 
- Only the following mappers are supported in the configuration area and menu: `PL-16,  PL-32,  KonSCC,  Linear,  ASC-08,  ASC-16,  Konami,  NEO-8,  NEO-16`

## Using the MSX ROM Selector menu

When you power on the MSX with the PicoVerse 2040 cartridge inserted, the MultiROM menu appears, showing the list of available ROMs. You can navigate the menu using the keyboard arrow keys.

Use the Up and Down arrow keys to move the selection cursor through the list of ROMs. If you have more than 19 ROMs, use the lateral arrow keys (Left and Right) to scroll through pages of entries.

Press the Enter or Space key to launch the selected ROM. The MSX will attempt to boot the ROM using the appropriate mapper settings.

At any time while in the menu, you can press H key read the help screen with basic instructions. Press any key to return to the main menu.

## Using Nextor with the PicoVerse 2040 cartridge

If you flashed the cartridge with a Nextor firmware (using the `-s1` or `-s2` options), the cartridge will boot directly into Nextor instead of the MultiROM menu. Those options communicate with the MSX using memory-mapped I/O thus requiring the cartridge to be inserted into a standard cartridge slot. 

Once Nextor is running, you can use SofaRun or any other Nextor-compatible launcher to load ROMs and DSKs from the Pico's USB mass-storage device. You may need a USB OTG adapter or cable to connect standard USB-A thumb drives to the cartridge's USB-C port.

In MSX2 or MSX2+ systems with the +240 KB memory version of Nextor (S2 option), the cartridge will add the extra memory to the system and the BIOS sequence will reflect the increased RAM. Some MSX models display the total expanded memory during boot.

The -n option of the multirom tool includes an experimental embedded Nextor ROM that can be used on specific MSX2 models. However, this option is still under development and may not work on all systems. This version uses a different method (IO port based) to communicate with the MSX, allowing it to work on systems where the cartridge slot is not standard/expanded. 

More details on the protocol used to communicate with the MSX computer can be found in the Nextor-Pico-Bridge-Protocol.md document. The details of the communication with the Sunrise IDE Nextor firmware can be found in the Sunrise-Nextor.md document.

### How to prepare a thumb drive for Nextor

To prepare a USB thumb drive for use with Nextor on the PicoVerse 2040 cartridge, follow these steps:

1. Connect the USB thumb drive to your PC.
2. Create a 4GB maximum FAT16 partition on the thumb drive. You can use built-in OS tools or third-party partitioning software to do this.
3. Copy the Nextor system files to the root directory of the FAT16 partition. You can obtain the Nextor system files from the official Nextor distribution or repository. You also need the COMMAND2 file for the command shell:
   1.  [Nextor Download Page](https://github.com/Konamiman/Nextor/releases) 
   2.  [Command2 Download Page](http://www.tni.nl/products/command2.html)
4. Copy any MSX ROMs (`.ROM` files) or disk images (`.DSK` files) you want to use with Nextor to the root directory of the thumb drive.
5. Install SofaRun or any other Nextor-compatible launcher on the thumb drive if you plan to use it for launching ROMs and DSKs. You can download SofaRun from its official source here: [SofaRun](https://www.louthrax.net/mgr/sofarun.html)
6. Safely eject the thumb drive from your PC.

## Improvements ideas
- Improve the ROM type detection heuristics to cover more mappers and edge cases.
- Implement configuration screen for each ROM entry (name, mapper override, etc).
- Add support for more ROM mappers.
- Implement a graphical menu with better navigation and ROM information display.
- Add support for saving/loading menu configuration to preserve user preferences.
- Support DSK files as well, with proper configuration entries.
- Improve mapper detection heuristics to cover more mappers.
- Add support for custom menu ROM slices or themes.
- Allow downloading ROMs from Internet URLs and embedding them directly.
- Wireless (wifi) network support via external ESP-01 module.
- Allow the use of the joystick to navigate the menu.
- Support for zipping/compressing ROMs to save space.

## Known issues

- The embedded Nextor ROM inclusion is still experimental and may not work on all MSX2 models.
- Some ROMs with uncommon mappers may not be detected correctly and will be skipped unless a valid mapper tag is used to force detection.
- The tool currently only supports Windows executables. Linux and macOS versions are not available yet.
- The tool does not currently validate the integrity of ROM files beyond size and basic header checks. Corrupted ROMs may lead to unexpected behavior.
- The MultiROM menu does not support DSK files; only ROM files are listed and launched.
- The tool does not currently support subdirectories; only ROM files in the current working directory are processed.
- The pico flash memory can wear out after many write cycles. Avoid excessive re-flashing.

## Tested MSX models

The PicoVerse 2040 cartridge with MultiROM firmware has been tested on the following MSX models:

| Model | Type | Status | Comments |
| --- | --- | --- | --- |
| Adermir Carchano Expert 4 | MSX2+ | OK | Verified operation |
| Gradiente Expert | MSX1 | OK | Verified operation |
| JFF MSX | MSX1 | OK | Verified operation |
| MSX Book | MSX2+ (FPGA clone) | OK | Verified operation |
| MSX One | MSX1 | Not OK | Cartridge not recognized |
| National FS-4500 | MSX1 | OK | Verified operation |
| Panasonic FS-A1GT | TurboR | OK | Verified operation |
| Panasonic FS-A1ST | TurboR | OK | Verified operation |
| Panasonic FS-A1WX | MSX2+ | OK | Verified operation |
| Panasonic FS-A1WSX | MSX2+ | OK | Verified operation |
| Sharp HotBit HB8000 | MSX1 | OK | Verified operation |
| SMX-HB | MSX2+ (FPGA clone) | OK | Verified operation |
| Sony HB-F1XD | MSX2 | OK | Verified operation |
| Sony HB-F1XDJ | MSX2 | OK | Verified operation |
| Sony HB-F1XV | MSX2+ | OK | Verified operation |
| TRHMSX | MSX2+ (FPGA clone) | OK | Verified operation |
| uMSX | MSX2+ (FPGA clone) | OK | Verified operation |
| Yamaha YIS604 | MSX1 | OK | Verified operation |

The PicoVerse 2040 cartridge with Sunrise Nextor +240K firmware has been tested on the following MSX models:

| Model | Status | Comments |
| --- | --- | --- |
|MSX1|||
| Sharp HotBit HB8000 (MSX1) | Not OK | Memory mapper not working then Nextor not functional |
|MSX2+|||
| TRHMSX (MSX2+, FPGA clone) | OK | Verified operation |
| uMSX (MSX2+, FPGA clone) | OK | Verified operationAuthor: Cristiano Almeida Goncalves
Last updated: 12/20/2025

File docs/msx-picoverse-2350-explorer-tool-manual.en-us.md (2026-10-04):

# MSX PicoVerse 2350 Explorer Tool Manual (EN-US)

The Explorer tool creates a UF2 image that flashes the PicoVerse 2350 cartridge with the Explorer firmware. The UF2 bundles:
- PicoVerse 2350 Explorer firmware.
- The full 32KB MSX Explorer menu ROM.
- A configuration table describing each ROM stored in flash (stored in flash immediately after the menu ROM).
- The ROM payloads that will live in Pico flash.
- The integrated File Hunter browser and WiFi configuration support used by the Explorer menu.

Use the Explorer tool when you want a menu that loads ROMs from flash, microSD, embedded Sunrise Nextor SYSTEM entries, and the online File Hunter catalog on the PicoVerse 2350, or if you want to explore advanced features like microSD MP3 playback, SCC/SCC+ audio, Dual PSG audio, MSX-MUSIC, and optional primary PSG mirroring through the cartridge DAC on your MSX computer.

## Requirements

- Windows PC (the distributed binary is a Windows console app).
- A folder containing the `.ROM` files you want stored in flash.
- A PicoVerse 2350 cartridge and USB-C cable.
- Optional: a microSD card (for additional ROMs, MP3/WAV files, and Sunrise Nextor SD storage).
- Optional but required for File Hunter: an ESP-01 / ESP8266 module with compatible firmware, installed on the PicoVerse 2350 WiFi header and configured for your wireless network.

## Limits

- Flash ROM entries created by the tool: up to 128 files. ROMs copied from the microSD card with `F` count toward the same 128-entry list.
- Combined Explorer menu limit: 1024 entries per folder view (folders + ROMs + MP3s; the root view also includes ROM files stored directly on the flash memory).
- Total flash ROM payload size: ~14 MB combined.
- Supported ROM size range on the flash: 8 KB to ~14 MB.
- ROM names in the menu are limited to 60 characters (longer names are truncated).
- File Hunter search text is limited to 24 characters.
- File Hunter downloads are saved as `.ROM` or `.DSK` files directly in the root of the microSD card.

## Basic workflow

1. Put all `.ROM` files you want in the Pico flash into a single folder (no subfolders).
2. Run the tool in that folder to create `explorer.uf2`.
3. Put the PicoVerse 2350 into BOOTSEL mode and copy the UF2 to the `RPI-RP2` drive.
4. (Optional) Copy more `.ROM`, `.DSK` and `.MP3` files to a microSD card for SD loading.
5. (Optional) Insert an ESP-01 module and configure WiFi from the Explorer menu if you want to browse File Hunter.
6. Insert the cartridge into your MSX and power on.

You can also try the UF2 in the openMSX emulator before flashing it, with a PC folder as the microSD card: see [MSX PicoVerse 2350 — Explorer in openMSX](./msx-picoverse-2350-openmsx.md).
### Explorer menu capabilities

- **Folder navigation**: Organize your ROMs into folders on the microSD card. Enter folders by pressing Enter or Space on a folder name, and navigate back to parent folders using the ".." entry or by pressing Esc.
- **Search** by ROM name directly on the MSX by pressing `/`, typing part of the name, and pressing Enter to jump to the first match. Note that this feature only searches ROMs inside the current folder. When in the root, it searches all flash and SD ROMs located in the root.
- **File Hunter browser**: Press `F3` to browse online ROM results from File Hunter through the ESP-01 WiFi module, and press `T` to switch to `.DSK` disk images. Results show the name, size, source and type, and selected files can be downloaded and saved to the microSD root.
- **WiFi configuration**: Press `F4` to enter the WiFi setup flow used by the ESP8266P-compatible WiFi firmware.
- **Automatic detection** of MSX models that support 80-column text mode. Compatible machines boot the menu in 80 columns; others fall back to 40 columns, and you can press `C` at any time to toggle between layouts.
- MP3 entries from the microSD card are listed in the menu with a "MP3" type label and open an **MP3 player** screen when selected.
- `.DSK` disk images from the microSD card are listed with a "DSK" type label and **boot the MSX from the image** through the embedded Nextor kernel. A `.DSK` holding several disks joined together boots disk 1 and **swaps disks with the number keys**.
- ROM entries open a ROM screen that lets you inspect mapper detection, choose **audio profiles** including SCC/SCC+, Dual PSG, or MSX-MUSIC where supported, enable optional primary **PSG** mirroring to the DAC, and enable optional WiFi support for Sunrise Nextor entries before running.

## Command-line usage

```
explorer.exe [options]
```

### Options

- `-h`, `--help` : Show usage help and exit.
- `-o <filename>`, `--output <filename>` : Set UF2 output filename (default is `explorer.uf2`).
- `-a`, `--allnextor` : Include every embedded Nextor SYSTEM entry listed below (the eight Nextor Sunrise 2.1.4 entries `-s1` to `-r2`, plus the Nextor 3 beta entry `-s3`) while still scanning and appending `.ROM` files from the current folder.
- `-s1`, `--sunrise-sd` : Include Nextor Sunrise 2.1.4 using the on-board microSD card slot.
- `-m1`, `--mapper-sd` : Include Nextor Sunrise 2.1.4 on microSD plus the 1MB PSRAM-backed MSX memory mapper.
- `-c1`, `--carnivore2-sd` : Include Nextor Sunrise 2.1.4 on microSD plus the 1MB mapper and Carnivore2-compatible RAM-mode target for `SROM.COM /D15`.
- `-r1`, `--megaram-sd` : Include Nextor Sunrise 2.1.4 on microSD plus the 1MB mapper and a separate 1MB MegaRAM subslot.
- `-s2`, `--sunrise-usb` : Include Nextor Sunrise 2.1.4 using USB mass storage on the cartridge USB-C port.
- `-m2`, `--mapper-usb` : Include Nextor Sunrise 2.1.4 on USB plus the 1MB PSRAM-backed MSX memory mapper.
- `-c2`, `--carnivore2-usb` : Include Nextor Sunrise 2.1.4 on USB plus the 1MB mapper and Carnivore2-compatible RAM-mode target for `SROM.COM /D15`.
- `-r2`, `--megaram-usb` : Include Nextor Sunrise 2.1.4 on USB plus the 1MB mapper and a separate 1MB MegaRAM subslot.
- `-s3`, `--sunrise3-sd` : Include Nextor Sunrise 3.0.0 Beta 2 using the on-board microSD card slot, for testing the upcoming Nextor 3. It uses the Sunrise IDE MasterOnly kernel from Konamiman's [SunriseIDE Nextor driver](https://github.com/Konamiman/SunriseIDE-Nextor-driver/releases/tag/v0.1.8-blueMSX-v0.1.5-Nextor-3.0-beta.2) release and behaves like `-s1` otherwise. This is a beta kernel, so keep backups of the microSD card.

The Sunrise Nextor options can be combined. Each selected option creates a separate SYSTEM entry in the Explorer flash list, followed by any `.ROM` files found in the current folder. Use `-a` / `--allnextor` when you want all nine Nextor entries (eight Nextor 2.1.4 plus the Nextor 3 beta) in one UF2.

Nextor entries always show the Nextor version in the Explorer menu:

| Option | Menu entry name |
|---|---|
| `-s1` | `Nextor Sunrise 2.1.4 (SD)` |
| `-m1` | `Nextor Sunrise 2.1.4 + 1MB Mapper (SD)` |
| `-c1` | `Nextor Sunrise 2.1.4 + 1MB Mapper + C2 RAM (SD)` |
| `-r1` | `Nextor Sunrise 2.1.4 + 1MB Mapper + 1MB MegaRAM (SD)` |
| `-s2` | `Nextor Sunrise 2.1.4 (USB)` |
| `-m2` | `Nextor Sunrise 2.1.4 + 1MB Mapper (USB)` |
| `-c2` | `Nextor Sunrise 2.1.4 + 1MB Mapper + C2 RAM (USB)` |
| `-r2` | `Nextor Sunrise 2.1.4 + 1MB Mapper + 1MB MegaRAM (USB)` |
| `-s3` | `Nextor Sunrise 3.0.0 Beta 2 (SD)` |

Per-entry options (audio profile, PSG Mirror, WiFi, SD partition) are saved in a `.PVC` file named after the menu entry, so options saved by a UF2 that used the older names (`Nextor Sunrise IDE ...`) are not picked up and the entries start with default options.

### Example

```
explorer.exe
```

This scans the current directory and generates `explorer.uf2`.

```
explorer.exe -a
```

This includes every embedded Sunrise Nextor SYSTEM entry and also appends supported `.ROM` files from the current folder.

```
explorer.exe -s1 -r1 -r2 -o explorer_nextor.uf2
```

This includes the selected Nextor entries and the supported folder ROMs in one Explorer UF2.

```
explorer.exe -s1 -s3 -o explorer_nextor3.uf2
```

This includes Nextor 2.1.4 and the Nextor 3.0.0 Beta 2 microSD entries side by side, so both kernels can be tested on the same card.

## ROM mapper detection and tags

For the flash entries, the PC tool analyzes each ROM to determine the mapper. If you need to override it, add a mapper tag to the filename before `.ROM`. Tags are case-insensitive.

Supported tags:
`PLA-16`, `PLA-32`, `KonSCC`, `PLN-48`, `PLN-64`, `ASC-08`, `ASC-16`, `Konami`, `NEO-8`, `NEO-16`, `ASC16X`, `ASC16X-FR`, `MANBW2`.

Mapper detection on the Pico (for unknown SD ROMs) and on the PC tool both use a shared SHA-1 ROM database derived from openMSX's `softwaredb.xml`, falling back to heuristic scanning when the SHA-1 is not in the database.

Example:

```
Knight Mare.PLA-32.ROM
```

Notes:
- The `SYSTEM` tag is ignored and cannot be forced.
- Unsupported ROMs are skipped.

## ASCII16-X with FlashROM (`ASC16X-FR`)

ASCII16-X cartridges carry a real FlashROM chip, and the mapper specification lets software erase sectors and program bytes so a game can store save games, high scores or user created levels inside the cartridge itself.

Explorer provides two ASCII16-X mappers:

| Mapper | Tag | Behaviour |
| --- | --- | --- |
| 12 | `ASC16X` | Read-only cartridge. Bank switching only; flash command sequences are ignored. |
| 22 | `ASC16X-FR` | Adds the writable FlashROM device and persists it to the microSD card. |

Auto-detection is unchanged: a ROM recognised as ASCII16-X is always detected as plain `ASC16X`. FlashROM emulation is opt-in, either by tagging the file `<name>.ASC16X-FR.ROM` or by selecting **ASC16X-FR** in the **Mapper** field of the ROM screen.

With `ASC16X-FR` the cartridge implements the command set the specification names as the guaranteed minimum — autoselect, CFI query, chip erase, sector erase and byte program — plus the software reset. Sector geometry follows the documented bottom-boot layout: eight 8 KB sectors followed by 64 KB sectors.

The flash contents are mirrored to a file named after the ROM in the root of the microSD card:

```
/<ROM name>.FLA
```

The file has no header: it is a byte exact image of the cartridge flash, so it can be copied off the card and inspected, or used as a ROM image. It is matched to the running cartridge by name and size.

Notes:
- The image is created in full the first time the cartridge runs with a card that has no matching `.FLA`, while the MSX is still held at boot. Restoring an existing image happens at the same point, and the ROM screen shows "Preparing FlashROM image, please wait..." while either runs.
- Write-back runs on Core 0 during gaps in cartridge access, so saving works with every audio profile. The MSX may stutter briefly while a save is being written to the card.
- Without a usable microSD card the flash is still emulated, but its contents are lost at power off.
- The emulated device is sized to the next power of two at or above the ROM size, up to 8 MB (the full size the ASCII-X XL cartridges provide). When the MSX-MUSIC audio profile is active the bank cache has to live in PSRAM alongside the array, which lowers the ceiling to 4 MB.

## Using microSD with Explorer

Explorer can load ROMs from a microSD card in addition to flash. ROMs on SD are merged into the menu list and marked with the "SD" source tag. You can organize your ROM collection into folders for easier navigation.

- Format Explorer browsing partitions as FAT16, FAT32, or exFAT.
- Explorer can enumerate supported primary and logical partitions. Press `P` while in the `F2` microSD screen to cycle between supported partitions.
- The selected Explorer browsing partition is saved in `/PICOVERSE.PVC` on the first supported partition and restored on later boots.
- The lower status area shows the selected partition label and free MB. In 40-column mode, the label and free-space amount alternate so both remain readable.
- Copy `.ROM`, `.DSK` and `.MP3` files to the root of the card or organize them in subfolders for better organization.
- SD ROMs appear in the menu with the source label "SD".
- `.DSK` disk images appear in the menu with the "DSK" type label and boot through the embedded Nextor kernel (see [Running .DSK disk images](#running-dsk-disk-images)).
- MP3 files appear in the menu with the "MP3" type label and open the MP3 player screen.
- Flash ROMs appear with the source label "FL".
- File Hunter downloads are saved directly to the root of the microSD card and then appear as normal SD ROM or `.DSK` files in the Explorer root list.
- Folders are displayed in the menu and can be entered to browse their contents.
- The special ".." entry appears when inside a folder, allowing you to navigate back to the parent directory.

### Sunrise Nextor SD partitions in Explorer

Sunrise Nextor SYSTEM entries use stricter partition rules than the normal `F2` microSD browser. Nextor SD storage is offered only for FAT16 microSD partitions up to 4 GB. FAT32 and exFAT partitions remain usable for Explorer file browsing, ROM loading, MP3/WAV playback, and File Hunter downloads, but they are not offered to Sunrise Nextor SYSTEM ROMs.

When a Sunrise Nextor SYSTEM entry is opened in the ROM screen, Explorer shows the compatible FAT16 partition label in the `SD Part` option. If more than one compatible FAT16 partition exists, use Left/Right on `SD Part` to choose the partition before running. The selected partition is saved in that ROM's `.PVC` options file, so each Sunrise Nextor SYSTEM entry can remember its own storage partition.

### Running .DSK disk images

Explorer lists `.DSK` floppy disk images found on the microSD card next to the ROMs, with the "DSK" type label. Selecting one and choosing Run boots the MSX from that image (full technical details: [DSK Disk Image Support](./msx-picoverse-2350-dsk-support.md)):

- The image is copied into PSRAM and exposed to the MSX as the disk of a Sunrise IDE interface, driven by the Nextor 2.1.4 kernel that every Explorer UF2 embeds as a hidden payload (no `-s1`/`-a` option is required).
- Nextor mounts the image as a single unpartitioned FAT12 drive. Disks with an MSX-DOS 1 boot sector (the usual game disks with `MSXDOS.SYS`, `AUTOEXEC.BAS` or a boot-sector loader) make Nextor start in MSX-DOS 1 mode automatically; hold `1` during boot to force it for other disks.
- Writes (game saves, `SAVE`, `COPY`) are written straight through to the `.DSK` file on the card, sector by sector, so nothing is lost on power-off. The file's timestamp is not updated.
- The image boots read-only (writes report a disk error) when the file has the read-only attribute or is split into more than 16 fragments on the card. Copy a fragmented image to a freshly formatted card, or defragment it, to make it writable.
- Only standard floppy sizes are listed: the file size must be a multiple of 360 KB (368,640 bytes), made of 360 KB and 720 KB disks, up to 4 MB minus 1 KB. Files of any other size are not shown.
- `.DSK` entries offer **PSG Mirror**, **1MB Mapper**, and the same cartridge audio profiles as the `Nextor Sunrise 2.1.4` entries: **External SCC**, **External SCC+**, **FMPAC/MSX-MUSIC**, **YM2164 SFG05**, **YM2151 SFG01** (with their 4MHZ variants) and **Dual PSG**. The native SCC/SCC+ and MegaRAM SCC profiles, WiFi, mapper override, 50/60Hz and CPU speed options are not offered.
  - `1MB Mapper: Yes` boots the image with Nextor plus the 1 MB PSRAM memory mapper, like the `Nextor Sunrise 2.1.4 + 1MB Mapper` entries. Turn it on when a game keeps loading or crashes on a machine with little RAM, such as a 64 KB MSX2+.
  - `Audio: External SCC` / `External SCC+` (since v2.55) adds a virtual Konami SCC (or SCC+) cartridge in expanded subslot 2, for disk games that look for an SCC in another slot.
  - `Audio: FMPAC/MSX-MUSIC` (since v2.55) adds a virtual FM-PAC (FM-PAC BIOS + YM2413) in expanded subslot 2, for disk games with MSX-MUSIC on machines without built-in FM.
  - `Audio: YM2164 SFG05` / `YM2151 SFG01` (since v2.56, also as `4MHZ` variants) adds a virtual Yamaha SFG FM unit (SFG BIOS + YM2164/YM2151) in expanded subslot 2.
  - `Audio: Dual PSG` (since v2.56) adds a second PSG on I/O ports `10h`/`11h`, with no extra subslot.
  - All of these are the same profiles the `Nextor Sunrise 2.1.4` entries offer, and they combine with `1MB Mapper` and PSG Mirror.
  - All choices are saved per image.

#### Multi-disk games

Since Explorer v2.53, a game that came on several disks can be played from **one** `.DSK` file holding all of its disks joined in order:

```
copy /b "GAME (Disk 1).DSK" + "GAME (Disk 2).DSK" GAME.DSK
```

(On Linux or macOS: `cat "GAME (Disk 1).DSK" "GAME (Disk 2).DSK" > GAME.DSK`.)

- Explorer finds the disks inside the file and boots disk 1 in Nextor's disk emulation mode (always MSX-DOS 1).
- When the game asks for another disk, press that disk's number key, together with the key the game asks for, for example `2` + `SPACE` for "insert disk 2 and press space". Keys `1`–`9` select disks 1–9 and `A`–`W` select disks 10–32.
- Alternatively, press `GRAPH` while the disk is being read: the CAPS LED lights and the MSX waits for a disk key.
- The new disk is read on the next disk access. Press the key when the game asks for the disk; holding it while the game is loading continuously can hang Nextor.
- A reset boots disk 1 again. Holding `0` while booting skips emulation mode and boots disk 1 as a plain disk until the game is launched again from the menu.
- Saves go straight into the right disk inside the joined file.
- Up to 11 disks of 360 KB or 5 disks of 720 KB (plus one 360 KB disk) fit in one file.

Current limitations:

- Multi-disk files always boot MSX-DOS 1, so multi-disk software that needs MSX-DOS 2 will not run from a joined file.
- Copy-protected disks and software that programs a floppy controller directly do not work, because there is no floppy controller to emulate.
- Software that needs every byte of RAM may still fail under Nextor, which reserves more work area than a plain floppy disk ROM. Holding `SHIFT` while booting disables an internal floppy drive and frees some memory.
- On machines with an internal floppy drive, the cartridge's drive is `A:` only when the cartridge slot is scanned before the internal disk ROM.

### microSD limitations

- The combined list is capped at 1024 entries per folder view (folders + ROMs + MP3s; the root view can also include flash entries).
- microSD ROM files are limited to 4 MB each. ROMs are streamed into the cartridge's 8 MB external PSRAM (QMI CS1, 52.5 MHz QPI) and executed from there; the first 256 KB are mirrored into the PSRAM ROM cache for mapper access. ROMs larger than 4 MB are skipped during enumeration.
- Unsupported or invalid ROMs are skipped (same mapper and size rules as flash).

### Copying microSD ROMs to flash

Press `F` on a ROM in the `F2` microSD screen and answer `Y` to copy it into the cartridge's 16 MB flash. The bottom line shows the progress as a percentage, and when the copy is done the ROM appears in the `F1` flash list next to the ROMs added by the tool. To remove a flash entry again, press `D` on it in the `F1` screen.

- The copy keeps the ROM's mapper (detected, tagged in the file name, or chosen on the ROM screen in this session) and copies its `.PVC` options file, so audio and other saved settings carry over.
- Each copy goes into the first free 4 KB aligned space after the ROMs and hidden payloads written by the tool. Space freed by `D` is reused by later copies. The flash list holds up to 128 entries, including the ones made by the tool.
- Only ROMs can be copied (up to 4 MB, the microSD ROM limit). Folders, `.DSK` images and MP3/WAV files are not supported, and a ROM whose name is already in the flash list is refused. `Failed` is shown when the copy is not possible: no free space, a full flash list, unknown mapper, duplicate name, or a read error.
- A 1 MB ROM takes several seconds. While each flash block is erased the MSX waits for the cartridge, so the progress counter moves in steps. Switching the MSX off during a copy only loses that copy; the entry is written after the ROM image has been programmed and verified.
- `D` on a flash entry only marks its slot as deleted. After about 200 copy/delete operations the flash list is rewritten once to reclaim the deleted slots, which takes a fraction of a second.
- Writing a new UF2 with the tool replaces the flash list: ROMs copied from the microSD card have to be copied again.

### Renaming ROMs and disk images

Press `R` on a ROM or `.DSK` entry to rename it. The bottom line shows `Name:` with the current name; edit it with Backspace and the character keys, then press Enter to rename or Esc to cancel. Pressing Enter without changing anything leaves the entry as it is. The list is reloaded with the cursor on the renamed entry.

- **microSD files**: the file is renamed in its folder. Only the name shown in the menu changes: a mapper tag and the extension stay, so `Knight Mare.PLA-32.ROM` renamed to `Nightmare` becomes `Nightmare.PLA-32.ROM`. The `.PVC` options file and, for ROMs run as `ASC16X-FR`, the `.FLA` FlashROM save are renamed with it.
- **Flash entries**: only the menu entry changes, and the ROM data is not touched. The `/<name>.flash.PVC` options file (and the `.FLA` save of an `ASC16X-FR` ROM) is renamed too.
- Names can be up to 70 characters (32 in 40-column mode, where the field is limited by the screen width). Leading and trailing spaces and trailing dots are dropped, and the characters `\ / : * ? " < > |` are not allowed.
- `Failed` is shown when the name is not valid, another file or flash entry already uses it (flash names are compared ignoring case), an `ASC16X-FR` ROM would take over another ROM's `.FLA` save with the same name, or the microSD card cannot be written. Folders and MP3/WAV files cannot be renamed.
- Renaming the ROM that was executed last stops the menu from reopening on it at the next power-up.

### Performance note: MSX Response Time

MSX computers have slower processors compared to modern hardware. When navigating to a folder with a large number of ROMs (100+), the Pico will scan the directory contents and you will see a blinking "Loading..." message. This is normal behavior:

- **Small folders (< 50 ROMs)**: Directory listing typically completes in 1-2 seconds.
- **Large folders (100-900 ROMs)**: Directory listing may take over 5 seconds depending on the microSD card speed and the number of files.

For the best experience with very large ROM collections, consider organizing ROMs into subfolders by category (e.g., ACTION, PUZZLE, RPG) rather than storing all ROMs in a single folder.

## Menu usage (on MSX)

- **Up/Down**: Move selection up or down in the list.
- **Left/Right**: Change pages (when the list spans multiple pages).
- **Enter**: Open the selected entry. Folders enter the directory, MP3 entries open the MP3 player screen, and ROM entries open the ROM screen.
- **Space**: Enter folders and open MP3 entries like Enter. On ROM entries, quick-run the ROM using saved `.PVC` options when present or default settings when no `.PVC` file exists. Unknown SD ROM mappers are detected before launch.
- **Esc**: Navigate back to the parent folder (when inside a folder). Same as pressing Enter/Space on the ".." entry.
- **F1**: Switch the Explorer list to flash ROMs.
- **F2**: Switch the Explorer list to microSD files and folders.
- **F3**: Open the integrated File Hunter browser.
- **F4**: Open WiFi configuration.
- **H**: Show help screen.
- **P**: In the `F2` microSD screen, cycle through supported FAT16, FAT32, and exFAT partitions. The selected browsing partition is saved in `/PICOVERSE.PVC`.
- **D**: Delete the selected entry after a `Y/N` confirmation. In the `F2` microSD screen it deletes the file (folders are protected); in the `F1` flash screen it removes the flash entry. In both cases the entry's `.PVC` options file is removed too.
- **F**: In the `F2` microSD screen, copy the selected ROM into the cartridge flash after a `Y/N` confirmation. See [Copying microSD ROMs to flash](#copying-microsd-roms-to-flash).
- **R**: Rename the selected ROM or `.DSK` file on the microSD card, or the selected flash entry. See [Renaming ROMs and disk images](#renaming-roms-and-disk-images).
- **/**: Search ROM names. Type a partial name and press Enter to jump to the first matching ROM.
- **C**: Toggle between 40-column and 80-column layouts when your MSX supports it (auto-detects 80-column capable machines and defaults to 80 columns unless forced otherwise).

### Folder navigation workflow

1. The root menu lists all flash ROMs and files/folders from the microSD card root.
2. Folders appear in the list with a \<DIR\> indicator.
3. Press Enter or Space on a folder name to enter it and view its contents.
4. While loading a folder (especially large folders with many ROMs), you will see a blinking "Loading..." message on the bottom left corner. This is normal and indicates the Pico is scanning the directory.
5. Once loaded, navigate using Up/Down arrows as usual.
6. Press Esc or select the ".." entry to return to the parent folder or root.
7. Repeat to drill down through nested folders as needed.

## File Hunter browser

Explorer includes an integrated File Hunter browser for PicoVerse 2350 cartridges fitted with an ESP-01 / ESP8266 module. The browser talks directly from the Pico firmware to the ESP module, queries the public File Hunter service, downloads the selected ROM or `.DSK` disk image into PSRAM, and then saves it as a `.ROM` or `.DSK` file in the root of the microSD card.

The File Hunter integration is inspired by NataliaPC's MSX File Hunter Browser project and uses the public File Hunter catalog endpoint. See the external reference section near the end of this document for the upstream project link.

### Before using File Hunter

- Install an ESP-01 / ESP8266 module on the PicoVerse 2350 WiFi header.
- Use ESP firmware compatible with the ESP8266P / memio command protocol used by PicoVerse.
- Insert a FAT16, FAT32, or exFAT microSD browsing partition. File Hunter downloads are saved to the selected Explorer partition root.
- If the card has not been mounted in the current session, press `F2` once to open the microSD list before downloading from File Hunter.
- Configure WiFi from the Explorer menu if the ESP module has not already been configured for your network.

### Opening File Hunter

Press `F3` from the Explorer menu. The menu frame is drawn immediately, then the lower-left status area shows "Retrieving File Hunter" in 80-column mode or "Retrieving..." in 40-column mode while the first page is fetched.

Opening File Hunter always lists the latest releases, newest first, so the first page shows what was most recently added to File Hunter. The list is refreshed from the server every time you press `F3`, so returning to File Hunter never leaves you on the results of an earlier search. After the first page is loaded, the browser shows the File Hunter result list with the same Explorer frame, footer, page counter, and 40/80-column support used by the normal menu.

The first visit after power-on shows the ROM catalog. Press `T` to switch between the ROM catalog and the `.DSK` disk image catalog. Explorer remembers the last catalog until the MSX is reset, so `F3` reopens it.

### File Hunter list screen

Each result row shows:

- Name on the left.
- Size aligned to the right side of the row.
- Source label `FH`.
- Type label `ROM` or `DSK` aligned at the far right, matching the catalog being browsed.

In 40-column mode, long selected names slide horizontally while the cursor remains on the row. In 80-column mode, longer names fit directly in the wider row.

The footer shows which catalog is listed after the page counter: "Page: 01/05  Listing: ROM" / "Listing: DSK" in 80-column mode, or "Page:01/05 ROM" / "Page:01/05 DSK" in 40-column mode.

The network state appears in the lower-left status area as "Network: Online" / "Network: Offline" in 80-column mode or "Net: Online" / "Net: Offline" in 40-column mode. The standard command hints stay on the right side of the last line.

### File Hunter controls

- **Up/Down**: Move through the result list.
- **Left/Right**: Change result pages.
- **Enter**: Open the selected ROM detail screen.
- **Space**: Quick-run the selected ROM with saved `.PVC` options or default settings. If the ROM is on microSD and its mapper has not been detected yet, Explorer detects it before launching.
- **/**: Search File Hunter. Type a query and press Enter to load matching results. Press Esc at the search prompt to cancel.
- **T**: Switch between the ROM and `.DSK` catalogs. The current search is run again in the other catalog; with no search, the latest releases are listed.
- **F1**: Leave File Hunter and return to the flash ROM list.
- **F2**: Leave File Hunter and return to the microSD list.
- **F3**: File Hunter is already selected; pressing it again has no effect.
- **F4**: Open WiFi configuration.
- **C**: Toggle 40/80-column mode when supported.
- **Esc**: Exit File Hunter and return to the normal Explorer menu.

### Searching File Hunter

Press `/` while inside File Hunter, type part of a title, and press Enter. Explorer sends that text as the File Hunter query and reloads the result list from page 1. The search covers the catalog being browsed (ROM or DSK). Search text is limited to 24 characters.

If the ESP module is not connected to WiFi, the browser reports an offline state and the request fails instead of hanging indefinitely. When WiFi is still associating, the Pico waits briefly and shows a waiting status before reporting failure.

### ROM/DSK detail and download workflow

Selecting a File Hunter result opens a detail screen showing:

- ROM or DSK name.
- Size.
- Source: `FH`.
- Action: Download.

The footer shows only the detail actions (`[ESC - BACK] [ENTER - DOWNLOAD]`); the page counter and `F1`/`F2`/`F3` source shortcuts are hidden on this screen.

Press Enter or Space on the detail screen to download the selected file. Explorer first downloads it from File Hunter into PSRAM. The status line shows a `Download: NN%` counter from 0% to 100% while the download is active. After the download completes, the Pico saves the file from PSRAM to the root of the microSD card using the same filename shown by File Hunter, with a `.ROM` or `.DSK` extension.

When the save succeeds, the detail screen shows "Saved to microSD. Press key." Press any key to return to the File Hunter list. The Explorer root microSD list is refreshed after a successful save, so returning to the microSD root with `F2` lets you search for and launch the newly downloaded file as a normal SD ROM or `.DSK` entry.

A `.DSK` download is saved only if Explorer can boot it: its size must be a multiple of 360 KB and at most 4 MB minus 1 KB (see [Running .DSK disk images](#running-dsk-disk-images)). Other disk images, such as 180 KB single-sided disks, are rejected after the download with "Unsupported DSK size" and are not written to the card.

### File Hunter limitations and notes

- File Hunter requires a working ESP-01 / ESP8266 module and WiFi connection.
- A microSD card must be present because downloads are saved directly to the card root.
- Downloaded files use File Hunter's filename. If a file with the same name already exists in the microSD root, it is replaced.
- Download and save speed depends on WiFi quality, the ESP module firmware, File Hunter response time, and microSD card performance.
- File Hunter entries are online catalog results, not flash entries. After saving, they become SD ROM or `.DSK` entries.
- File Hunter lists each disk of a multi-disk game as a separate entry, so each disk is downloaded as its own `.DSK`. To swap disks with the number keys, join them into one `.DSK` on a PC (see [Running .DSK disk images](#running-dsk-disk-images)).

## Known limitations

- Flash ROMs packaged by the tool must be in the root of the source folder (no subfolders in the flashing process, though SD folders are fully supported in the menu).
- Embedded Sunrise Nextor entries require the matching storage device at runtime: FAT16 microSD partitions up to 4 GB for `-s1`/`-m1`/`-c1`/`-r1`/`-s3`, or USB mass storage for `-s2`/`-m2`/`-c2`/`-r2`.
- ROMs with unknown or unsupported mappers are skipped unless you force a mapper tag.
- Very deep folder nesting (more than 10+ levels) is supported but may have perception of slowness due to repeated folder scans.
- File Hunter browsing is unavailable without an ESP-01 / ESP8266 module, compatible ESP firmware, and a configured WiFi network.
- File Hunter downloads are stored in the root of the microSD card; Explorer does not create a separate File Hunter folder.
- ROMs copied to flash with `F` are lost when a new UF2 is written, because the tool rebuilds the flash list.

## MP3 player screen

Selecting an MP3 entry from the microSD card opens a dedicated player screen. MP3 files are not embedded in flash by the Explorer tool; copy them to the microSD card root or to folders on the card, then open the microSD list with `F2`.

The player screen shows the MP3 file name, size, playback status, and elapsed play time. The elapsed counter is refreshed while the screen is open. Total duration is not shown because Explorer does not scan the whole MP3 stream before playback.

The screen displays two selectable action rows:

1. **Action: Play / Stop**: starts playback when stopped, or stops the current file when playing or paused.
2. **Action: Pause / Resume**: pauses the current playback, or resumes it after pausing.

### Controls

- **Up/Down**: Move between the action rows.
- **Enter/Space**: Execute the selected action.
- **Esc**: Stop playback and return to the Explorer list.
- **C**: Toggle 40/80-column layout on supported systems.

### Audio behavior

MP3 decoding runs on the Pico side and streams stereo PCM to the cartridge I2S DAC. The MSX menu remains responsive while playback is active. The DAC mute line is released only while MP3 or ROM audio is active, and is muted again when playback stops or when Explorer returns to idle browsing.

## ROM screen

Selecting a ROM entry opens a ROM details screen before running:

- **Mapper**: Shows the detected mapper (for SD ROMs) and allows manual override using Left/Right. The cycle includes **ASC16X-FR**, which runs an ASCII16-X ROM with FlashROM emulation so the game can save into the cartridge; see [ASCII16-X with FlashROM](#ascii16-x-with-flashrom-asc16x-fr).
- **Audio**: Choose an audio profile with Left/Right (None, SCC, SCC+, external SCC/SCC+, Dual PSG, MSX-MUSIC, SFG01/SFG05, SFG01/SFG05 at 4 MHz). The menu only cycles through profiles supported by the selected ROM mapper.
- **PSG**: Choose whether to mirror the MSX primary PSG writes through the cartridge DAC. The default is Yes unless saved `.PVC` options override it.
- **Wifi**: For standalone Sunrise Nextor and Sunrise + 1MB mapper entries only, choose whether to expose the ESP8266P WiFi BIOS before running. Carnivore2 and MegaRAM Nextor entries do not expose WiFi. The default is No.
- **SD Part**: For Sunrise Nextor SD entries only, choose the FAT16 partition up to 4 GB that Nextor will boot from. The selected partition is saved with the ROM options.
- **Action: Run**: Press Enter to launch the ROM.
- **Esc**: Return to the menu without running.

If a ROM mapper is unknown, the screen will briefly show "Detecting..." while the Pico attempts detection.

### Audio profile options

- **None**: No extra cartridge audio profile. The ROM still uses the MSX's built-in PSG normally.
- **SCC**: Enables Konami SCC (standard) sound emulation. Use this for games that use the standard SCC chip with shared channel 4/5 waveforms (e.g., *Space Manbow*, *Salamander*, *Nemesis 2*, *Gradius 2*).
- **SCC+**: Enables Konami SCC+ (enhanced/SCC-I) sound emulation. Use this for games or homebrew that require SCC+ features with independent channel 4/5 waveforms.
- **SCC - External**: Exposes a virtual SCC cartridge in a secondary subslot while keeping the selected game mapper in the primary game subslot. Use this for ROMs that look for an SCC cartridge in another slot.
- **SCC+ - External**: Same as **SCC - External**, but with the enhanced SCC+ register model.
- **YM2151 (SFG05)**: Exposes a Yamaha SFG-05-like YM2151 cartridge surface and the SFG-05 BIOS image in a secondary subslot while keeping the selected game mapper in the primary game subslot. Use this for ROMs that scan another slot for SFG/YM2151 hardware.
- **YM2151 (SFG01)**: Exposes the SFG-01 BIOS image with the same YM2151 register surface for software that distinguishes SFG01/SFG05 setups.
- **YM2164 SFG05 4MHZ** and **YM2151 SFG01 4MHZ**: Identical to the two profiles above, except the emulated OPM/OPP core is clocked at 4 MHz instead of the MSX 3.579545 MHz clock. Because pitch, envelopes, LFO and the FM timers are all derived from the chip clock, everything plays back `4000000 / 3579545 = 1.1174x` faster. Use these for arcade conversions and music written for arcade boards, where the YM2151 is normally clocked at 4 MHz.
- **Dual PSG**: Enables a secondary AY-3-8910 compatible PSG on I/O ports `0x10` (register select) and `0x11` (data write), matching the common Carnivore2 / MegaFlashROM / FlashJacks style second-PSG convention. Use this for ROMs or patches that explicitly support dual PSG music.
- **MSX-MUSIC**: Enables YM2413/MSX-MUSIC audio using an FM-PAC-compatible BIOS from the Explorer UF2 flash payload. Use this for regular ROMs that can use MSX-MUSIC ports `0x7C` and `0x7D`; supported Sunrise Nextor SYSTEM entries also expose the FM-PAC BIOS in a free expanded subslot.

Explorer treats audio profiles as mutually exclusive: a ROM can run with no extra audio, SCC, SCC+, external SCC/SCC+, Dual PSG, MSX-MUSIC, or YM2151/SFG, but not multiple cartridge audio engines at the same time.

The **PSG** field is independent from the Audio profile. When set to **Yes**, Explorer mirrors writes to the primary MSX PSG ports `0xA0` and `0xA1`, generates matching AY/YM audio on the Pico, and sends that audio through the cartridge I2S DAC. The real MSX PSG is not disabled; the option provides a DAC-side copy of the main PSG. It can be combined with **None**, **SCC**, **SCC+**, external SCC/SCC+, **Dual PSG**, **MSX-MUSIC**, or **YM2151 (SFG01/SFG05)**, so PSG music can be heard through the cartridge DAC together with the selected cartridge audio profile. When **Dual PSG** and **PSG: Yes** are enabled together, Explorer routes Dual PSG to the left channel and the mirrored primary PSG to the right channel for a stereo split. The option defaults to **Yes** unless saved `.PVC` options override it.

The SCC and SCC+ audio profiles work with ROMs using the Konami SCC mapper (`KonSCC`) or the Manbow2 mapper (`MANBW2`). When a ROM is detected as `KonSCC` or `MANBW2`, the ROM screen pre-selects **SCC** in the Audio field; you can change it to None, SCC+, or one of the external SCC profiles before pressing Run. Dual PSG and MSX-MUSIC are not offered for these mappers because the cartridge audio slot is reserved for SCC/SCC+.

The external SCC and SCC+ profiles are available for non-SYSTEM ROM entries and supported Sunrise Nextor SYSTEM entries. Non-SYSTEM ROMs launch in an expanded cartridge layout with the selected game mapper in subslot 0 and the virtual SCC/SCC+ cartridge surface in subslot 1. Supported Sunrise Nextor SYSTEM launches keep Nextor storage in its normal subslot, keep mapper RAM available only for the explicit `+ 1MB Mapper` entries, and place the virtual SCC/SCC+ cartridge in subslot 2 without WiFi or subslot 3 when WiFi is enabled. MegaRAM Nextor entries reserve their expanded layout for Nextor, mapper RAM, and MegaRAM, so Explorer does not offer external SCC/SCC+ for those entries.

The YM2151 SFG01/SFG05 profiles are available for supported non-SYSTEM ROM entries and supported Sunrise Nextor SYSTEM entries. Non-SYSTEM ROMs use the same expanded layout as the external SCC profiles: subslot 0 remains the selected game mapper, while subslot 1 exposes an SFG-like memory-mapped YM2151 surface and the selected Yamaha SFG BIOS image. Supported Sunrise Nextor SYSTEM launches use a mapper-backed expanded layout so Nextor still has RAM available; the SFG surface is placed in subslot 2 without WiFi or subslot 3 when WiFi is enabled. MegaRAM Nextor entries reserve their expanded layout for Nextor, mapper RAM, and MegaRAM, so Explorer does not offer YM2151/SFG for those entries. The implemented SFG memory window responds at slot-local `0x3FF0` for the YM2151 address register and `0x3FF1` for YM2151 data/status. MIDI/keyboard-facing SFG addresses return idle values in this first implementation. The Explorer UF2 stores `SFG_64K.ROM` as a hidden flash payload; the SFG05 profile exposes the first 32K BIOS image and the SFG01 profile exposes the second 32K BIOS image.

The Dual PSG and MSX-MUSIC profiles are available for regular non-SYSTEM ROMs that are not Konami SCC or Manbow2, and supported Sunrise Nextor SYSTEM entries can use the SYSTEM audio service for the supported SYSTEM profiles. When MSX-MUSIC is selected for supported Sunrise Nextor entries, Explorer keeps the Nextor storage layout active and places the FM-PAC BIOS/control surface in subslot 2 without WiFi or subslot 3 with WiFi. These cartridge audio profiles are not offered for NEO system entries, folders, SCC-capable ROMs, Sunrise + 1MB mapper entries, Carnivore2 entries, or MegaRAM entries.

Primary PSG mirroring is intended for normal ROM launches from flash or microSD, including ROMs downloaded from File Hunter after they have been saved to the card. SYSTEM/storage entries that reserve core 1 for storage backends do not use the PSG DAC mirror path.

## SCC/SCC+ sound emulation

The PicoVerse 2350 Explorer firmware can emulate the Konami SCC and SCC+ (SCC-I) sound chips in hardware, generating audio through an I2S DAC connected to the RP2350. This gives MSX games that use SCC or SCC+ sound their full soundtrack without requiring an original SCC cartridge. Native SCC/SCC+ profiles attach the emulated SCC to Konami SCC or Manbow2 mapper launches; external SCC/SCC+ profiles expose the emulated chip as a separate virtual cartridge subslot for non-SYSTEM ROMs and Sunrise Nextor SYSTEM entries that search another slot for SCC hardware.

## Dual PSG sound emulation

The PicoVerse 2350 Explorer firmware can also emulate a second AY-3-8910 compatible PSG for ROMs that write to the standard secondary PSG ports. The Pico captures writes to `0x10` and `0x11`, feeds them to the emulated PSG, and streams the generated audio through the same I2S DAC path used by the other cartridge audio engines.

The MSX's internal PSG remains active as usual. The Dual PSG profile adds the external/secondary PSG only; software must be written or patched to use ports `0x10` and `0x11` for the extra three channels.

For firmware architecture, port handling, audio routing, and LoadROM/Explorer differences, see the [PicoVerse 2350 Dual PSG implementation guide](./msx-picoverse-2350-dualpsg.md).

## Primary PSG mirroring

Explorer can also mirror the normal MSX PSG output through the cartridge DAC. This is controlled by the separate **PSG** field on the ROM screen, not by the Audio profile field.

When **PSG: Yes** is selected, the Pico captures writes to the primary PSG ports `0xA0` and `0xA1`, feeds them to an AY/YM-compatible `emu2149` instance, and mixes the generated samples into the active I2S audio stream. If no other cartridge audio profile is selected, Explorer starts a PSG-only I2S audio loop. If SCC, SCC+, external SCC/SCC+, Dual PSG, MSX-MUSIC, or YM2151/SFG is selected, the primary PSG mirror is mixed into that profile's DAC stream. In the specific **Dual PSG + PSG** combination, Explorer outputs the Dual PSG stream on left and the primary PSG mirror on right.

This does not replace or mute the physical PSG inside the MSX. It is useful when you want ROM PSG music and effects on the same cartridge DAC output as SCC, Dual PSG, or MSX-MUSIC.

## MSX-MUSIC emulation

The PicoVerse 2350 Explorer firmware can emulate the YM2413/MSX-MUSIC audio chip and expose an FM-PAC-compatible BIOS in an expanded cartridge slot when the **MSX-MUSIC** audio profile is selected. The BIOS is stored as a hidden payload in the Explorer UF2 after the WiFi configuration and ESP8266P BIOS payloads; it is read from flash at launch time and is not compiled into the Pico firmware binary.

MSX-MUSIC uses I/O ports `0x7C` for register select and `0x7D` for data writes, with synthesized audio routed to the same I2S DAC path used by the other Explorer audio profiles. The profile is mutually exclusive with SCC, SCC+, and Dual PSG, and is only offered for regular non-SYSTEM ROMs that are not Konami SCC or Manbow2.

## YM2151 / Yamaha SFG emulation

Explorer can expose a virtual Yamaha SFG01/SFG05-style YM2151 device for supported non-SYSTEM ROMs and Sunrise Nextor SYSTEM entries. For game ROMs, the selected game mapper stays in subslot 0 and the SFG-like surface appears in subslot 1. For Sunrise Nextor SYSTEM entries, Explorer keeps the Nextor ROM and mapper RAM layout active and places the SFG-like surface in the free expanded subslot.

The SFG register window is memory-mapped, following the SFG layout used by emulator and hardware references: slot-local `0x3FF0` selects the YM2151 register, and slot-local `0x3FF1` writes YM2151 data or reads YM2151 status. Outside the top register aperture, the virtual SFG subslot reads from the selected 32K BIOS image stored in the Explorer flash payload.

## External references

- NataliaPC MSX File Hunter Browser: https://github.com/nataliapc/msx_filehunterbrowser
- File Hunter service: http://file-hunter.com/
- RBSC SFG_Cartridge project, used as an SFG register-map and cartridge behavior reference: https://github.com/RBSC/SFG_Cartridge
- openMSX Yamaha SFG implementation, used as an emulator behavior reference: https://github.com/openMSX/openMSX

Author: Cristiano Goncalves
Last updated: 06/13/2026

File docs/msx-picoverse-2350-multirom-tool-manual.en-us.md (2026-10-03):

# MSX PicoVerse 2350 MultiROM Tool Manual (EN-US)

The PicoVerse 2350 MultiROM tool creates a UF2 image that flashes the PicoVerse 2350 cartridge with:
- The PicoVerse 2350 MultiROM firmware.
- The MSX MultiROM menu ROM.
- A configuration table describing each ROM entry.
- The ROM payloads themselves.

Use this tool when you want to bundle multiple MSX ROM files into a single UF2 for the PicoVerse 2350.

## Requirements

- A Windows PC (the distributed binary is a Windows console application).
- Your MSX ROM files in a single folder (no subdirectories).
- A PicoVerse 2350 cartridge and a USB-C cable.

## Limits

- Maximum ROM files per image: 128.
- Maximum combined ROM payload size: ~14 MB.
- Per-ROM name length in menu: 50 characters (longer names are truncated in the menu list).

## Basic workflow

1. Place all `.ROM` files you want to include in a single folder.
2. Run the tool in that folder.
3. Copy the generated UF2 file to the PicoVerse 2350 in BOOTSEL mode.
4. Insert the cartridge into the MSX and power on to access the MultiROM menu.

## Command-line usage

```
multirom.exe [options]
```

### Options

| Flag | Description |
|---|---|
| `-h`, `--help` | Show usage help and exit. |
| `-o <filename>`, `--output <filename>` | Set UF2 output filename (default `multirom.uf2`). |
| `-a`, `--allnextor` | Include every embedded Nextor entry below (`-s1`, `-m1`, `-s2`, `-m2`, `-c1`, `-c2` and `-s3`) while still scanning and appending `.ROM` files from the current folder. |
| `-s1`, `--sunrise-sd` | Include Sunrise IDE Nextor ROM (microSD card). |
| `-m1`, `--mapper-sd` | Include Sunrise IDE Nextor ROM + 1MB PSRAM mapper (microSD card). |
| `-s2`, `--sunrise-usb` | Include Sunrise IDE Nextor ROM (USB pendrive). |
| `-m2`, `--mapper-usb` | Include Sunrise IDE Nextor ROM + 1MB PSRAM mapper (USB pendrive). |
| `-c1`, `--carnivore2-sd` | Include Sunrise IDE Nextor ROM + 1MB PSRAM mapper + Carnivore2 RAM-mode emulation (microSD card). |
| `-c2`, `--carnivore2-usb` | Include Sunrise IDE Nextor ROM + 1MB PSRAM mapper + Carnivore2 RAM-mode emulation (USB pendrive). |
| `-s3`, `--sunrise3-sd` | Include Nextor Sunrise 3.0.0 Beta 2 (microSD card), for testing the upcoming Nextor 3. Listed as `Nextor Sunrise 3.0.0 Beta 2 (SD)`. |
| `-scc`, `--scc` | Enable SCC sound emulation for Konami SCC and Manbow2 ROMs, and for ROMs uploaded via SROM in `-c1`/`-c2` Carnivore2 modes. |
| `-sccplus`, `--sccplus` | Enable SCC+ (enhanced) sound emulation for Konami SCC and Manbow2 ROMs, and for ROMs uploaded via SROM in `-c1`/`-c2` Carnivore2 modes. |
| `-w`, `--wifi` | Add ESP-01 WiFi BIOS sub-slot to every `-s1`/`-m1`/`-s2`/`-m2`/`-s3` Nextor entry. Requires at least one of those flags (or `-a`); the WiFi sub-slot is not added to `-c1`/`-c2` Carnivore2 entries. |

The Sunrise / Carnivore2 options can be freely combined. Each adds a separate SYSTEM entry to the menu, so you can pick the desired Nextor / Carnivore2 mode on the MSX. When `-scc` or `-sccplus` is used together with `-c1`/`-c2`, the processing list shows the Carnivore2 entry with a trailing `+SCC` or `+SCC+` marker (the SCC flag is encoded in the entry's mapper byte and applies only to the Carnivore2 entries; other Sunrise modes are unaffected). When `-w` is combined with `-s1`/`-m1`/`-s2`/`-m2`/`-s3`, those entries are listed with a trailing `+WiFi` marker and the embedded ESP8266P system ROM is appended right after each entry's Sunrise ROM payload in flash.

### Examples

Scan for ROMs with no Nextor entries:

```
multirom.exe
```

Include both Sunrise IDE SD and Sunrise IDE USB entries alongside scanned ROMs:

```
multirom.exe -s1 -s2
```

Include Sunrise IDE + mapper over microSD, with SCC emulation enabled for compatible ROMs:

```
multirom.exe -m1 -scc
```

Include Carnivore2 RAM-mode (USB) with SCC+ emulation for SROM-uploaded Konami SCC ROMs, alongside scanned ROMs:

```
multirom.exe -c2 -sccplus
```

Include Sunrise IDE + mapper over USB with ESP-01 WiFi support, alongside scanned ROMs:

```
multirom.exe -m2 -w
```

Include every Nextor entry (Nextor 2.1.4 on microSD and USB, the Carnivore2 modes, and the Nextor 3.0.0 Beta 2 microSD entry), alongside scanned ROMs:

```
multirom.exe -a
```

Test Nextor 3 next to Nextor 2.1.4 on the same microSD card:

```
multirom.exe -s1 -s3
```

## Flashing the UF2

1. Hold BOOTSEL on the PicoVerse 2350 while connecting USB.
2. The `RPI-RP2` drive appears.
3. Copy `multirom.uf2` to the drive.
4. The drive disconnects automatically after flashing.

## ROM mapper detection

The tool analyzes each ROM to determine the correct mapper type, applying the following steps in order:

1. **SHA-1 database lookup** — The ROM's SHA-1 hash is checked against an embedded database derived from the openMSX `softwaredb.xml`. A match overrides the heuristic and returns the definitive mapper type.

2. **Signature checks** — Special byte signatures are checked:
   - 16 KB ROM with `AB` header → Plain16.
   - ≤ 32 KB ROM with `AB` header → Plain32 (or Planar48 if `AB` also at 0x4000).
   - `ASCII16X` at offset 16 → ASCII16-X.
   - `ROM_NEO8` / `ROM_NE16` at offset 16 → NEO-8 / NEO-16.
   - 512 KB ROM with `Manbow 2` at offset 0x28000 → Manbow2.
   - ≤ 48 KB ROM with `AB` at 0x4000 → Planar48.
   - 64 KB ROM with `AB` at 0x4000 → Planar64.

3. **Heuristic scoring** — For ROMs larger than 32 KB, the tool scans for Z80 `ld (nnnn),a` instructions referencing mapper register addresses. Each candidate address increments the score for its associated mapper type. The mapper with the highest score wins (ties broken by later type, matching openMSX).

4. **Fallback** — 64 KB ROMs with an `AB` header and no detected mapper writes are classified as Planar64. Larger ROMs with no detected writes use raw address density as a secondary hint.

## Mapper tag forcing

If auto-detection fails or you want to override it, add a mapper tag to the filename before `.ROM`. Tags are case-insensitive.

Forceable tags:

| Tag | Mapper | Aliases |
|-----|---|---|
| `PLA-16` | Plain 16 KB | `PL-16` |
| `PLA-32` | Plain 32 KB | `PL-32` |
| `KonSCC` | Konami SCC | |
| `PLN-48` | Planar 48 KB | `PL-48`, `LINEAR`, `LINEAR0`, `PLANAR48`, `PLN-32`, `PLANAR32` |
| `ASC-08` | ASCII 8 KB | |
| `ASC-16` | ASCII 16 KB | |
| `ASC16X` | ASCII16-X (flash) | |
| `Konami` | Konami (no SCC) | |
| `NEO-8` | NEO 8 KB | |
| `NEO-16` | NEO 16 KB | |
| `PLN-64` | Planar 64 KB | `PL-64`, `PLANAR64` |
| `MANBW2` | Manbow2 | `MANBOW2`, `MBW-2` |

`SYSTEM` tags are ignored (Sunrise IDE entries cannot be forced via filename).

Example:

```
Knight Mare.PLA-32.ROM
```

## Supported mapper types

| # | Type | Tag | Notes |
|---|---|-----|---|
| 1 | Plain 16 KB | `PLA-16` | Single 16 KB bank at 4000h–7FFFh |
| 2 | Plain 32 KB | `PLA-32` | 32 KB at 4000h–BFFFh |
| 3 | Konami SCC | `KonSCC` | 8 KB banking; SCC auto-enabled |
| 4 | Planar 48 KB | `PLN-48` | Linear mapping for 32/48 KB ROMs with AB at 0x4000 |
| 5 | ASCII 8 KB | `ASC-08` | 8 KB bank switching |
| 6 | ASCII 16 KB | `ASC-16` | 16 KB bank switching |
| 7 | Konami | `Konami` | 8 KB banking without SCC |
| 8 | NEO 8 KB | `NEO-8` | FlashROM-compatible 8 KB banking |
| 9 | NEO 16 KB | `NEO-16` | FlashROM-compatible 16 KB banking |
| 10 | Sunrise IDE (USB) | SYSTEM | Nextor 2.1.4 Sunrise IDE via USB (`-s2`) |
| 11 | Sunrise IDE + Mapper (USB) | SYSTEM | Nextor + 1MB PSRAM mapper via USB (`-m2`) |
| 12 | ASCII16-X | `ASC16X` | ASCII16 + SST-compatible flash commands |
| 13 | Planar 64 KB | `PLN-64` | Full 64 KB linear mapping (0000h–FFFFh) |
| 14 | Manbow2 | `MANBW2` | Konami SCC banking + AM29F040B flash emulation |
| 15 | Sunrise IDE (SD) | SYSTEM | Nextor 2.1.4 Sunrise IDE via microSD (`-s1`); also used by the Nextor 3.0.0 Beta 2 entry (`-s3`) |
| 16 | Sunrise IDE + Mapper (SD) | SYSTEM | Nextor + 1MB PSRAM mapper via microSD (`-m1`) |
| 17 | Carnivore2 (SD) | SYSTEM | Nextor + 1MB mapper + Carnivore2 RAM-mode emulation via microSD (`-c1`) |
| 18 | Carnivore2 (USB) | SYSTEM | Nextor + 1MB mapper + Carnivore2 RAM-mode emulation via USB (`-c2`) |

## SCC / SCC+ emulation

- ROMs detected or forced as `KonSCC` (mapper 3) or `MANBW2` (mapper 14) can have SCC/SCC+ sound emulation.
- For Carnivore2 modes (`-c1` / `-c2`), the SCC flag applies to ROMs uploaded into the cartridge through the Carnivore2 SROM utility (`c2ramldr`) — the emulator listens to the standard Konami SCC / SCC+ register windows whenever an SCC-class ROM has been written to PSRAM.
- Use `-scc` for standard SCC emulation or `-sccplus` for enhanced SCC+ mode.
- The `-scc` and `-sccplus` flags are mutually exclusive.
- The flags apply globally to the build; non-SCC mapper types ignore them.
- Audio is output through the I2S DAC connected to the RP2350.

## Sunrise IDE Nextor

The Sunrise IDE options embed the Nextor 2.1.4 Sunrise IDE kernel ROM (128 KB) into the MultiROM image. Each option adds a SYSTEM entry that appears in the MSX menu alongside regular ROM entries.

### Nextor 3 beta (`-s3`)

- Embeds Konamiman's Nextor 3.0.0 Beta 2 Sunrise IDE MasterOnly kernel (128 KB, from the [SunriseIDE Nextor driver](https://github.com/Konamiman/SunriseIDE-Nextor-driver/releases/tag/v0.1.8-blueMSX-v0.1.5-Nextor-3.0-beta.2) release) instead of Nextor 2.1.4.
- microSD only for now; it uses the same firmware path as `-s1`, so everything in the microSD section below applies.
- It is a beta kernel: keep backups of the microSD card.

### USB modes (`-s2`, `-m2`)

- Storage is accessed via USB mass storage (flash drives, USB-to-SD adapters) through the cartridge's USB-C port.
- Core 1 runs the TinyUSB USB host stack with asynchronous MSC read/write.
- Device info for ATA IDENTIFY comes from the USB SCSI INQUIRY response.

### microSD modes (`-s1`, `-m1`, `-s3`)

- Storage is accessed via the on-board microSD card slot (SPI at 31.25 MHz).
- Real card identification (OEM, product name, revision) from the SD CID register is shown during Nextor boot.

### Mapper modes (`-m1`, `-m2`)

- Combines Nextor Sunrise IDE with a 1MB PSRAM memory mapper (64 × 16 KB pages).
- Uses an expanded sub-slot architecture: sub-slot 0 serves the Nextor ROM, sub-slot 1 provides mapper RAM.
- Mapper page registers (I/O ports FC–FF) are intercepted via PIO1.
- A bootstrap ROM phase ensures a clean cold-boot before the expanded-slot mapper is activated.

### Carnivore2 modes (`-c1`, `-c2`)

- Builds on the `-m1` / `-m2` infrastructure and adds an emulation of the Carnivore2 RAM-mode cartridge so SROM utilities (`c2ramldr`, `bdosldr`, etc.) can upload Konami / ASCII / Sunrise-mapper ROMs into the cartridge's PSRAM and launch them.
- Sub-slot layout matches the real Carnivore2 (`Sltsl_C` / `Sltsl_D` / `Sltsl_M`):
  - Sub-slot 0: Carnivore2 register window + bank windows (1 MB SROM upload target).
  - Sub-slot 1: Nextor 2.1.4 Sunrise IDE BIOS (USB or microSD backend, same as `-s1`/`-s2`).
  - Sub-slot 2: 1 MB MSX memory mapper RAM (same as `-m1`/`-m2`).
- Implements the Carnivore2 register block (`CardMDR`, `R1..R4` configs with `Mask/Addr/Reg/Mult/MaskR/AdrD`, `AddrFR`), the port `0xF0+PFXN` `'C'/'S'` handshake used by SROM, the AMD autoselect chip-ID probe (`M29W640GB`) used by `c2ramldr`, and the `CMFCCFRC` firmware signature overlay at `0x4010-0x4017`.
- When `-scc` or `-sccplus` is added, the cartridge also emulates the Konami SCC / SCC+ register window so SROM-uploaded SCC-class ROMs play music. Audio is mixed by the same I2S path used by the regular `-scc` modes (PIO1 SM2 + auto-claimed DMA channel; service is polled from the storage Core 1 task loop so it does not block USB / SD I/O).
- The 1 MB Carnivore2 RAM region is allocated from the same PSRAM bump allocator that backs the mapper RAM, so the cartridge needs the on-board PSRAM to be present and initialised. If allocation fails the firmware halts at the dispatch entry instead of booting.

## Menu usage (on MSX)

- Up/Down: move selection.
- Left/Right: change pages.
- Enter/Space: load selected ROM.
- A-Z: jump to the first ROM whose name starts with that letter (case-insensitive), switching to its page if needed.
- F1: show help screen.

SYSTEM entries (Sunrise IDE) appear alongside regular ROM entries and are selected the same way.

## Notes

- Only ROM files in the current folder are included (no subfolders).
- Unsupported or invalid ROMs are skipped with a message.
- Manbow2 save data is volatile (SRAM-backed, lost on power-off).
- ASCII16-X flash write emulation is SRAM-backed (volatile).
- The Sunrise options (`-s1`, `-m1`, `-s2`, `-m2`, `-c1`, `-c2`) can be combined — each adds its own menu entry.

Author: Cristiano Almeida Goncalves
Last updated: 04/26/2026

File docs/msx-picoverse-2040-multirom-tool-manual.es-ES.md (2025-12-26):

# Proyecto MSX PicoVerse 2040

|PicoVerse Frontal|PicoVerse Trasero|
|---|---|
|PicoVerse Frontal|PicoVerse Trasero|

El PicoVerse 2040 es un cartucho para MSX basado en Raspberry Pi Pico que utiliza firmware reemplazable para ampliar las capacidades del ordenador. Al cargar diferentes imágenes de firmware, el cartucho puede ejecutar juegos y aplicaciones de MSX y emular dispositivos de hardware adicionales (como mappers de ROM, RAM extra o interfaces de almacenamiento), añadiendo efectivamente periféricos virtuales al MSX. Uno de estos firmwares es el sistema MultiROM, que proporciona un menú en pantalla para navegar y lanzar múltiples títulos de ROM almacenados en el cartucho.

El cartucho también puede exponer el puerto USB-C de la Pico como un dispositivo de almacenamiento masivo, lo que permite copiar ROMs, DSKs y otros archivos directamente desde un PC con Windows o Linux al cartucho.

Estas son las características disponibles en la versión actual del cartucho PicoVerse 2040:

* Sistema de menú MultiROM para seleccionar y lanzar ROMs de MSX.
* Opción de menú en línea con soporte para Nextor OS.
* Soporte de dispositivo de almacenamiento masivo USB para cargar ROMs y DSKs.
* Soporte para varios mappers de ROM de MSX (PL-16, PL-32, KonSCC, Linear, ASC-08, ASC-16, Konami, NEO-8, NEO-16).
* Compatibilidad con sistemas MSX, MSX2 y MSX2+.

## Manual del Creador de UF2 MultiROM

Esta sección documenta la herramienta de consola `multirom` utilizada para generar imágenes UF2 (`multirom.uf2`) que programan el cartucho PicoVerse 2040.

En su comportamiento predeterminado, la herramienta `multirom` escanea archivos ROM de MSX en un directorio y los empaqueta en una sola imagen UF2 que se puede flashear en la Raspberry Pi Pico. La imagen resultante suele contener el firmware de la Pico, la ROM del menú MSX de MultiROM, un área de configuración que describe cada entrada de ROM y los propios contenidos de las ROM.

> **Nota:** Se puede incluir un máximo de 128 ROMs en una sola imagen, con un límite de tamaño total de aproximadamente 16 MB.

Dependiendo de las opciones proporcionadas, `multirom` también puede producir imágenes UF2 que arrancan directamente en un firmware personalizado en lugar del menú MultiROM. Por ejemplo, se pueden usar opciones para producir archivos UF2 con un firmware que implementa el Nextor OS. En este modo, el puerto USB-C de la Pico se puede usar como un dispositivo de almacenamiento masivo para cargar ROMs, DSKs y otros archivos desde Nextor (por ejemplo, a través de SofaRun).

## Descripción general

Si se ejecuta sin ninguna opción, la herramienta `multirom.exe` escanea el directorio de trabajo actual en busca de archivos ROM de MSX (`.ROM` o `.rom`), analiza cada ROM para adivinar el tipo de mapper, construye una tabla de configuración que describe cada ROM (nombre, byte de mapper, tamaño, desplazamiento) e incrusta esta tabla en una sección de la ROM del menú de MSX. Luego, la herramienta concatena el binario del firmware de la Pico, la sección del menú, el área de configuración y los contenidos de las ROM, y serializa toda la imagen en un archivo UF2 llamado `multirom.uf2`.



El archivo UF2 (normalmente multirom.uf2) se puede copiar a un dispositivo de almacenamiento masivo USB de la Pico para flashear la imagen combinada. Debe conectar la Pico mientras presiona el botón BOOTSEL para entrar en el modo de flasheo UF2. Luego aparece una nueva unidad USB llamada `RPI-RP2`, y puede copiar `multirom.uf2` en ella. Una vez completada la copia, puede desconectar la Pico e insertar el cartucho en su MSX para arrancar el menú MultiROM.

Los nombres de los archivos ROM se utilizan para nombrar las entradas en el menú de MSX. Hay un límite de 50 caracteres por nombre. Se utiliza un efecto de desplazamiento para mostrar nombres más largos en el menú de MSX, pero si el nombre supera los 50 caracteres, se truncará.



> **Nota:** Para usar una memoria USB, es posible que necesite un adaptador o cable OTG. Esto se puede usar para convertir el puerto USB-C en un puerto USB-A hembra estándar.

> **Nota:** La opción `-n` incluye una ROM Nextor integrada experimental que funciona en modelos específicos de MSX2. Esta versión utiliza un método de comunicación diferente (basado en puertos de E/S) y puede no funcionar en todos los sistemas.

## Uso de la línea de comandos

Por ahora solo se proporcionan ejecutables para Microsoft Windows (`multirom.exe`).

### Uso básico:

```
multirom.exe [opciones]
```

### Opciones:
- `-n`, `--nextor` : Incluye la ROM NEXTOR integrada beta de la configuración y las salidas. Esta opción es todavía experimental y en este momento solo funciona en modelos específicos de MSX2.
- `-h`, `--help`   : Muestra la ayuda de uso y sale.
- `-o <nombre_archivo>`, `--output <nombre_archivo>` : Establece el nombre del archivo UF2 de salida (el valor predeterminado es `multirom.uf2`).
- Si necesita forzar un tipo de mapper específico para un archivo ROM, puede añadir una etiqueta de mapper antes de la extensión `.ROM` en el nombre del archivo. La etiqueta no distingue entre mayúsculas y minúsculas. Por ejemplo, nombrar un archivo `Knight Mare.PL-32.ROM` fuerza el uso del mapper PL-32 para esa ROM. Las etiquetas como `SYSTEM` se ignoran. La lista de etiquetas posibles que se pueden usar es: `PL-16, PL-32, KonSCC, Linear, ASC-08, ASC-16, Konami, NEO-8, NEO-16`

### Ejemplos
- Produce el archivo multirom.uf2 con el menú MultiROM y todos los archivos `.ROM` en el directorio actual. Puede ejecutar la herramienta usando el símbolo del sistema o simplemente haciendo doble clic en el ejecutable:
  ```
  multirom.exe
  ```

## Cómo funciona (nivel alto)

1. La herramienta escanea el directorio de trabajo actual en busca de archivos que terminen en `.ROM` o `.rom`. Para cada archivo:
   - Extrae un nombre para mostrar (nombre de archivo sin extensión, truncado a 50 caracteres).
   - Obtiene el tamaño del archivo y valida que esté entre `MIN_ROM_SIZE` y `MAX_ROM_SIZE`.
   - Llama a `detect_rom_type()` para determinar heurísticamente el byte del mapper a usar en la entrada de configuración. Si hay una etiqueta de mapper en el nombre del archivo, esta anula la detección.
   - Si falla la detección del mapper, se omite el archivo.
   - Serializa el registro de configuración por ROM (nombre de 50 bytes, mapper de 1 byte, tamaño de 4 bytes LE, desplazamiento de flash de 4 bytes LE) en el área de configuración.
2. Después del escaneo, la herramienta concatena (en orden): el binario del firmware de la Pico integrado, una sección inicial de la ROM del menú MSX (bytes `MENU_COPY_SIZE`), el área de configuración completa (bytes `CONFIG_AREA_SIZE`), la ROM NEXTOR opcional y luego los contenidos de las ROM descubiertas en el orden de descubrimiento.
3. El contenido combinado se escribe como un archivo UF2 llamado `multirom.uf2` usando `create_uf2_file()`, que produce bloques UF2 de 256 bytes dirigidos a la dirección de flash de la Pico `0x10000000`.

## Heurística de detección de mapper
- `detect_rom_type()` implementa una combinación de comprobaciones de firma (cabecera "AB", etiquetas `ROM_NEO8` / `ROM_NE16`) y escaneo heurístico de códigos de operación y direcciones para elegir mappers comunes de MSX, incluyendo (pero no limitado a):
  - Plain 16KB (byte de mapper 1) — comprobación de cabecera AB de 16KB
  - Plain 32KB (byte de mapper 2) — comprobación de cabecera AB de 32KB
  - Mapper Linear0 (byte de mapper 4) — comprobación de diseño AB especial
  - NEO8 (byte de mapper 8) y NEO16 (byte de mapper 9)
  - Konami, Konami SCC, ASCII8, ASCII16 y otros mediante puntuación ponderada
- Si no se puede detectar de forma fiable ningún mapper, la herramienta omite la ROM e informa "mapper no compatible". Recuerde que puede forzar un mapper mediante una etiqueta en el nombre del archivo. Las etiquetas no distinguen entre mayúsculas y minúsculas y se enumeran a continuación.
- Solo se admiten los siguientes mappers en el área de configuración y el menú: `PL-16, PL-32, KonSCC, Linear, ASC-08, ASC-16, Konami, NEO-8, NEO-16`

## Uso del menú Selector de ROM de MSX

Cuando enciende el MSX con el cartucho PicoVerse 2040 insertado, aparece el menú MultiROM, mostrando la lista de ROMs disponibles. Puede navegar por el menú usando las teclas de flecha del teclado.



Use las teclas de flecha Arriba y Abajo para mover el cursor de selección a través de la lista de ROMs. Si tiene más de 19 ROMs, use las teclas de flecha laterales (Izquierda y Derecha) para desplazarse por las páginas de entradas.

Presione la tecla Enter o Espacio para lanzar la ROM seleccionada. El MSX intentará arrancar la ROM usando los ajustes de mapper apropiados.

En cualquier momento mientras esté en el menú, puede presionar la tecla H para leer la pantalla de ayuda con instrucciones básicas. Presione cualquier tecla para volver al menú principal.

## Uso de Nextor con el cartucho PicoVerse 2040

La opción -n de la herramienta multirom incluye una ROM Nextor integrada experimental que se puede usar en modelos específicos de MSX2. Sin embargo, esta opción aún está en desarrollo y puede no funcionar en todos los sistemas. Esta versión utiliza un método diferente (basado en puertos de E/S) para comunicarse con el MSX, lo que le permite funcionar en sistemas donde la ranura del cartucho no es primaria, por ejemplo con expansores de ranuras.

Se pueden encontrar más detalles sobre el protocolo utilizado para comunicarse con el ordenador MSX en el documento Nextor-Pico-Bridge-Protocol.md. 

### Cómo preparar una memoria USB para Nextor

Para preparar una memoria USB para su uso con Nextor en el cartucho PicoVerse 2040, siga estos pasos:

1. Conecte la memoria USB a su PC.
2. Cree una partición FAT16 de 4 GB como máximo en la memoria USB. Puede usar la herramienta integrada de Nextor OS (CALL FDISK mientras está en MSX Basic) o software de particionamiento de terceros para hacer esto.
3. Copie los archivos del sistema Nextor al directorio raíz de la partición FAT16. Puede obtener los archivos del sistema Nextor de la distribución o repositorio oficial de Nextor. También necesita el archivo COMMAND2 para el intérprete de comandos:
   1. [Página de descarga de Nextor](https://github.com/Konamiman/Nextor/releases)
   2. [Página de descarga de Command2](http://www.tni.nl/products/command2.html)
4. Copie cualquier ROM de MSX (archivos `.ROM`) o imágenes de disco (archivos `.DSK`) que desee usar con Nextor al directorio raíz de la memoria USB.
5. Instale SofaRun o cualquier otro lanzador compatible con Nextor en la memoria USB si planea usarlo para lanzar ROMs y DSKs. Puede descargar SofaRun de su fuente oficial aquí: [SofaRun](https://www.louthrax.net/mgr/sofarun.html)
6. Expulse de forma segura la memoria USB de su PC.
7. Conecte la memoria USB al cartucho PicoVerse 2040 usando un adaptador o cable USB OTG si es necesario.

> **Nota:** No todas las memorias USB son compatibles con el cartucho PicoVerse 2040. Si encuentra problemas, intente usar una marca o modelo diferente de memoria USB.
>
> **Nota:** Recuerde que Nextor necesita un mínimo de 128 KB de RAM para funcionar.

## Ideas de mejoras
- Mejorar la heurística de detección del tipo de ROM para cubrir más mappers y casos límite.
- Implementar una pantalla de configuración para cada entrada de ROM (nombre, anulación de mapper, etc.).
- Añadir soporte para más mappers de ROM.
- Implementar un menú gráfico con mejor navegación y visualización de información de la ROM.
- Añadir soporte para guardar/cargar la configuración del menú para preservar las preferencias del usuario.
- Soportar también archivos DSK, con las entradas de configuración adecuadas.
- Añadir soporte para temas personalizados para el menú.
- Permitir la descarga de ROMs desde URLs de Internet e incrustarlas directamente.
- Permitir el uso del joystick para navegar por el menú.

## Problemas conocidos

- La inclusión de la ROM Nextor integrada es todavía experimental y puede no funcionar en todos los modelos de MSX2.
- Algunas ROMs con mappers poco comunes pueden no detectarse correctamente y se omitirán a menos que se use una etiqueta de mapper válida para forzar la detección.
- La herramienta MultiROM actualmente solo es compatible con Windows. Las versiones para Linux y macOS aún no están disponibles.
- Actualmente, la herramienta no valida la integridad de los archivos ROM más allá del tamaño y las comprobaciones básicas de cabecera. Las ROMs corruptas pueden provocar un comportamiento inesperado.
- Debido a la naturaleza de la herramienta MultiROM (incrustar múltiples archivos en un solo UF2), algunos programas antivirus pueden marcar el ejecutable como sospechoso. Esto es un falso positivo; asegúrese de descargar la herramienta de una fuente de confianza.
- El menú MultiROM no admite archivos DSK; solo se enumeran y lanzan archivos ROM.
- Actualmente, la herramienta no admite subdirectorios; solo se procesan los archivos ROM en el directorio de trabajo actual.
- La memoria flash de la pico puede desgastarse después de muchos ciclos de escritura. Evite el flasheo excesivo del cartucho.

## Modelos de MSX probados

El cartucho PicoVerse 2040 con firmware MultiROM ha sido probado en los siguientes modelos de MSX:

| Modelo | Tipo | Estado | Comentarios |
| --- | --- | --- | --- |
| Adermir Carchano Expert 4 | MSX2+ | OK | Funcionamiento verificado |
| Gradiente Expert | MSX1 | OK | Funcionamiento verificado |
| JFF MSX | MSX1 | OK | Funcionamiento verificado |
| MSX Book | MSX2+ (clon FPGA) | OK | Funcionamiento verificado |
| MSX One | MSX1 | No OK | Cartucho no reconocido |
| National FS-4500 | MSX1 | OK | Funcionamiento verificado |
| Omega MSX | MSX2+ | OK | Funcionamiento verificado |
| Panasonic FS-A1GT | TurboR | OK | Funcionamiento verificado |
| Panasonic FS-A1ST | TurboR | OK | Funcionamiento verificado |
| Panasonic FS-A1WX | MSX2+ | OK | Funcionamiento verificado |
| Panasonic FS-A1WSX | MSX2+ | OK | Funcionamiento verificado |
| Sharp HotBit HB8000 | MSX1 | OK | Funcionamiento verificado |
| SMX-HB | MSX2+ (clon FPGA) | OK | Funcionamiento verificado |
| Sony HB-F1XD | MSX2 | OK | Funcionamiento verificado |
| Sony HB-F1XDJ | MSX2 | OK | Funcionamiento verificado |
| Sony HB-F1XV | MSX2+ | OK | Funcionamiento verificado |
| TRHMSX | MSX2+ (clon FPGA) | OK | Funcionamiento verificado |
| uMSX | MSX2+ (clon FPGA) | OK | Funcionamiento verificado |
| Yamaha YIS604 | MSX1 | OK | Funcionamiento verificado |

La ROM Nextor integrada experimental (opción `-n`) ha sido probada en los siguientes modelos de MSX:

| Modelo | Tipo | Estado | Comentarios |
| --- | --- | --- | --- |
| Omega MSX | MSX2+ | No OK | USB no detectado |
| Sony HB-F1XD | MSX2 | No OK | Error al leer sector de disco |
| TRHMSX | MSX2+ (clon FPGA) | OK | Funcionamiento verificado |
| uMSX | MSX2+ (clon FPGA) | OK | Funcionamiento verificado |

Autor: Cristiano Almeida Goncalves
Última actualización: 25/12/2025

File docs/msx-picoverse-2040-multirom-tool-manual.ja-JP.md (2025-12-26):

# MSX PicoVerse 2040 プロジェクト

|PicoVerse 前面|PicoVerse 背面|
|---|---|
|PicoVerse 前面|PicoVerse 背面|

PicoVerse 2040 は、Raspberry Pi Pico をベースにした MSX 用カートリッジで、交換可能なファームウェアを使用してコンピュータの機能を拡張します。さまざまなファームウェアイメージをロードすることで、カートリッジは MSX のゲームやアプリケーションを実行したり、追加のハードウェアデバイス（ROM マッパー、追加 RAM、ストレージインターフェースなど）をエミュレートしたりすることができ、実質的に MSX に仮想周辺機器を追加します。そのようなファームウェアの 1 つが MultiROM システムで、カートリッジに保存された複数の ROM タイトルを閲覧および起動するための画面上メニューを提供します。

また、カートリッジは Pico の USB-C ポートをマスストレージデバイスとして公開できるため、Windows または Linux を搭載した PC から ROM、DSK、その他のファイルをカートリッジに直接コピーできます。

PicoVerse 2040 カートリッジの現在のバージョンで利用可能な機能は次のとおりです。

* MSX ROM を選択して起動するための MultiROM メメニューシステム。
* Nextor OS サポート付きのインラインメニューオプション。
* ROM および DSK をロードするための USB マスストレージデバイスのサポート。
* さまざまな MSX ROM マッパーのサポート（PL-16, PL-32, KonSCC, Linear, ASC-08, ASC-16, Konami, NEO-8, NEO-16）。
* MSX、MSX2、および MSX2+ システムとの互換性。

## MultiROM UF2 クリエーターマニュアル

このセクションでは、PicoVerse 2040 カートリッジをプログラムする UF2 イメージ（`multirom.uf2`）を生成するために使用される `multirom` コンソールツールについて説明します。

デフォルトの動作では、`multirom` ツールはディレクトリ内の MSX ROM ファイルをスキャンし、それらを Raspberry Pi Pico にフラッシュできる単一の UF2 イメージにパッケージ化します。結果のイメージには通常、Pico ファームウェア、MultiROM MSX メニュー ROM、各 ROM エントリを記述する構成領域、および ROM ペイロード自体が含まれています。

> **注意:** 1 つのイメージに含めることができる ROM は最大 128 個で、合計サイズ制限は約 16 MB です。

提供されるオプションに応じて、`multirom` は MultiROM メニューの代わりにカスタムファームウェアに直接起動する UF2 イメージを生成することもできます。たとえば、Nextor OS を実装するファームウェアを含む UF2 ファイルを生成するためにオプションを使用できます。このモードでは、Pico の USB-C ポートを、Nextor から（たとえば SofaRun 経由で）ROM、DSK、およびその他のファイルをロードするためのマスストレージデバイスとして使用できます。

## 概要

オプションなしで実行された場合、`multirom.exe` ツールは現在の作業ディレクトリで MSX ROM ファイル（`.ROM` または `.rom`）をスキャンし、各 ROM を分析してマッパータイプを推測し、各 ROM を記述する構成テーブル（名前、マッパーバイト、サイズ、オフセット）を作成し、このテーブルを MSX メニュー ROM スライスに埋め込みます。次に、ツールは Pico ファームウェアバイナリ、メニュースライス、構成領域、および ROM ペイロードを連結し、イメージ全体を `multirom.uf2` という名前の UF2 ファイルにシリアル化します。



UF2 ファイル（通常は multirom.uf2）は、結合されたイメージをフラッシュするために Pico の USB マスストレージデバイスにコピーできます。UF2 フラッシュモードに入るには、BOOTSEL ボタンを押しながら Pico を接続する必要があります。すると、`RPI-RP2` という名前の新しい USB ドライブが表示され、そこに `multirom.uf2` をコピーできます。コピーが完了したら、Pico を取り外してカートリッジを MSX に挿入し、MultiROM メニューを起動できます。

ROM ファイル名は、MSX メニューのエントリ名として使用されます。名前の制限は 50 文字です。MSX メニューで長い名前を表示するためにローリング効果が使用されますが、名前が 50 文字を超えると切り捨てられます。



> **注意:** USB メモリを使用するには、OTG アダプタまたはケーブルが必要になる場合があります。これを使用して、USB-C ポートを標準の USB-A メスポートに変換できます。

> **注意:** `-n` オプションには、特定の MSX2 モデルで動作する実験的な組み込み Nextor ROM が含まれています。このバージョンは異なる通信方法（IO ポートベース）を使用しており、すべてのシステムで動作するとは限りません。

## コマンドラインの使用法

現在は Microsoft Windows 用の実行ファイル（`multirom.exe`）のみが提供されています。

### 基本的な使用法:

```
multirom.exe [オプション]
```

### オプション:
- `-n`, `--nextor` : 構成および出力からベータ版の組み込み NEXTOR ROM を含めます。このオプションはまだ実験的であり、現時点では特定の MSX2 モデルでのみ動作します。
- `-h`, `--help`   : 使用方法のヘルプを表示して終了します。
- `-o <ファイル名>`, `--output <ファイル名>` : UF2 出力ファイル名を設定します（デフォルトは `multirom.uf2`）。
- ROM ファイルに対して特定のマッパータイプを強制する必要がある場合は、ファイル名の `.ROM` 拡張子の前にマッパータグを追加できます。タグは大文字と小文字を区別しません。たとえば、ファイル名を `Knight Mare.PL-32.ROM` とすると、その ROM に対して PL-32 マッパーの使用が強制されます。`SYSTEM` などのタグは無視されます。使用可能なタグのリストは次のとおりです: `PL-16, PL-32, KonSCC, Linear, ASC-08, ASC-16, Konami, NEO-8, NEO-16`

### 例
- 現在のディレクトリにあるすべての `.ROM` ファイルと MultiROM メニューを含む multirom.uf2 ファイルを生成します。コマンドプロンプトを使用するか、実行ファイルをダブルクリックするだけでツールを実行できます。
  ```
  multirom.exe
  ```

## 仕組み（ハイレベル）

1. ツールは現在の作業ディレクトリで `.ROM` または `.rom` で終わるファイルをスキャンします。各ファイルについて：
   - 表示名（拡張子なしのファイル名、50 文字に切り捨て）を抽出します。
   - ファイルサイズを取得し、それが `MIN_ROM_SIZE` と `MAX_ROM_SIZE` の間であることを確認します。
   - `detect_rom_type()` を呼び出して、構成エントリで使用するマッパーバイトをヒューリスティックに決定します。ファイル名にマッパータグが存在する場合、それは検出を上書きします。
   - マッパーの検出に失敗した場合、ファイルはスキップされます。
   - ROM ごとの構成レコード（50 バイトの名前、1 バイトのマッパー、4 バイトのサイズ LE、4 バイトのフラッシュオフセット LE）を構成領域にシリアル化します。
2. スキャン後、ツールは（順番に）組み込み Pico ファームウェアバイナリ、MSX メニュー ROM の先頭スライス（`MENU_COPY_SIZE` バイト）、完全な構成領域（`CONFIG_AREA_SIZE` バイト）、オプションの NEXTOR ROM、そして発見された順序で ROM ペイロードを連結します。
3. 結合されたペイロードは、Pico フラッシュアドレス `0x10000000` をターゲットとした 256 バイトのペイロード UF2 ブロックを生成する `create_uf2_file()` を使用して、`multirom.uf2` という名前の UF2 ファイルとして書き込まれます。

## マッパー検出ヒューリスティック
- `detect_rom_type()` は、シグネチャチェック（"AB" ヘッダー、`ROM_NEO8` / `ROM_NE16` タグ）と、一般的な MSX マッパーを選択するためのオペコードおよびアドレスのヒューリスティックなスキャンの組み合わせを実装しています。これには以下が含まれます（ただしこれらに限定されません）：
  - プレーン 16KB（マッパーバイト 1） — 16KB AB ヘッダーチェック
  - プレーン 32KB（マッパーバイト 2） — 32KB AB ヘッダーチェック
  - Linear0 マッパー（マッパーバイト 4） — 特殊な AB レイアウトチェック
  - NEO8（マッパーバイト 8）および NEO16（マッパーバイト 9）
  - Konami, Konami SCC, ASCII8, ASCII16 など（加重スコアリングによる）
- マッパーを確実に検出できない場合、ツールは ROM をスキップし、「サポートされていないマッパー」と報告します。ファイル名タグを介してマッパーを強制できることを忘れないでください。タグは大文字と小文字を区別せず、以下にリストされています。
- 構成領域とメニューでは、次のマッパーのみがサポートされています: `PL-16, PL-32, KonSCC, Linear, ASC-08, ASC-16, Konami, NEO-8, NEO-16`
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

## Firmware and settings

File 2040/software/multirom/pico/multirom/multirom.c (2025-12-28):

// MSX PICOVERSE PROJECT
// (c) 2025 Cristiano Goncalves
// The Retro Hacker
//
// multirom.c - This is the Raspberry Pico firmware that will be used to load ROMs into the MSX
//
// This firmware is responsible for loading the multirom menu and the ROMs selected by the user into the MSX. When flashed through the 
// multirom tool, it will be stored on the pico flash memory followed by the MSX MENU ROM (with the config) and all the ROMs processed by the 
// multirom tool. The sofware in this firmware will load the first 32KB ROM that contains the menu into the MSX and it will allow the user
// to select a ROM to be loaded into the MSX. The selected ROM will be loaded into the MSX and the MSX will be reseted to run the selected ROM.
//
// This work is licensed  under a "Creative Commons Attribution-NonCommercial-ShareAlike 4.0 International
// License". https://creativecommons.org/licenses/by-nc-sa/4.0/

#include <stdio.h>
#include <string.h>
#include "pico/stdlib.h"
#include "pico/multicore.h"
#include "hardware/clocks.h"
#include "hardware/structs/watchdog.h"
#include "hardware/watchdog.h"
#include "hardware/regs/addressmap.h"
#include "hardware/regs/m0plus.h"

#include "multirom.h"
#include "nextor.h"

// config area and buffer for the ROM data
#define ROM_NAME_MAX    50          // Maximum size of the ROM name
#define MAX_ROM_RECORDS 128         // Maximum ROM files supported
#define ROM_RECORD_SIZE (ROM_NAME_MAX + 1 + (sizeof(uint32_t) * 2)) // Name + mapper + size + offset
#define MONITOR_ADDR    (0x8000 + (ROM_RECORD_SIZE * MAX_ROM_RECORDS) + 1) // Monitor ROM address within image (currently 0x9D81)
#define CACHE_SIZE      196608     // 192KB cache size for ROM data

// This symbol marks the end of the main program in flash.
// Custom data starts right after it
extern unsigned char __flash_binary_end;

// SRAM buffer to cache ROM data
static uint8_t rom_sram[CACHE_SIZE];
static uint32_t active_rom_size = 0;

//pointer to the custom data
const uint8_t *rom = (const uint8_t *)&__flash_binary_end;

// Structure to represent a ROM record
// The ROM record will contain the name of the ROM, the mapper code, the size of the ROM and the offset in the flash memory
// Name: ROM_NAME_MAX bytes
// Mapper: 1 byte
// Size: 4 bytes
// Offset: 4 bytes
typedef struct {
    char Name[ROM_NAME_MAX];
    unsigned char Mapper;
    unsigned long Size;
    unsigned long Offset;
} ROMRecord;

ROMRecord records[MAX_ROM_RECORDS]; // Array to store the ROM records

// Initialize GPIO pins
static inline void setup_gpio()
{
    // address pins
    gpio_init(PIN_A0);  gpio_set_dir(PIN_A0, GPIO_IN);
    gpio_init(PIN_A1);  gpio_set_dir(PIN_A1, GPIO_IN);
    gpio_init(PIN_A2);  gpio_set_dir(PIN_A2, GPIO_IN);
    gpio_init(PIN_A3);  gpio_set_dir(PIN_A3, GPIO_IN);
    gpio_init(PIN_A4);  gpio_set_dir(PIN_A4, GPIO_IN);
    gpio_init(PIN_A5);  gpio_set_dir(PIN_A5, GPIO_IN);
    gpio_init(PIN_A6);  gpio_set_dir(PIN_A6, GPIO_IN);
    gpio_init(PIN_A7);  gpio_set_dir(PIN_A7, GPIO_IN);
    gpio_init(PIN_A8);  gpio_set_dir(PIN_A8, GPIO_IN);
    gpio_init(PIN_A9);  gpio_set_dir(PIN_A9, GPIO_IN);
    gpio_init(PIN_A10); gpio_set_dir(PIN_A10, GPIO_IN);
    gpio_init(PIN_A11); gpio_set_dir(PIN_A11, GPIO_IN);
    gpio_init(PIN_A12); gpio_set_dir(PIN_A12, GPIO_IN);
    gpio_init(PIN_A13); gpio_set_dir(PIN_A13, GPIO_IN);
    gpio_init(PIN_A14); gpio_set_dir(PIN_A14, GPIO_IN);
    gpio_init(PIN_A15); gpio_set_dir(PIN_A15, GPIO_IN);

    // data pins
    gpio_init(PIN_D0); 
    gpio_init(PIN_D1); 
    gpio_init(PIN_D2); 
    gpio_init(PIN_D3); 
    gpio_init(PIN_D4); 
    gpio_init(PIN_D5); 
    gpio_init(PIN_D6);  
    gpio_init(PIN_D7); 

    // Initialize control pins as input
    gpio_init(PIN_RD); gpio_set_dir(PIN_RD, GPIO_IN);
    gpio_init(PIN_WR); gpio_set_dir(PIN_WR, GPIO_IN);
    gpio_init(PIN_IORQ); gpio_set_dir(PIN_IORQ, GPIO_IN);
    gpio_init(PIN_SLTSL); gpio_set_dir(PIN_SLTSL, GPIO_IN);
}

// read_ulong - Read a 4-byte value from the memory area
// This function will read a 4-byte value from the memory area pointed by ptr and return the value as an unsigned long
// Parameters:
//   ptr - Pointer to the memory area to read the value from
// Returns:
//   The 4-byte value as an unsigned long 
unsigned long read_ulong(const unsigned char *ptr) {
    return (unsigned long)ptr[0] |
           ((unsigned long)ptr[1] << 8) |
           ((unsigned long)ptr[2] << 16) |
           ((unsigned long)ptr[3] << 24);
}

// isEndOfData - Check if the memory area is the end of the data
// This function will check if the memory area pointed by memory is the end of the data. The end of the data is defined by all bytes being 0xFF.
// Parameters:
//   memory - Pointer to the memory area to check
// Returns:
//   1 if the memory area is the end of the data, 0 otherwise
int isEndOfData(const unsigned char *memory) {
    for (int i = 0; i < ROM_RECORD_SIZE; i++) {
        if (memory[i] != 0xFF) {
            return 0;
        }
    }
    return 1;
}

//load the MSX Menu ROM into the MSX
int __no_inline_not_in_flash_func(loadrom_msx_menu)(uint32_t offset)
{

    //setup the rom_sram buffer for the 32KB ROM
    gpio_init(PIN_WAIT); // Init wait signal pin
    gpio_set_dir(PIN_WAIT, GPIO_OUT); // Set the WAIT signal as output
    gpio_put(PIN_WAIT, 0); // Wait until we are ready to read the ROM
    memset(rom_sram, 0, 32768); // Clear the SRAM buffer
    memcpy(rom_sram, rom + offset, 32768); //for 32KB ROMs we start at 0x4000
    gpio_put(PIN_WAIT, 1); // Lets go!

    int record_count = 0; // Record count
    const uint8_t *record_ptr = rom + offset + 0x4000; // Pointer to the ROM records
    for (int i = 0; i < MAX_ROM_RECORDS; i++)      // Read the ROMs from the configuration area
    {
        if (isEndOfData(record_ptr)) {
            break; // Stop if end of data is reached
        }
        memcpy(records[record_count].Name, record_ptr, ROM_NAME_MAX); // Copy the ROM name
        record_ptr += ROM_NAME_MAX; // Move the pointer to the next field
        records[record_count].Mapper = *record_ptr++; // Read the mapper code
        records[record_count].Size = read_ulong(record_ptr); // Read the ROM size
        record_ptr += sizeof(unsigned long); // Move the pointer to the next field
        records[record_count].Offset = read_ulong(record_ptr); // Read the ROM offset
        record_ptr += sizeof(unsigned long); // Move the pointer to the next record
        record_count++; // Increment the record count
    }

    uint8_t rom_index = 0;
    gpio_set_dir_in_masked(0xFF << 16); // Set data bus to input mode
    bool rom_selected = false; // ROM selected flag
    while (true)  // Loop until a ROM is selected
    {
        // Check control signals
        bool sltsl = !(gpio_get(PIN_SLTSL)); // Slot selected (active low)
        bool rd = !(gpio_get(PIN_RD));       // Read cycle (active low)
        bool wr = !(gpio_get(PIN_WR));       // Write cycle (active low, not used)
        
        uint16_t addr = gpio_get_all() & 0x00FFFF; // Read the address bus
        if (sltsl) 
        {
            if (addr >= 0x4000 && addr <= 0xBFFF) // Check if the address is within the ROM range
            {
                if (rd)
                {
                    gpio_set_dir_out_masked(0xFF << 16); // Set data bus to output mode
                    uint32_t rom_addr = offset + (addr - 0x4000); // Calculate flash address
                    //gpio_put_masked(0xFF0000, rom[rom_addr] << 16); // Write the data to the data bus
                    gpio_put_masked(0xFF0000, rom_sram[rom_addr] << 16); // Write the data to the data bus
                    while (!(gpio_get(PIN_RD))) { // Wait until the read cycle completes (RD goes high)
                        tight_loop_contents();
                    }
                    gpio_set_dir_in_masked(0xFF << 16); // Set data bus to input mode
                }
                if (wr && addr == MONITOR_ADDR) // Monitor ROM address from configuration table
                {   
                    rom_index = (gpio_get_all() >> 16) & 0xFF;
                    while (!(gpio_get(PIN_WR))) { // Wait until the write cycle completes (WR goes high){
                        tight_loop_contents();
                    }
                    gpio_set_dir_in_masked(0xFF << 16); // Set data bus to input mode
                    rom_selected = true;    // ROM selected
                }
            } 
        }
        if (rd && addr == 0x0000 && rom_selected)   // lets return the rom_index and load the selected ROM
        {
            return rom_index;
        }
    }
}

// loadrom_plain32 - Load a simple 32KB (or less) ROM into the MSX directly from the pico flash
// 32KB ROMS have two pages of 16Kb each in the following areas:
// 0x4000-0x7FFF and 0x8000-0xBFFF
// AB is on 0x0000, 0x0001
// 16KB ROMS have only one page in the 0x4000-0x7FFF area
// AB is on 0x0000, 0x0001
void __no_inline_not_in_flash_func(loadrom_plain32)(uint32_t offset, bool cache_enable)
{
    const uint8_t *rom_base = rom + offset;

    if (cache_enable)
    {
        gpio_init(PIN_WAIT);
        gpio_set_dir(PIN_WAIT, GPIO_OUT);
        gpio_put(PIN_WAIT, 0);
        memset(rom_sram, 0, 32768);
        memcpy(rom_sram, rom_base, 32768);
        gpio_put(PIN_WAIT, 1);
        rom_base = rom_sram;
    }

    gpio_set_dir_in_masked(0xFF << 16);
    while (true)
    {
        if (!gpio_get(PIN_SLTSL))
        {
            uint16_t addr = gpio_get_all() & 0x00FFFF;
            if ((addr >= 0x4000) && (addr <= 0xBFFF) && !gpio_get(PIN_RD))
            {
                uint8_t data = rom_base[addr - 0x4000];
                gpio_set_dir_out_masked(0xFF << 16);
                gpio_put_masked(0xFF0000, (uint32_t)data << 16);
                while (!gpio_get(PIN_RD))
                    tight_loop_contents();
                gpio_set_dir_in_masked(0xFF << 16);
            }
        }
    }
}

// loadrom_linear48 - Load a simple 48KB Linear0 ROM into the MSX directly from the pico flash
// Those ROMs have three pages of 16Kb each in the following areas:
// 0x0000-0x3FFF, 0x4000-0x7FFF and 0x8000-0xBFFF
// AB is on 0x4000, 0x4001
void __no_inline_not_in_flash_func(loadrom_linear48)(uint32_t offset, bool cache_enable)
{
    const uint8_t *rom_base = rom + offset;

    if (cache_enable)
    {
        gpio_init(PIN_WAIT);
        gpio_set_dir(PIN_WAIT, GPIO_OUT);
        gpio_put(PIN_WAIT, 0);
        memset(rom_sram, 0, 49152);
        memcpy(rom_sram, rom_base, 49152);
        gpio_put(PIN_WAIT, 1);
        rom_base = rom_sram;
    }
    
    gpio_set_dir_in_masked(0xFF << 16); // Set data bus to input mode
    while (true) 
    {
        if (!gpio_get(PIN_SLTSL))
        {
            uint16_t addr = gpio_get_all() & 0x00FFFF; // Read the address bus
            if ((addr >= 0x0000) && (addr <= 0xBFFF) && !gpio_get(PIN_RD)) // Check if the address is within the ROM range
            {
                uint8_t data = rom_base[addr];
                gpio_set_dir_out_masked(0xFF << 16);
                gpio_put_masked(0xFF0000, (uint32_t)data << 16);
                while (!gpio_get(PIN_RD))
                    tight_loop_contents();
                gpio_set_dir_in_masked(0xFF << 16);
            }
        }
    }
}

// loadrom_konamiscc - Load a any Konami SCC ROM into the MSX directly from the pico flash
// The KonamiSCC ROMs are divided into 8KB segments, managed by a memory mapper that allows dynamic switching of these segments 
// into the MSX's address space. Since the size of the mapper is 8Kb, the memory banks are:
// Bank 1: 4000h - 5FFFh , Bank 2: 6000h - 7FFFh, Bank 3: 8000h - 9FFFh, Bank 4: A000h - BFFFh
// And the address to change banks are:
// Bank 1: 5000h - 57FFh (5000h used), Bank 2: 7000h - 77FFh (7000h used), Bank 3: 9000h - 97FFh (9000h used), Bank 4: B000h - B7FFh (B000h used)
// AB is on 0x0000, 0x0001
void __no_inline_not_in_flash_func(loadrom_konamiscc)(uint32_t offset, bool cache_enable)
{
    uint8_t bank_registers[4] = {0, 1, 2, 3}; // Initial banks 0-3 mapped
    uint32_t cached_length = 0;

    if (cache_enable)
    {
        gpio_init(PIN_WAIT);
        gpio_set_dir(PIN_WAIT, GPIO_OUT);
        gpio_put(PIN_WAIT, 0);

        uint32_t bytes_to_cache = active_rom_size;
        if (bytes_to_cache == 0 || bytes_to_cache > sizeof(rom_sram))
        {
            bytes_to_cache = sizeof(rom_sram);
        }

        memset(rom_sram, 0, bytes_to_cache);
        memcpy(rom_sram, rom + offset, bytes_to_cache);
        gpio_put(PIN_WAIT, 1);
        cached_length = bytes_to_cache;
    }

    gpio_set_dir_in_masked(0xFF << 16); // Set data bus to input mode
    while (true) 
    {
        // Check control signals
        bool sltsl = !(gpio_get(PIN_SLTSL)); // Slot selected (active low)
        bool rd = !(gpio_get(PIN_RD));       // Read cycle (active low)
        bool wr = !(gpio_get(PIN_WR));       // Write cycle (active low)

        if (sltsl)
        {
            uint16_t addr = gpio_get_all() & 0x00FFFF; // Read the address bus
            if (addr >= 0x4000 && addr <= 0xBFFF)  // Check if the address is within the ROM range
            {
                if (rd) 
                {
                    gpio_set_dir_out_masked(0xFF << 16); // Set data bus to output mode
                    uint32_t const rom_offset = offset + (bank_registers[(addr - 0x4000) >> 13] * 0x2000u) + (addr & 0x1FFFu); // Calculate the ROM offset

                    uint8_t data;
                    uint32_t const relative_offset = (rom_offset >= offset) ? (rom_offset - offset) : cached_length;
                    if (cache_enable && relative_offset < cached_length)
                    {
                        data = rom_sram[relative_offset];
                    }
                    else
                    {
                        gpio_put(PIN_WAIT, 0);
                        data = rom[rom_offset];
                        gpio_put(PIN_WAIT, 1);
                    }

                    gpio_put_masked(0xFF0000, (uint32_t)data << 16); // Write the data to the data bus
                    while (!(gpio_get(PIN_RD)))  // Wait until the read cycle completes (RD goes high)
                    {
                        tight_loop_contents();
                    }
                    gpio_set_dir_in_masked(0xFF << 16); // Return data bus to input mode after cycle completes
                } else if (wr) 
                {
                    // Handle writes to bank switching addresses
                    if ((addr >= 0x5000)  && (addr <= 0x57FF)) { 
                        bank_registers[0] = (gpio_get_all() >> 16) & 0xFF; // Read the data bus and store in bank register
                    } else if ((addr >= 0x7000) && (addr <= 0x77FF)) {
                        bank_registers[1] = (gpio_get_all() >> 16) & 0xFF;
                    } else if ((addr >= 0x9000) && (addr <= 0x97FF)) {
                        bank_registers[2] = (gpio_get_all() >> 16) & 0xFF;
                    } else if ((addr >= 0xB000) && (addr <= 0xB7FF)) {
                        bank_registers[3] = (gpio_get_all() >> 16) & 0xFF;
                    }

                    while (!(gpio_get(PIN_WR)))
                    {
                        tight_loop_contents();
                    }
                }
            }
        }
    }
}

// loadrom_konami - Load a Konami (without SCC) ROM into the MSX directly from the pico flash
// The Konami (without SCC) ROM is divided into 8KB segments, managed by a memory mapper that allows dynamic switching of these segments into the MSX's address space
// Since the size of the mapper is 8Kb, the memory banks are:
//  Bank 1: 4000h - 5FFFh, Bank 2: 6000h - 7FFFh, Bank 3: 8000h - 9FFFh, Bank 4: A000h - BFFFh
// And the addresses to change banks are:
//	Bank 1: <none>, Bank 2: 6000h - 67FFh (6000h used), Bank 3: 8000h - 87FFh (8000h used), Bank 4: A000h - A7FFh (A000h used)
// AB is on 0x0000, 0x0001
void __no_inline_not_in_flash_func(loadrom_konami)(uint32_t offset, bool cache_enable)
{
    uint8_t bank_registers[4] = {0, 1, 2, 3}; // Initial banks 0-3 mapped
    uint32_t cached_length = 0;

    if (cache_enable)
    {
        gpio_init(PIN_WAIT);
        gpio_set_dir(PIN_WAIT, GPIO_OUT);
        gpio_put(PIN_WAIT, 0);

        uint32_t bytes_to_cache = active_rom_size;
        if (bytes_to_cache == 0 || bytes_to_cache > sizeof(rom_sram))
        {
            bytes_to_cache = sizeof(rom_sram);
        }

        memset(rom_sram, 0, bytes_to_cache);
        memcpy(rom_sram, rom + offset, bytes_to_cache);
        gpio_put(PIN_WAIT, 1);
        cached_length = bytes_to_cache;
    }

    gpio_set_dir_in_masked(0xFF << 16);
    while (true) 
    {
        // Check control signals
        bool sltsl = !(gpio_get(PIN_SLTSL)); // Slot selected (active low)
        bool rd = !(gpio_get(PIN_RD));       // Read cycle (active low)
        bool wr = !(gpio_get(PIN_WR));       // Write cycle (active low)

        if (sltsl)
        {
            uint16_t addr = gpio_get_all() & 0x00FFFF; // Read the address bus
            if (addr >= 0x4000 && addr <= 0xBFFF) 
            {
                if (rd) 
                {
                    gpio_set_dir_out_masked(0xFF << 16);
                    uint32_t const rom_offset = offset + (bank_registers[(addr - 0x4000) >> 13] * 0x2000u) + (addr & 0x1FFFu); // Calculate the ROM offset

                    uint8_t data;
                    uint32_t const relative_offset = (rom_offset >= offset) ? (rom_offset - offset) : cached_length;
                    if (cache_enable && relative_offset < cached_length)
                    {
                        data = rom_sram[relative_offset];
                    }
                    else
                    {
                        gpio_put(PIN_WAIT, 0);
                        data = rom[rom_offset];
                        gpio_put(PIN_WAIT, 1);
                    }

                    gpio_put_masked(0xFF0000, (uint32_t)data << 16);
                    while (!(gpio_get(PIN_RD))) 
                    {
                        tight_loop_contents();
                    }
                    gpio_set_dir_in_masked(0xFF << 16);

                }else if (wr) {
                    // Handle writes to bank switching addresses
                    if ((addr >= 0x6000) && (addr <= 0x67FF)) {
                        bank_registers[1] = (gpio_get_all() >> 16) & 0xFF;
                    } else if ((addr >= 0x8000) && (addr <= 0x87FF)) {
                        bank_registers[2] = (gpio_get_all() >> 16) & 0xFF;
                    } else if ((addr >= 0xA000) && (addr <= 0xA7FF)) {
                        bank_registers[3] = (gpio_get_all() >> 16) & 0xFF;
                    }

                    while (!(gpio_get(PIN_WR))) 
                    {
                        tight_loop_contents();
                    }
                }
            }
        }
    }
}
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
int main(void)
{
    set_sys_clock_khz(250000, true);     // Set system clock to 250MHz
    stdio_init_all();   // Initialize stdio
    setup_gpio();       // Initialize GPIO

    // Multicore setup
    // multicore_launch_core1(wireless_main); // Launch core 1
    // Load the ROM data from flash memory
    int rom_index = loadrom_msx_menu(0x0000); //load the first 32KB ROM into the MSX (The MSX PICOVERSE MENU)

    ROMRecord const *selected = &records[rom_index];
    active_rom_size = selected->Size;

    // Load the selected ROM into the MSX according to the mapper
    switch (selected->Mapper) {
        case 1:
        case 2:
            loadrom_plain32(selected->Offset, true);
            break;
        case 3:
            loadrom_konamiscc(selected->Offset, true);
            break;
        case 4:
            loadrom_linear48(selected->Offset, true);
            break;
        case 5:
            loadrom_ascii8(selected->Offset, true); 
            break;
        case 6:
            loadrom_ascii16(selected->Offset, true); 
            break;
        case 7:
            loadrom_konami(selected->Offset, true); 
            break;
        case 8:
            loadrom_neo8(selected->Offset); 
            break;
        case 9:
            loadrom_neo16(selected->Offset); 
            break;
        case 10:
            loadrom_nextor(selected->Offset); 
           break;
        default:
            printf("Debug: Unsupported ROM mapper: %d\n", selected->Mapper);
            break;
    }
    
}

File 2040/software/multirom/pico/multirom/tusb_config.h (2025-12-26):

/* 
 * The MIT License (MIT)
 *
 * Copyright (c) 2019 Ha Thach (tinyusb.org)
 *
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
 */

#ifndef _TUSB_CONFIG_H_
#define _TUSB_CONFIG_H_

#ifdef __cplusplus
 extern "C" {
#endif

//--------------------------------------------------------------------
// COMMON CONFIGURATION
//--------------------------------------------------------------------

// defined by compiler flags for flexibility
#ifndef CFG_TUSB_MCU
  #error CFG_TUSB_MCU must be defined
#endif

#if CFG_TUSB_MCU == OPT_MCU_LPC43XX || CFG_TUSB_MCU == OPT_MCU_LPC18XX || CFG_TUSB_MCU == OPT_MCU_MIMXRT10XX
  #define CFG_TUSB_RHPORT0_MODE       (OPT_MODE_HOST | OPT_MODE_HIGH_SPEED)
#else
  #define CFG_TUSB_RHPORT0_MODE       OPT_MODE_HOST
#endif

#ifndef CFG_TUSB_OS
#define CFG_TUSB_OS                 OPT_OS_NONE
#endif

// CFG_TUSB_DEBUG is defined by compiler in DEBUG build
// #define CFG_TUSB_DEBUG           0

/* USB DMA on some MCUs can only access a specific SRAM region with restriction on alignment.
 * Tinyusb use follows macros to declare transferring memory so that they can be put
 * into those specific section.
 * e.g
 * - CFG_TUSB_MEM SECTION : __attribute__ (( section(".usb_ram") ))
 * - CFG_TUSB_MEM_ALIGN   : __attribute__ ((aligned(4)))
 */
#ifndef CFG_TUSB_MEM_SECTION
#define CFG_TUSB_MEM_SECTION
#endif

#ifndef CFG_TUSB_MEM_ALIGN
#define CFG_TUSB_MEM_ALIGN          __attribute__ ((aligned(4)))
#endif

//--------------------------------------------------------------------
// CONFIGURATION
//--------------------------------------------------------------------

// Size of buffer to hold descriptors and other data used for enumeration
#define CFG_TUH_ENUMERATION_BUFSIZE 256

#define CFG_TUH_HUB                 1
#define CFG_TUH_CDC                 0
#define CFG_TUH_HID                 0 // typical keyboard + mouse device can have 3-4 HID interfaces
#define CFG_TUH_MIDI                0 // there will be at most one MIDIStreaming Interface descriptor
#define CFG_TUH_MSC                 1
#define CFG_TUH_VENDOR              0

// max device support (excluding hub device)
#define CFG_TUH_DEVICE_MAX          (CFG_TUH_HUB ? 4 : 1) // hub typically has 4 ports

//------------- HID -------------//
#define CFG_TUH_HID_EPIN_BUFSIZE    64
#define CFG_TUH_HID_EPOUT_BUFSIZE   64

#ifdef __cplusplus
 }
#endif

#endif /* _TUSB_CONFIG_H_ */

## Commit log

2025-12-20 Update hardware files for PicoVerse 2040 v1.3 release. Update README with BOM links.
2026-08-23 Release msx-picoverse-20260822
    PicoVerse 2040 Loadrom v2.62
    - Fixed lost bank-switch writes in every banked mapper loop (`banked8_loop` for Konami/Konami-SCC/ASCII8, plus ASCII16, ASCII16-X, Neo-8 and Neo-16). Those loops blocked on `pio_sm_get_blocking()` for the next cartridge read and only drained the memory write captor FIFO before and after it, so game code executing from MSX RAM that issued a burst of segment switches without any intervening cartridge read overflowed the 8-entry RX FIFO. The write state machine then stalled on `push block` and the extra switches were silently dropped, leaving the mapper register on a stale segment (and, with an ASCII16-X/Neo cache miss, forcing the ba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
    [loadrom.c, menu.h]
2026-08-25 Release msx-picoverse-20260825
    - Version bumped to v2.62 (top-level and tool Makefiles).
    PicoVerse 2350 Explorer v2.47
    - Bumped Explorer version to v2.47.
    - Fixed the per-ROM `Frequency` option having no effect on real hardware. v2.46 booted correctly but applied the refresh mode with a raw `out (#99),a` register write plus a manual `RG9SAV` (`#FFE8`) poke. That is enough in emulation but did not take effect on a real Panasonic FS-A1FX or Philips NMS 8245, where the game kept running at the machine's default rate.
    - Replaced the frequency fragment with the sequence the Carnivore2 boot menu uses, which is known to work on those machines: read the current `RG9SA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
    [menu.h]
2026-08-31 Release msx-picoverse-20260831
    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
    [menu.h]
2026-09-07 Release msx-picoverse-20260907
    PicoVerse 2350 Loadrom v2.75
    - Fixed OPL4/MoonSound images (`-4`, with or without `--22khz`) playing much quieter than the SCC, PSG and MSX-MUSIC audio profiles, which forced the amplifier or TV volume to be turned far up for an OPL4 game and back down again afterwards (reported with "Go Figure"). The YMF278B emulation core applies no output normalisation to this chip - upstream marks its YMF278B mixing as unverified - so the cartridge was running about 7 dB below the level the same hardware plays SCC/PSG music at. The final output stage now applies a 3x gain, which lines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
    [menu.h]
2026-09-18 Release msx-picoverse-20260917
    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
    [loadrom.c, menu.h]
2026-09-20 Release msx-picoverse-20260920
    PicoVerse 2350 Loadrom v2.77
    - Fixed the `.FLA` image being written to the microSD card empty, which left ASCII16-X FlashROM saves working only when a valid image happened to be there already. Creating the image was deferred until the MSX actually programmed the flash, and the file has to be opened with `FA_CREATE_ALWAYS`, which truncates it to zero straight away; the rest was then written only after the MSX had been quiet for a while. A game that saves and is then switched off left a zero-byte or partial file on the card, and because the restore path requires the file to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
    [menu.h]
2026-09-25 Release msx-picoverse-20260924
    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
    [menu.h]
2026-09-26 Release msx-picoverse-20260925
    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
    [menu.h]
2026-10-01 Release msx-picoverse-20261001
    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
    [loadrom.c, menu.h]
2026-10-03 Release msx-picoverse-20261003
    PicoVerse 2040 Loadrom v2.63
    - Version bumped to v2.63 (top-level and tool Makefiles).
    - `../tools/gen_romdb.py` now downloads the latest database by default from Vampier's ROM DB (`https://romdb.vampier.net/Archive/xml-msxromsdb.zip`) and reads `softwaredb.xml` from the zip in memory, so a local openMSX install is no longer needed. A local `softwaredb.xml` or `.zip` can still be passed as an argument for offline use. The generated header now records the source and the database timestamp. The script also accepts the `ASCII16-X` and lowercase `konami` mapper names used by this database.
    - Regenerated `tool/src/romdb.h` from the 2026-10-03 database: 3115 → 321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
    [loadrom.c, menu.h, multirom.c]
2026-10-04 Release msx-picoverse-20261004
    PicoVerse 2040 Multirom v2.66
    - openMSX add-on: `picoverse2040.tcl` now only takes over `.uf2` files inserted as ROM images when they are RP2040 images (family `0xE48BFF56`, or no family ID), via the new `is_rp2040_uf2()`. PicoVe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
    PicoVerse 2350 Explorer v2.57
    - Bumped Explorer version to v2.57 (Makefile, `msx/Makefile`, `tool/Makefile`) for copying microSD ROMs to flash.
    - Added **F - copy to flash**: in the `F2` microSD s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
2026-11-08 Release msx-picoverse-20261108
    PicoVerse 2040 MSXUSBFDD v1.01
    - Version bumped to v1.01 (top-level, `msx/` and `tool/` Makefiles, the tool's fallback `APP_VERSION`, and the firmware program version in `pico/msxusbfdd/CMakeLists.txt`, now `1.01`).
    - Moved the RP2040 firmware build from Pico SDK 2.2.0 to Pico SDK 2.3.1 (including its bundled TinyUSB), from the Arm GNU Toolchain 14.2.Rel1 to 15.2.Rel1 (GCC 15.2.1) and from picotool 2.2.0-a4 to 2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

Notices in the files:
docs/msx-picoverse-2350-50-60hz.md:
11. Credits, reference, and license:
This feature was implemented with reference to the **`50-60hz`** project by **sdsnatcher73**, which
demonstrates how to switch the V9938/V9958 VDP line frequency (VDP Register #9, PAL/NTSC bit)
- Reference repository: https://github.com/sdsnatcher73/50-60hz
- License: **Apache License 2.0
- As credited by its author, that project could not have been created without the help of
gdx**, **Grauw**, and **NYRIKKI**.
